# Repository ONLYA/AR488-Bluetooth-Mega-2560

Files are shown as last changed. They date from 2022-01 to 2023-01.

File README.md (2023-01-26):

View this project on [CADLAB.io](https://cadlab.io/project/26454). 

# AR488 Bluetooth Mega 2560
 Source code and KiCad PCB design files for AR488 with Arduino Mega 2560

This board is capable to communicate IEEE-488 protocol between the instrument and a PC. The communication can be with a USB cable or battery-power Bluetooth communication.
The firmware is from https://github.com/Twilight-Logic/AR488. Thanks to his help for this hardware project.

## Please do not use the previous two releases as they have wrong connection and will make your board not working.
Firmware is in folder `AR488-firmware`. The Schematic and PCB files are edited with KiCad 6. BOM is `AR488-Bluetooth-BOM.csv` (#todo)Gerber Files are compressed in `AR488-Gerber.zip`.

You can find the chips here: [SN75160BN](https://www.mouser.co.uk/ProductDetail/Texas-Instruments/SN75160BN?qs=Dqy2GfToSoSUifmRVz6Aqg%3D%3D) and [SN75161BN](https://www.mouser.co.uk/ProductDetail/Texas-Instruments/SN75161BN?qs=Dqy2GfToSoS%252BO4WL2FUX5A%3D%3D).

The GPIB connector I use: [112-024-213R001](https://www.mouser.co.uk/ProductDetail/NorComp/112-024-213R001?qs=IGgAdOvCTsR9oVdHJ26vTQ%3D%3D). Please note that this is a *female* connector, so you will need a GPIB male-male cable.

The Level Shifter (U3) was purchased from [here](https://www.amazon.co.uk/gp/product/B082F6BSB5/ref=ppx_yo_dt_b_asin_title_o09_s00?ie=UTF8&psc=1). It is currently out of stock. However, there are a lot of similar devices. I believed you can easily find an alternative.
The Bluetooth Module (J3) was purchased from [here](https://www.amazon.co.uk/gp/product/B0722MD4FY/ref=ppx_yo_dt_b_asin_title_o02_s00?ie=UTF8&psc=1). When connect it to J2, the attenna track should face upwards.

Connect either JP1 or JP2 to configure whether the DC pin of SN75161BN is connected to REN or Arduino D5. Default should connect JP2. If you want to connect DC-REN, please change that in the `AR488_config.h`.

Connect JP2, "0" side of JP3 and JP4 as the origin setup. You can change that accordingly with the `AR488_config.h`.

## UPDATE 202201311924
1. The connection to the GPIB connector is corrected. Please do not use the previous two releases as they have wrong connection and will make your board not working.
2. A battery circuit is added.
	- (!! DO NOT CONNECT BATTERY IF THE DEVICE IS POWER BY USB OR POWER JACK !!)
	- It accepts voltage range from 3V to 5V. Two AAA batteries are ideal. The SPDT switch will turn on the device.
	- A Boost Switching DC-DC IC (XC9141B50CMR-G)(U4) is used to power the arduino and device.
	- A comparator (U5)(MCP65R41T-1202E/CHY) is used to compare the battery voltage to the 1.21V reference voltage. When the battery voltage drops to the threshold voltage, the "BAT LOW" LED will turn on. The output `CE_OUT` will be driven to LOW.
	- The forward voltage of the "BAT LOW" LED should be less than 2.5V. Red, Amber or Yellow LED will work fine.
	- The potentialmeter is to control the voltage input to the comparator. Adjust it according to the battery specification. To adjust properly, connect a power supply to the `BAT+` input and adjust it to the drained battery voltage. Probe the test point TP1. Adjust RV1 until the voltage is 1.21V.
	- JP5 is the chip enable of the DC-DC IC. If it is connected to BATT, the chip will always be enabled. When connected to OUT, the chip will turn on according to the comparator output `CE_OUT`.

PCB images in KiCad 3D Viewer:
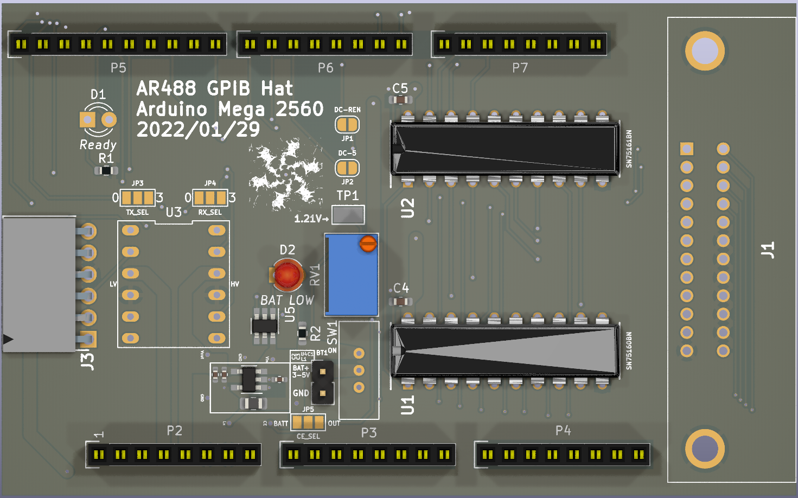
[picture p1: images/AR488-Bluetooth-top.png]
top


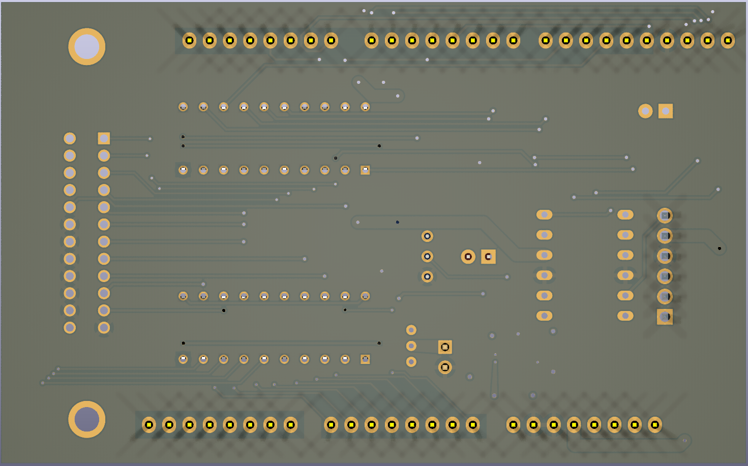
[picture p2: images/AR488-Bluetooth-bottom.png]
bottom


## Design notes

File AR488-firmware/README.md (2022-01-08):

# AR488 Arduino GPIB Interface

The AR488 GPIB controller is an Arduino-based controller for interfacing with IEEE488 GPIB devices via USB. This work was inspired by and has been based on the work originally released by Emanuele Girlando and has been released with his permission.

This sketch represents a rewrite of that work and implements the full set of Prologix ++ commands in both controller and device mode, with the exception of ++help. Secondary GPIB addressing is not yet supported. A number of additional features are provided, for example, a macro feature is provided to allow automation of frequently used command sequences was well as controller and instrument initialisation at startup. As of version 0.48.x, interfacing with SN75160 and SN75161 GPIB transceiver integrated circuits is supported.

To build an interface, at least one Arduino board will be required to act as the interface hardware. Arduinos provide a low cost alternative to other commercial interfaces. Currently the following boards are supported:

<table>
<tr><td><i>MCU</i></td><td><i>Board</i></td><td><i>Serial Ports</i></td><td><i>Layouts</i></td></tr>
<tr><td>328p</td><td>Uno R3</td><td>Single UART shared with USB</td><td>Layout as per original project by Emanuelle Girlando</td></tr>
<tr><td>328p</td><td>Nano</td><td>USB/Single UART shared with USB</td><td>Identical to Uno</td></tr>
<tr><td>32u4</td><td>Micro</td><td>USB/CDC+1 UART</td><td>Compact layout by Artag, designed for his back-of-IEEE488-plug adapter board</td></tr>
<tr><td>32u4</td><td>Leonardo R3</td><td>USB/CDC+1 UART</td><td>Identical to UNO</td></tr>
<tr><td>2560</td><td>Mega 2560</td><td>4 x UART, Serial0 shared with USB</td><td>D - (default) using pins on either side of board<br>E1 - using the first row of end connector<br>E2 - using the second row of end connector</td></tr>
</table>

Uno and Nano boards are both based around the ATmega328p micro-controller and have similar pin-out and features. Only two pins (6 & 13) remain spare as the remainder are all used to interface with the GPIB bus. The Micro and Leonardo are based around the ATmega32u4 micro-controller. On the Micro, all GPIO pins are used so none remain spare. The Leonardo R3 uses the same layout as the Uno leaving the same two pins (6 & 13) spare. The Mega 2560 costs slightly more but has a design and layout that includes considerably more control pins, additional serial ports and a more powerful ATmega2560 MCU. It therefore provides greater flexibility and potential for further expansion. Currently, 3 layouts are provided for the AtMega2650 using either the lower numbered pins on the sides of the board (<D>efault), the first row of pins of the two row header at the end of the board (E1), or the second row of the same header (E2). This provides some flexibility and allows various displays and other devices to be connected if desired. Please be aware that when using the <D>efault layout, pins 16 and 17 that correspond to TXD2 and RXD2 (Serial2) cannot be used for serial communication as they are used to drive GPIB signals, however serial ports 0, 1 and 3 remain available for use. Layouts E1 and E2 do not have the same restriction.

Including the SN7516x chipset into the interface design will naturally add to the cost, but has the advantage of providing the full 48mA drive current capacity regardless of the capability of the Arduino board being used, as well as providing proper tri-state output with Hi-Z when the board is powered down. The latter isolates the Arduino micro-controller from the GPIB bus when the interface is powered down, preventing GPIB bus communication problems due to 'parasitic power' from signals present on the GPIB bus, thereby allowing the interface to be safely powered down while not in use. Construction will involve adding a daughter-board between the Arduino GPIO pins and the GPIB bus. This could be constructed using prototyping board or shield, or custom designed using KiCad or other PCB layout design software.

To use the sketch, create a new directory, and then unpack the .zip file into this location. Open the main sketch, AR488.ino, in the Arduino IDE. This should also load all of the linked .h and .cpp files. Review Config.h and make any configuration adjustment required (see the 'Configuration' section of the AR488 manual for details), including the selcetion of the board layout selection appropriate to the Arduino board that you are using. Set the target board in Board Manager within the Arduino IDE (Tools => Board:), and then compile and upload the sketch. There should be no need to make any changes to any other files. Once uploaded, the firmware should respond to the ++ver command with its version information.

Please note that Arduino Micro (and other 32u4 boards, e.g. Leonardo) do not automatically reset when a connection is made to the serial port. The Arduino IDE takes care of the programming process via USB which should work normally. Some Micro boards may not have a reset button, in which case the reset pin need to be briefly shorted to ground by some other means. When using the Arduino IDE on Linux (Linux Mint and possibly other Ubuntu derivatives), the modemmanager service must be disabled, otherwise it will interfere with the programming process and the boards will be rendered inaccessible via USB. If this curers, then the board can be returned to normal working by uploading a bootloader to it using an AVR programmer. This issue does not seem to affect Uno, Nano or Mega 2560 boards.

Unless some form of shield or custom design with integral IEEE488 connector is used, connecting to an instrument will require a 16 core cable and a suitable IEEE488 connector. This can be salvaged from an old GPIB cable or purchased from various electronics parts suppliers. Searching for a 'centronics 24-way connector' sometimes yields better results than searching for 'IEEE 488 connector' or 'GPIB connector'. Details of interface construction and the mapping of Arduino pins to GPIB control signals and data bus are explained in the "Building an AR488 GPIB Interface" section of the <a href="https://github.com/Twilight-Logic/AR488/blob/master/AR488-manual.pdf">AR488 Manual</a>.
 
Commands generally adhere closely to the Prologix syntax, however there are some minor differences, additions and enhancements. For example, due to issues with longevity of the Arduino EEPROM memory, the ++savecfg command has been implemented differently to save EEPROM wear. Some commands have been enhanced with additional options and a number of new custom commands have been added to provide new features that are not found in the standard Prologix implementation. Details of all commands and features can be found in the Command Reference section of the <a href="https://github.com/Twilight-Logic/AR488/blob/master/AR488-manual.pdf">AR488 Manual</a>.

Once uploaded, the firmware should respond to the ++ver command with its version information.

<b><i>Wireless Communication:</i></b>

The 32u4 and mega 2560 boards have additional serial ports which can be used to connect the ESP8266 WiFi add-on or the HC05 bluetooth module. The firmware sketch supports auto-configuration of the Bluetooth HC05 module, the details of which can be found in the <a href="https://github.com/Twilight-Logic/AR488/blob/master/AR488-Bluetooth.pdf">AR488 Bluetooth Support</a> supplement. It is also possible to use a HC06 module, but since this module is capable of operating in slave mode only, automatic configuration is not possible. It will therefore need to be configured manually.

Using these wireless modules in conjunction with the Uno or Nano is not advised as the only available serial UART is also used for USB communication. Serial protocols were not designed to accomodate multiple devices on a single UART. Communication problems may arise when both USB and a serial device on RX0/TX0 are connected and communicating with the MCU at the same time. It is possible instead to use SoftwareSerial (TX = pin 6, RX = pin 13) although at a speed of no more than 57600 baud.

The ESP32 is not supported as yet, but work is progressing to add this to the list of supported boards.

<b><i>Obtaining support:</i></b>

In the event that a problem is found, this can be logged via the Issues feature on the AR488 GitHub page. Please provide at minimum:

- the firmware version number
- the type of board being used
- the make and model of instrument you are trying to control
- a description of the issue including;
- what steps are required to reproduce the issue

Comments and feedback can be provided here:<BR>
https://www.eevblog.com/forum/projects/ar488-arduino-based-gpib-adapter/

<b><i>Acknowledgements:</i></b>
<table>
<tr><td>Emanuelle Girlando</td><td>Original project for the Arduino Uno</td></tr>
<tr><td>Luke Mester</td><td>Testing of original Uno/Nano verions against Prologix</td></tr>
<tr><td>Artag</td><td>Porting to the Arduino Micro (32u4) board</td></tr>
<tr><td>Tom DG8SAQ</td><td>Plotting and printing</td></tr>
</table>

Also, thank you to all the contributors to the AR488 EEVblog thread for their suggestions and support.

The original work by Emanuele Girlando is found here:<BR>
http://egirland.blogspot.com/2014/03/arduino-uno-as-usb-to-gpib-controller.html

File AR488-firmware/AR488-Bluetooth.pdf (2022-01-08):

## AR488 Bluetooth support

Bluetooth is a common short range wireless connection technology for connecting devices and sending data. Bluetooth devices can typically communicate over distances not exceeding 10 metres, although some devices can communicate over greater distances. In order to communicate with each other, Bluetooth devices must be paired. Once paired, the device facilities can be discovered and a connection established.

Bluetooth transceiver modules such as the HC05 and HC06 can be connected to an Arduino quite easily and manually configured to provide a wireless connection in place of the USB cable. These boards come as either the transceiver board itself with soldered edge connectors only and requiring a DC 3.3V supply, or, mounted on an “adapter” or “breakout” board (as shown opposite) with external pin connectors at one end and which can be supplied directly with 5V.

The AR488 supports auto-configuration of the HC05 Bluetooth

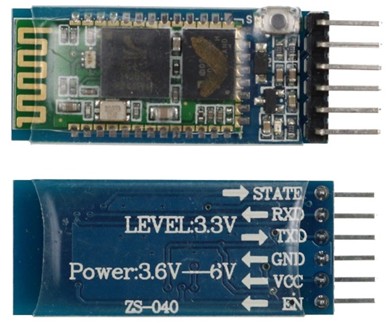
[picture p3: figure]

breakout board for Arduino. This board can be just connected to the serial port of the Arduino and the configuration set in AR488_Config.h file. The HC05 board will be then configured automatically on start-up. Ideally the board would be connected to the RX and TX pins of a second serial port, e.g. Serial1 on the 32u4 or Serial1/Serial3 on the Mega 2560. The HC06 module does not support master mode, so auto-configuration is not possible with the HC06. However, either the HC05 and HC06 breakout boards or modules can be configured manually if required and used with the AR488.

The HC05 and HC06 modules have a very similar appearance, but the HC05 can be identified by the fact that it has six pins, while the HC06 has only four. There is no EN or STATUS pin on the HC06.

Unlike most Arduino boards, which are supplied with 5V DC as is common to
all USB devices, the HC05 module requires a 3.3V supply. The “adapter” or
“breakout” board provides a 3.3V regulator for this purpose so it can be supplied with 5V, however, the serial input and output as well as the enable
pin still operate at a 3.3V signalling level as indicated by the ‘LEVEL:3.3V’
marked on the board. Applying 5V to these pins can damage the module and
while some tutorials do show these connected directly to the RX/TX pins on the Arduino, this is not recommended and ideally, a level shifter should be used. This can be made quite easily but ready made boards such as the one shown opposite can also be purchased. Such boards usually have 4 “channels” (HV1-HV4 and corresponding LV1-LV4) which is sufficient for our purposes. There are 4 transistors across the centre and 6 soldered connectors along each edge. They board is usually supplied with a row of pins which can be soldered to the connectors if required or wires can be soldered to the board directly. The HV side is connected to the Arduino and the LV side to the HC05.
- 1 -

The level shifter board is easily supplied from the 5V and 3.3V pins on the Arduino with the 5V pin connected to HV and 3.3V pin connected to LV. The GND connector must be connected to the Arduino GND pin as well as the HC05 GND pin. Either one or both GND connectors on the level shifter can be used as they are linked together. The Arduino TX, RX and enable pin connections are made to one of the HV side channels and connections to the HC05 Bluetooth board are made to the corresponding LV side channel. It does not matter which actual channel numbers are used for which function so long as TX on the Arduino connects with RX on the HC05, RX on the Arduino to the TX on the HC05 and EN on the HC05 connects to the GPIO pin configured for this purpose on the Arduino, all connections being made via correspondingly numbered HV/LV channel on the level shifter.

The HC05 breakout board requires 5 connections in total including 5V DC power to VCC, GND, TXD, RXD and EN or “Enable” that enables the Arduino master mode required for configuration. In the example shown below, the EN pin is connected via the level shifter to pin 6 on the Uno, but any spare Arduino GPIO pin can be used. The pin marked STATE is left disconnected.

Factory set serial communication speeds also seem to vary and while some modules operate at 38400 baud, others seem to require a 9600 baud connection. The AR488 Bluetooth module will automatically detect the default speed and set it to the configured speed.

The Bluetooth HC05 transceiver breakout board requires three channels. The diagram below is an example of how an Arduino Uno might be wired to the HC05 module:

- 2 -

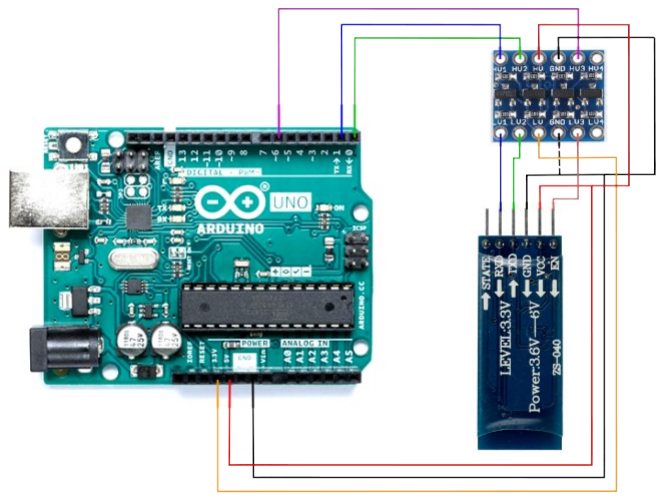
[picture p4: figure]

Diagram of the Arduino to HC05 connections

Clones of the Pro Micro board do not have a 3.3V regulator on board, so a 3.3V supply will have to be provided separately.

Enabling Bluetooth on the AR488

The Bluetooth feature is disabled by default, but can be enabled by removing the comment characters ‘//’ preceding the definition for AR_BT_EN within the “Bluetooth (HC05) support” section in the AR488_Config.h file:

//#define AR_BT_EN 6 | // Bluetooth enable and control pin
#ifdef AR_BT_EN

#define AR_BT_BAUD 115200 // Bluetooth module preferred baud rate #define AR_BT_NAME "AR488-BT" // Bluetooth device name

#define AR_BT_CODE "488488" // Bluetooth pairing code

#endif

- 3 -

so that it becomes:

#define AR_BT_EN 6 | // Bluetooth control enable pin

#ifdef AR_BT_EN

#define AR_BT_BAUD 115200 // Bluetooth module baud rate #define AR_BT_NAME "AR488-BT" // Bluetooth device name #define AR_BT_CODE "488488" // Bluetooth pairing code

#endif

This will activate the Bluetooth auto-configuration. Set the pin number to the number of the GPIO pin that will be used to control the EN pin on the HC05.

The default baud rate can be set to anything that the Arduino and the HC05 board will support. Please note that there are no double quotes around this parameter.

The default pairing device name is AR488-BT, but this can be changed to anything desired by the following line:

#define AR_BT_NAME "AR488-BT"

where AR488-BT is replaced by whatever string is desired.

The default paring code is 488488, but this can be changed by modifying the number in quotes after the AR_BT_CODE keyword:

#define AR_BT_CODE “488488”

The code must be enclosed in double quotes and must be at least 6 digits long.

The diagram above shows a Uno wired up to a HC05 connector. It should be noted that the Uno and Nano have only one UART and the 328p has only one set of Tx/Rx pins. Since the serial protocol was designed for 1:1 connections, on these Arduino boards, USB and Bluetooth should not be used at the same time. The sketch must be uploaded to the Arduino prior to the The HC05 being connected to the Tx/Rx pins, otherwise the upload will fail. Once the sketch has been uploaded, the module can then be connected and both Arduino and HC05 module powered up. This is not a problem where an Arduino has additional serial ports available such as the 32u4 and the Mega 2560. The HC05 can be connected to a secondary port and the USB port used to program as normal.

Setting up the hardware

Once the sketch has been configured and uploaded to the board and the HC05 Bluetooth module connected up, the AR488 can be powered up. On start-up it will automatically detect the baud rate of the HC05 module and configure it. By default, the AR488 will appear as a Bluetooth device called AR488-BT, but otherwise should appear with the configured name. On Windows, it may appear as “Other device” until the screen is refreshed.

- 4 -

The first time that the HC05 board is used, the LED on the HC05 board will initially blink slowly for a few seconds. The internal LED on the Arduino should then blink twice to indicate that the baud rate has been successfully detected, and following that, 3 more times to indicate that configuration has been successful. A few moments after this, the LED on the HC05 should begin flashing rapidly to indicate that it has switched to slave mode and is ready for pairing.

On subsequent power-up, the LED on the HC05 board will initially blink slowly for a few seconds. The Arduino internal LED will blink twice to indicate successful auto-detection of the baud rate, and then once to indicate that the configuration has not changed. The LED on the HC05 will then blink rapidly to indicate that it has switched to slave mode and the module is ready for pairing.

If the any of the Bluetooth configuration parameters are changed in the sketch, the AR488 will perform the auto-configuration process again. If nothing has changed, the auto-configuration process is skipped and the HC05 board just goes into slave mode.

Once paired, the LED on the HC05 board will blink twice every few seconds.

- 5 -

### Pairing the AR488 Interface with Bluetooth

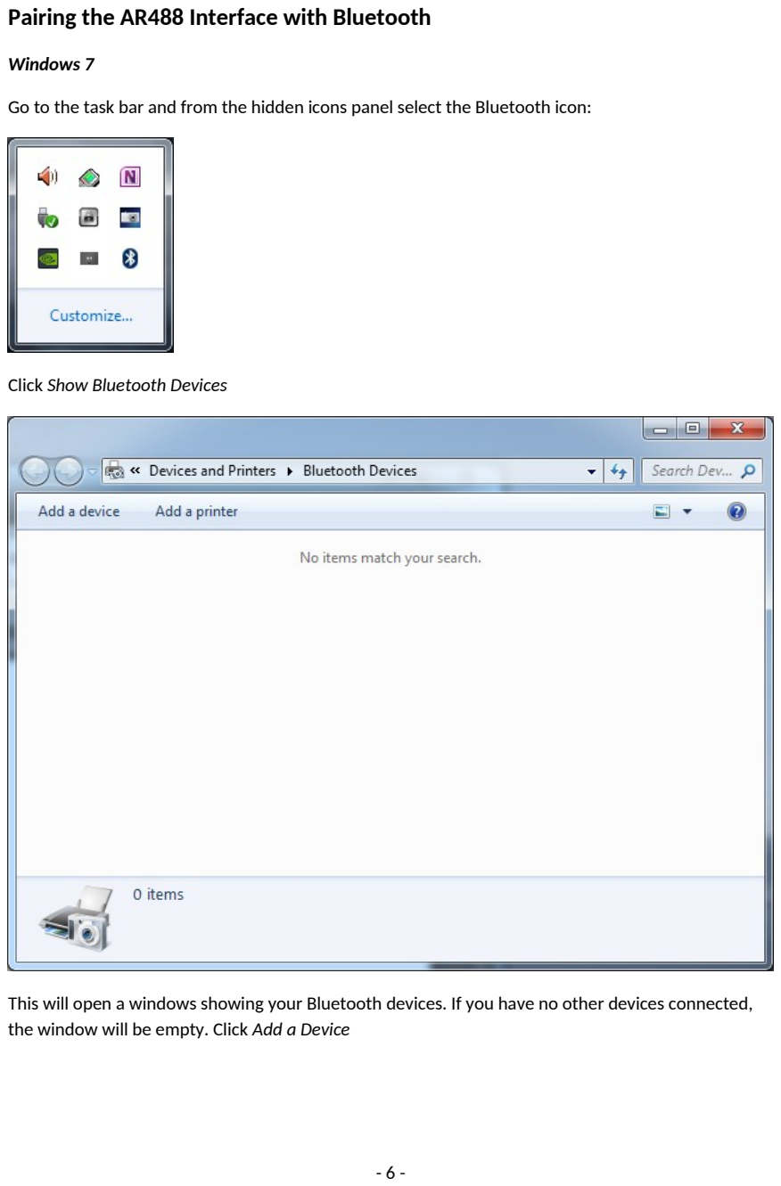
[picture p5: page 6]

Windows 7

Go to the task bar and from the hidden icons panel select the Bluetooth icon:

Click Show Bluetooth Devices

This will open a windows showing your Bluetooth devices. If you have no other devices connected, the window will be empty. Click Add a Device

- 6 -

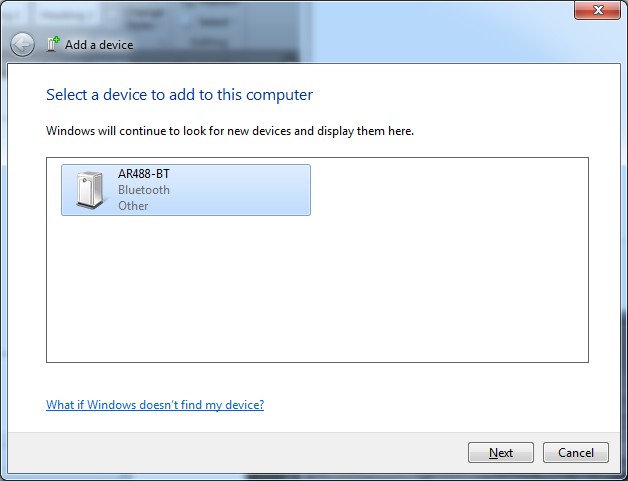
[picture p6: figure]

After a few moments, the AR488 -BT device should be detected. Please not that it may initially show simply as Other, but when you click on it, the name should be updated to AR488-BT.

Click the Next button. This will momentarily show a Connecting to devices status and then open the Add a Device window:

- 7 -

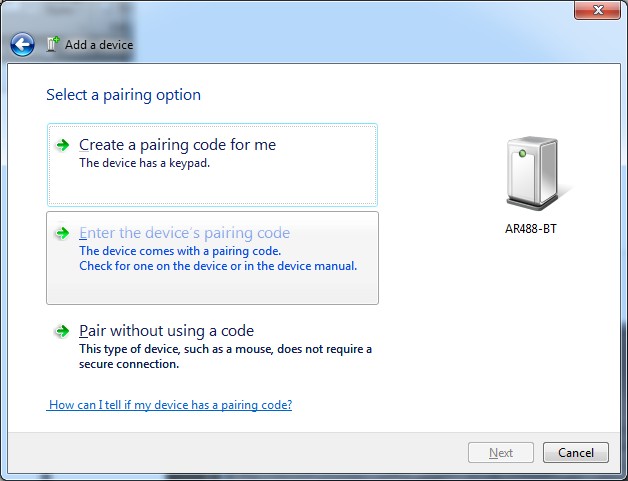
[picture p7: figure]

Select Enter the device’s pairing code panel. The next dialogue will prompt you to enter the device pairing code:

- 8 -

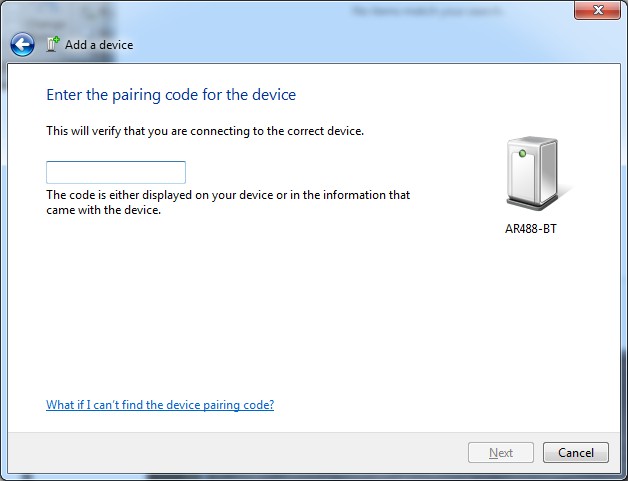
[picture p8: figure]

Enter the configured pin code, for example 488488 and then click Next.

Windows should now connect the device and install a virtual serial port. A confirmation should now be displayed to indicate that the device has been successfully paired:

- 9 -

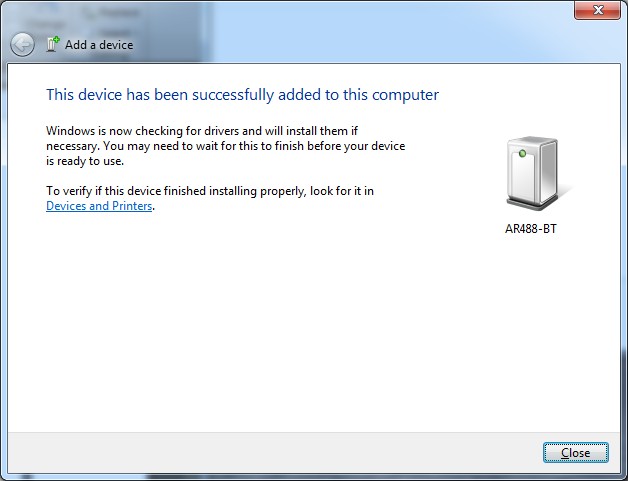
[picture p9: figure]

After clicking Close, you should now see the connected device:

- 10 -

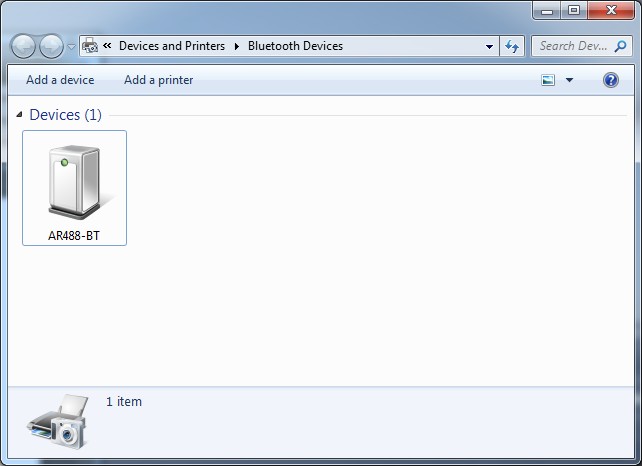
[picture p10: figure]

Double click on the device and open the Hardware tab:

- 11 -

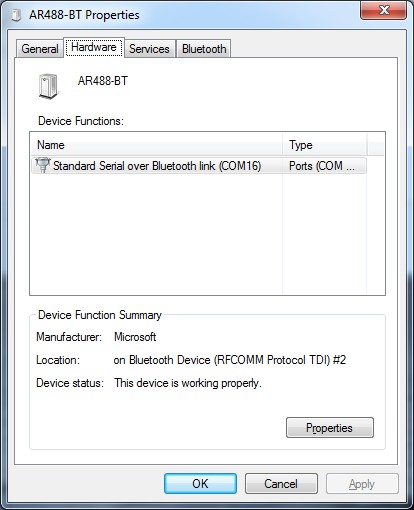
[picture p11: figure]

This should display the virtual serial port that has been assigned to the device, e.g. in the above example it is COM16.

Open a terminal session to the device using the baud rate that was configured in the sketch:

- 12 -

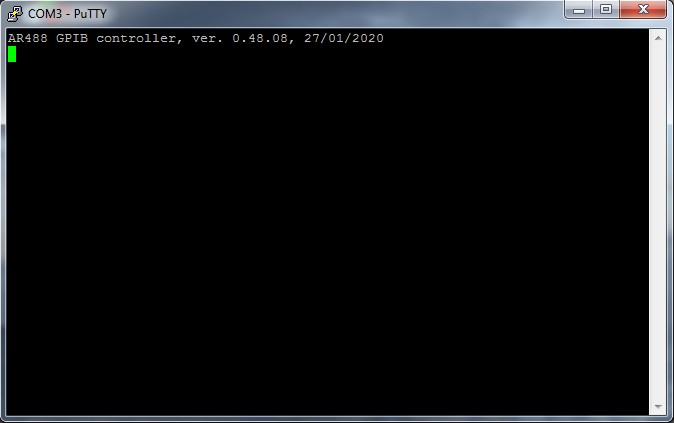
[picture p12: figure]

The interface should respond as normal.

- 13 -

### Windows 10

Go to Windows Settings (the cog icon on the left of the windows menu) and select Devices:

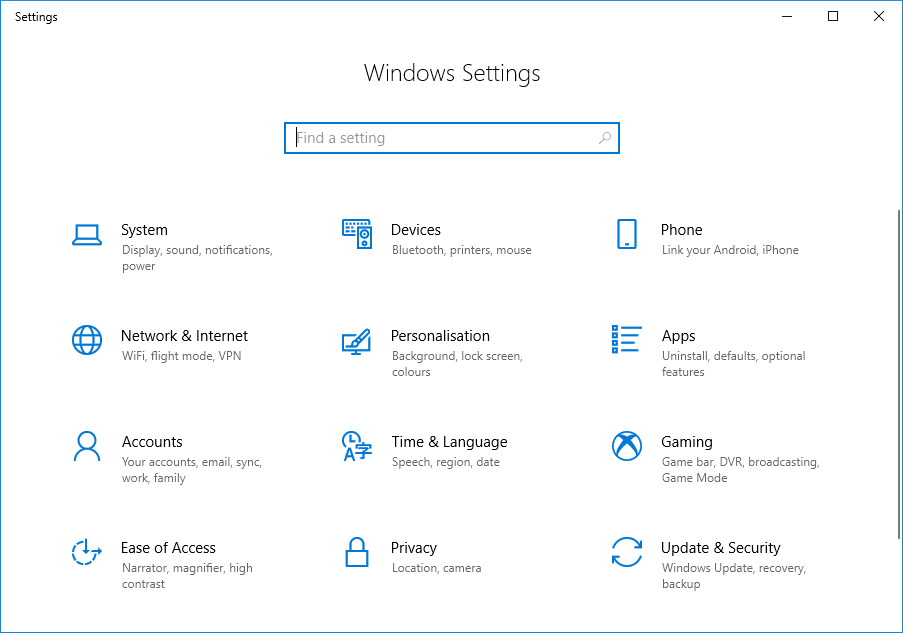
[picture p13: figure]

This opens the Bluetooth & other devices dialogue:

- 14 -

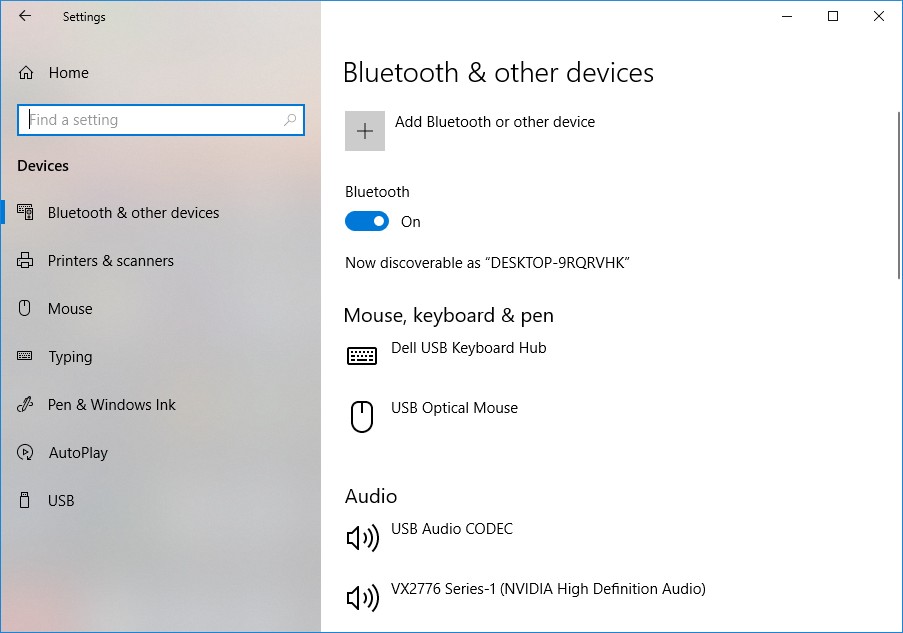
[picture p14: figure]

Make sure that Bluetooth is turned on. Click Add Bluetooth or other device. This will open another Window:

- 15 -

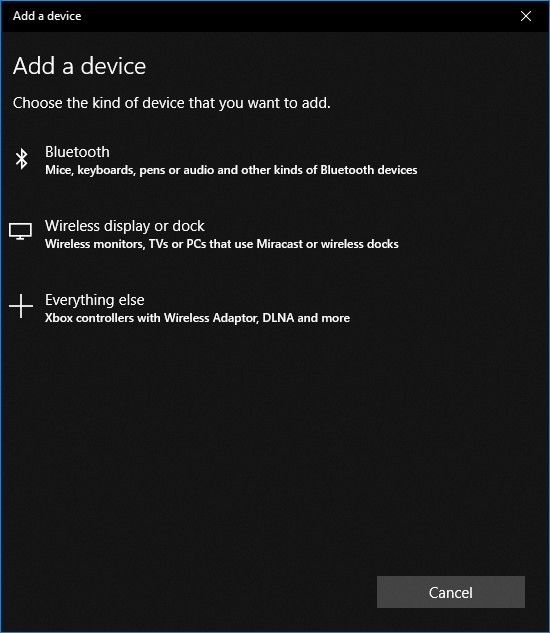
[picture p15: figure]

Click Bluetooth. Windows should now look for devices. It should momentarily show the AR488-BT device as unknown device, but this should quickly change to AR488-BT.

- 16 -

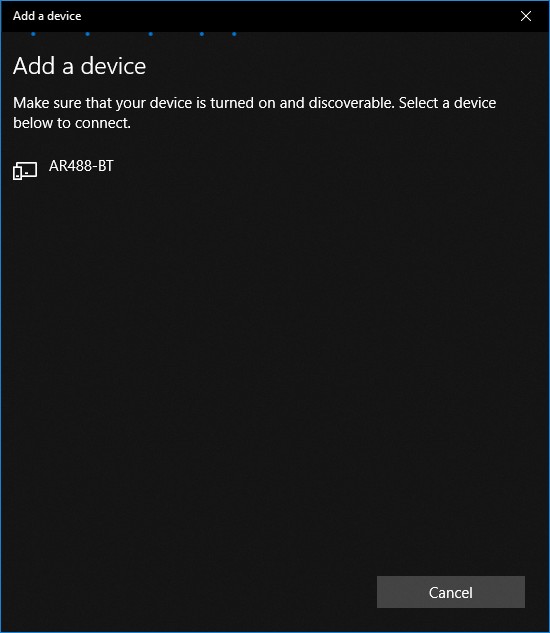
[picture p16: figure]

Click the AR488-BT device. After a few moments prompt will appear requesting the pin.

- 17 -

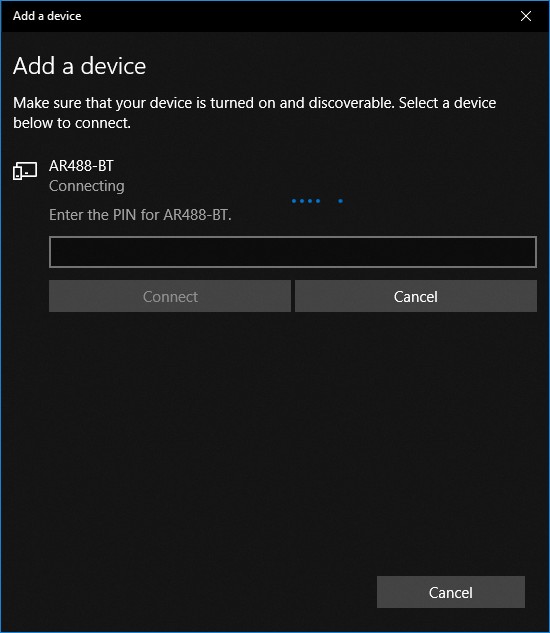
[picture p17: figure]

Enter the pin and click Connect. If it times out, the dialogue may show “Try connecting your device again”. Click on the device again to try once more. Once successful, this will be clearly confirmed:

- 18 -

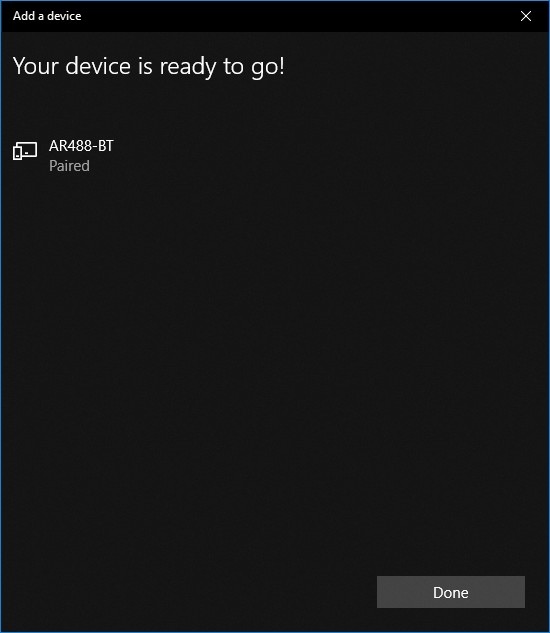
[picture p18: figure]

The device status should now be shown as Paired. Click the Done button to close the device configuration window.

Back on the Bluetooth & other devices window, scroll down. The AR488-BT device should be listed under Other Devices. The window can now be closed.

Right-click This PC and select Manage. Click on Device Manager and expand the Port (COM & LPT) section. The device should be shown as Standard Serial over Bluetooth link (COMx) where COMx will be the assigned COM port.

Open a terminal session to the assigned COM port and test communication with the device:

- 19 -

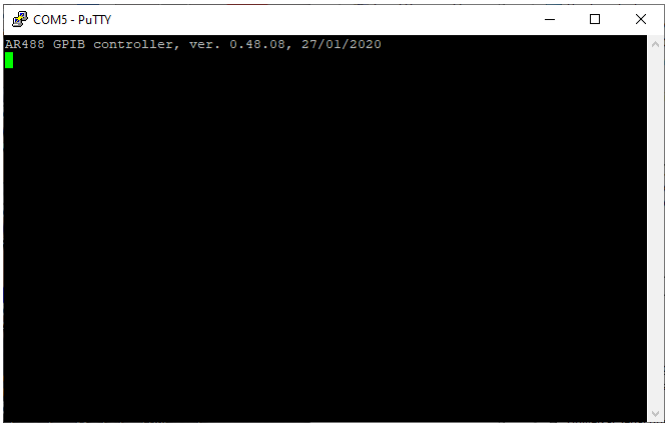
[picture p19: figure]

The interface should respond as normal.

- 20 -

### Linux MINT

These instructions should work on Linux Mint 19 and above and probably Ubuntu. Depending on your distro of Linux, you may need to download the bluez or bluez5 tools package or compile it from source. On Linux Mint 19 and likely Ubuntu this will be installed by default or can be readily downloaded from the repository using apt or Software Manager.

Make sure that your Bluetooth dongle or built-in device is working correctly on your computer or laptop.

Make sure that Bluetooth is turned on and your system can identify your Bluetooth hardware.

Once you have confirmed that your Bluetooth hardware is working, open a terminal and at the command prompt type:

% bluetoothctl

This should list any known Bluetooth devices, show Agent registered at the end of the list, and a [bluetooth]# prompt:

$ bluetoothctl
[NEW] Controller 00:80:98:94:AB:7E agabus [default]
[NEW] Device 78:3A:84:93:BC:B9 iPad
[NEW] Device 10:2F:6B:BD:49:F1 N930 phone
Agent registered
[bluetooth]#

If your device is not listed, then at the prompt type:

scan on

This should initiate a scan for new devices. In a few seconds any new devices should be listed:

[bluetooth]# scan on
Discovery started
[CHG] Controller 00:80:98:94:AB:7E Discovering: yes
[NEW] Device 98:D3:31:F9:4E:6D AR488-BT

The AR488-BT device should be detected and its mac address listed.

To pair the device type:

[bluetooth]# pair 98:D3:31:F9:4E:6D

where the MAC address is the address of YOUR Bluetooth device. The bluetoothctl utility should respond with something like:

[bluetooth]# pair 98:D3:31:F9:4E:6D
Attempting to pair with 98:D3:31:F9:4E:6D
[CHG] Device 98:D3:31:F9:4E:6D Connected: yes
- 21 -

Request PIN code
[AR481m[agent] Enter PIN code:

Enter the pairing code configured on the HC05 device. The default pairing code is 488488, but if a custom six digit code has been configured then that should be provided instead. The bluetoothctl utility will now attempt to pair with the device. If successful, the output should be something like:

[AR481m[agent] Enter PIN code: 488488
[CHG] Device 98:D3:31:F9:4E:6D UUIDs: 00001101-0000-1000-8000-00805f9b34fb [CHG] Device 98:D3:31:F9:4E:6D ServicesResolved: yes
[CHG] Device 98:D3:31:F9:4E:6D Paired: yes
Pairing successful
[AR488-BT]#

At this point the device is paired, but there is no serial port associated with it. Another tool called rfcomm can be used to associate a serial port with the Bluetooth device. First exit the bluetoothctl utility by typing:

[bluetooth]# exit

The utiltity will respond with the following and return to the system prompt:

Agent unregistered
[DEL] Controller 00:80:98:94:AB:7E agabus [default]
$

Type the following to associate a serial port with the Bluetooth device:

$ sudo rfcomm bind 0 98:D3:31:F9:4E:6D 1

You may be prompted for the sudo password. After this has command has completed, a serial port called /dev/rfcomm0 will be created. To confirm that the port binding has been established can be done with the following command:

$ ls /dev/rfcomm*
/dev/rfcomm0

The repose confirms that the port is now available, so we can open a TTY terminal such as PuTTY and try to establish a connection to it:

- 22 -

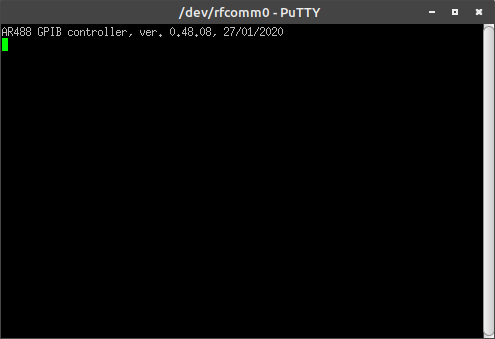
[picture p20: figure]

The terminal should connect and the device should respond in the usual manner.

To unbind the /dev/rfcomm0 port at the end of the session, from the system $ prompt type:

$ sudo rfcomm unbind 0 98:D3:31:F9:4E:6D 1

Further troubleshooting information

A noteworthy point is that bluetoothctl is launched while a connected session is in progress, then the prompt will show the name of the currently connected device:

[AR488-BT]#

To get further information about a device in bluetoothctl, when at the [bluetooth]# prompt type:

info 98:D3:31:F9:4E:6D

where the MAC address is the address of the device you would like further information on. The program should respond with something like this:

[bluetooth]# info 98:D3:31:F9:4E:6D
Device 98:D3:31:F9:4E:6D (public)
Name: AR488-BT
Alias: AR488-BT
Class: 0x00001f00
- 23 -

Paired: yes
Trusted: no
Blocked: no
Connected: yes
LegacyPairing: yes
UUID: Serial Port | (00001101-0000-1000-8000-00805f9b34fb)
[bluetooth]#

You can also list all the devices that have been paired with:

[bluetooth]# paired-devices
Device 98:D3:31:F9:4E:6D AR488-BT
Device 10:2F:6B:BD:49:F1 N930 phone [bluetooth]#

To remove a paired device type:

[bluetooth]# remove 98:D3:31:F9:4E:6D [DEL] Device 98:D3:31:F9:4E:6D AR488-BT Device has been removed
[bluetooth]#

If bluetoothctl responds with:

Failed to start discovery: org.bluez.Error.NotReady

This may indicate that the device is not powered on or blocked. Try this first:

[bluetooth]# power on

If this reports:

Failed to set power on: org.bluez.Error.Blocked

Then exit bluetoothctl and run this command to check for blocked devices:

$ rfkill list
1: hci0: Bluetooth
Soft blocked: yes
Hard blocked: no

If, as shown above, Bluetooth is ‘Soft blocked’ then it might be possible to unblock it with:

rfkill unblock all

Now run bluetoothctl again.

Otherwise check that device drivers were properly loaded.

- 24 -

If a device is ‘Hard blocked’ then there is a hardware problem, e.g. a toggle switch may be in the wrong position, faulty cable, power off etc. or the device may be disabled in BIOS.

- 25 -

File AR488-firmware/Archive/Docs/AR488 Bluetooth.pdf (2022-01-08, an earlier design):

## AR488 BlueTooth

Bluetooth is a common short range wireless connection technology for connecting devices and sending data. Bluetooth devices can typically communicate over distances not exceeding 10 metres, although some devices can communicate over greater distances. In order to communicate with each other, Bluetooth devices must be paired. Once paired, the device facilities can be discovered and a connection established.

The AR488 supports Bluetooth by means of the HC05 Bluetooth module for Arduino. Unlike the Arduino Uno or Nano boards, which operate at 5v DC which is common to all USB devices, the HC05 operates at 3.3v. However, HC05 modules can be purchased already mounted on a voltage converter host board which can be supplied with 5v. Such boards usually have 6 pins along one edge for easy connection to the Arduino. Although these boards can be supplied with 5v DC, there is usually no voltage conversion
provided for the TXD and RXD pins which also require 3.3v
signalling rather than 5v. Fortunately it is also possible to obtain a


level shifter board at very little cost. These provide a means to shift the 5v to shift 5v logic to 3.3v and vice-versa. The board is easily supplied with 5v and 3.3v from the Arduino board. The Arduino TXD and RXD connections are made to the HV (5v) side, whereas the connections to the HC05 Bluetooth board are
made to the LV (3.3v) side.

The HC05 module should not be confused with the similar HC06 module. While the HC05 module can operate as both slave and master, the HC06 module can operate in slave mode only. Serial communication speeds also seem to vary and while by default some boards operate at 38400 baud, others require a 9600 baud connection.

The HC05 board requires 5 connections in total DC power VCC, GND, TXD and RXD and a control pin (labelled EN) that allows the Arduino to set it in configuration mode. This is connected to pin 6 on the Uno or Nano. The pin marked STATE is left disconnected.

The level onverter board has four transistors across the centre. The 5v supply is connected to GND and HV, whereas the 3.3v supply goes to GND and the LV pin. The ground connections are common so it is not necessary to connect both of them. The 5v logic is connected to the HV side of the board and the 3.3v logic is connected to the LV side of the board. The board has four possible ‘channels’ with the 5v sdide marked HV1-4 and the 3.3v side correspondigly marked LV1-4.

The bluetooth HC05 board requires only two of these. Level shifting for the enable pin is accomplished using a pair of resistors as a voltage divider. It was found that when using the level shifter board, when pin 6 was low, sufficient voltage remained on the EN pin even with a pull-down resistor in place, to prevent the module from switching back to user mode.

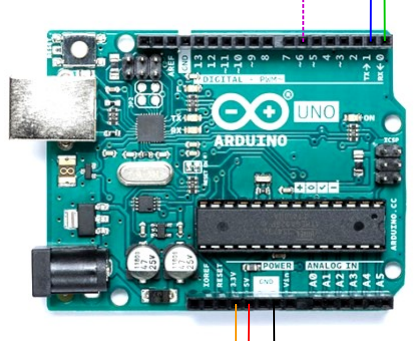
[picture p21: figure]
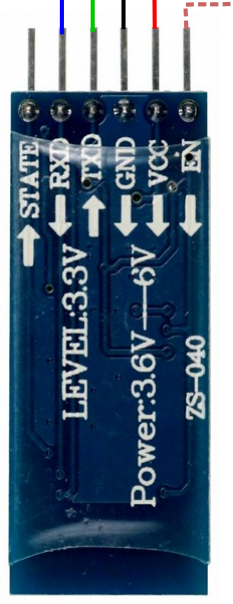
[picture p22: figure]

Diagram of the Arduino to HC05 connections

Enabling Bluetooth on the AR488

The Bluetooth feature is disabled by default, but can be enabled by removing the surrounding comments from the lines within the “Bluetooth Support” section.:

// Bluetooth support
/*
#define AR_BT_EN 6 | // Bluetooth control enable pin

#define AR_BT_NAME "AR488-BT" // Bluetooth device name

#define AR_BT_BAUD "115200" | // Bluetooth module baud rate

#define AR_BT_CODE "488488" | // Bluetooth pairing code

#define LED 13

*/
// Bluetooth support

and changing them to:

R1 | R2

// Bluetooth support
#define AR_BT_EN 6 | // Bluetooth control enable pin

#define AR_BT_NAME "AR488-BT" // Bluetooth device name

#define AR_BT_BAUD "115200" | // Bluetooth module baud rate

#define AR_BT_CODE "488488" | // Bluetooth pairing code

#define LED 13

// Bluetooth support

The default baud rate can be set to anything that the Arduino and the HC05 board will support.

The pairing code should also be uncommented by changing the line:

//#define AR_BTPN “488488”

to:

#define AR_BTPN “488488”

The default paring code is 488488, but this can be changed to any 6 digit number.

Upload the amended sketch prior to connecting the HC05 Bluetooth module, or else disconnect the HC05 Bluetooth module temporarily. Since the UNO and Nano have only one serial port, it is not possible to use Bluetooth and the USB at the same time. Attempting to upload the sketch while the HC05 board is connected to Rx and Tx will result in an error. If this should happen, disconnect the Tx and Rx connections to the HC05 board and try again. Once Bluetooth is set up, it will still be possible to power the board via USB or using the DC input jack on the UNO but it is not possible to communicate via both USB and BlueTooth simmultaneously.

Setting up

Once the sketch has been configured and uploaded to the board, connect up the HC05 Bluetooth module as per the diagram and upload the amended sketch.

Once connected, the AR488 can be powered up and on start-up will automatically detect the baud rate and configure the HC05 module. The AR488 will appear as a Bluetooth device called AR488-BT.

The first time that the HC05 board is used, the LED on the HC05 board will blink slowly for about 10 seconds. While this is happening, the LED on the Arduino should blink twice to indicate that the baud rate has been successfully detected, and then 3 times to indicate that configuration has been successful. A few moments after this, the LED on the HC05 will begin flashing rapidly. At this point, the HC05 is ready for pairing.

Once the HC05 board has been configured, on subsequent power up, the LED on the Arduino will blink twice to indicate baud rate detection, and then just once to indicate that connection has been established. It will then switch into pairing mode and the LED on the HC05 will flash rapidly until connected to a device, such as a PC.

### Pairing the AR488 Interface with Bluetooth

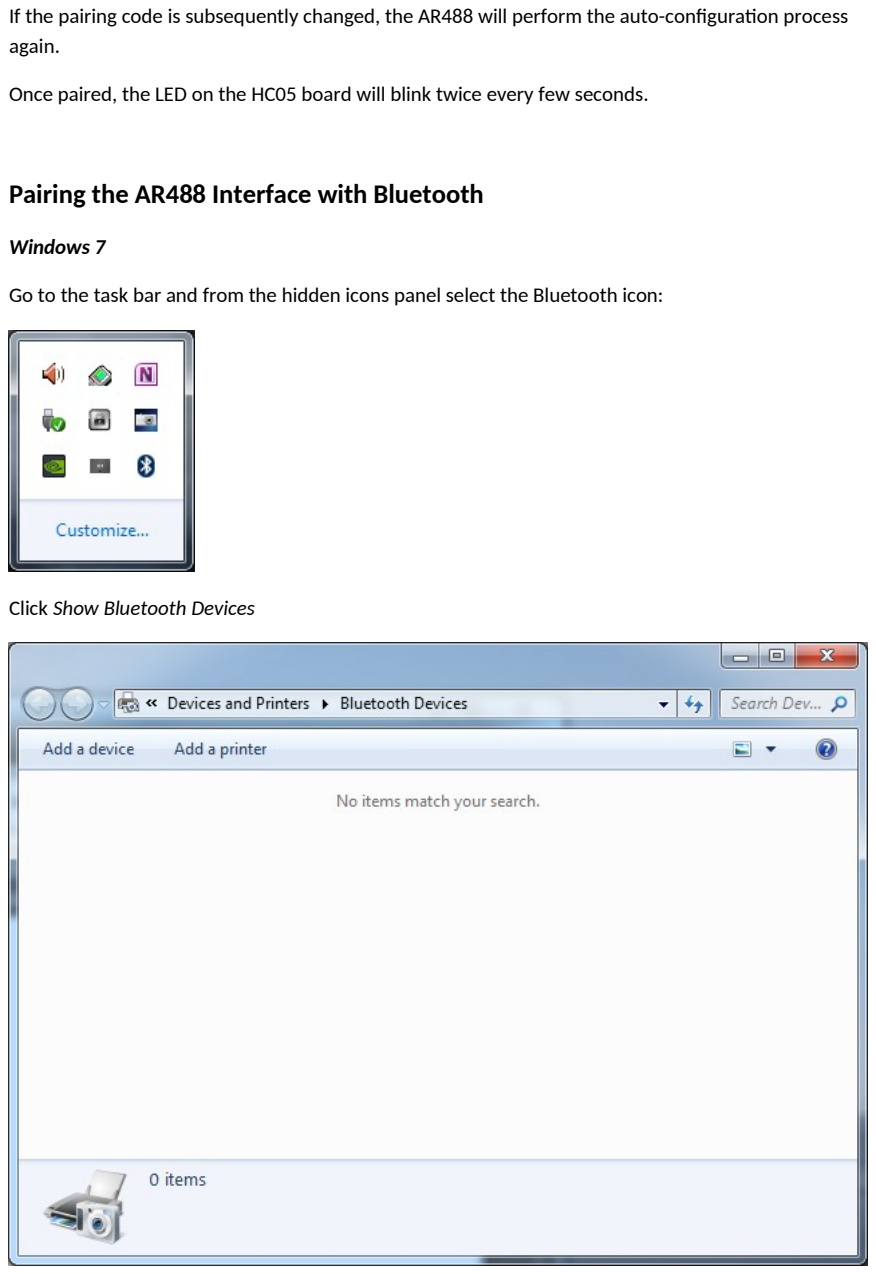
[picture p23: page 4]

If the pairing code is subsequently changed, the AR488 will perform the auto-configuration process again.

Once paired, the LED on the HC05 board will blink twice every few seconds.

Windows 7

Go to the task bar and from the hidden icons panel select the Bluetooth icon:

Click Show Bluetooth Devices

This will open a windows showing your Bluetooth devices. If you have no other devices connected, the window will be empty. Click Add a Device


After a few moments, the AR488 -BT device should be detected. Please not that it may initially show simply as Other, but when you click on it, the name should be updated to AR488-BT.

Click the Next button. This will momentarily show a Connecting to devices status and then open the Add a Device window:


Select Enter the device’s pairing code panel. Te next dialog will prompt you to enter the device pairing code:


Enter the configured pin code, for example 488488 and then click Next.

Windows should now connect the device and install a virtual serial port. A configmation should now be displayed to indicate that the device has been successfully paired:


After clicking Close, you should now see the connected device:


Double click on the device and open the Hardware tab:


This should display the virtual serial port that has been assigned to the device, e.g.in the above example it is COM16.

Open a terminal session to the device using the baud rate that was configured in the sketch:

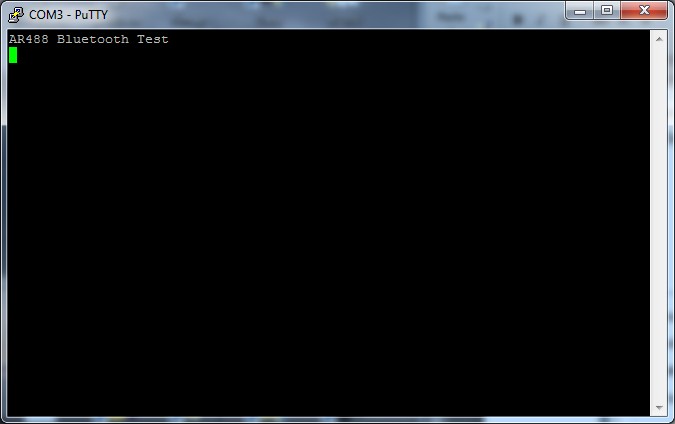
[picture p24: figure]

The interface should respond as normal.

### Windows 10

Go to Windows Settings (cog icon on the left of the windows menu) and select Devices:


This opens the Bluetooth & other devices dialog:


Make sure that Bluetooth is turned on. Click Add Bluetooth or other device. This will open another Window:


Click Bluetooth. Windows should now look for devices. It should momentarily show the AR488-BT device as unknown device, but this should quickly change to AR488-BT.


Click the AR488-BT device. After a few moments prompt will appear requesting the pin.


Enter the pin and click Connect. If it times out, the dialog may show Try connecting your device again. Click on the device again to try once more. Once successful, this will be configmed:


The device status should now be shown as Paired. Click the Done button to close device configuration window.

Back on the Bluetooth & other devices window, scroll down. The AR488-BT device should be listed under Other Devices. The window can now be closed.

Right-click This PC and select Manage. Click on Device Manager and expand the Port (COM & LPT) section. The device should be shown as Standard Serial over Bluetooth link (COMx) where COMx will be the assigned COM port.

Open a terminal session to the assigned COM port and test communication with the device:

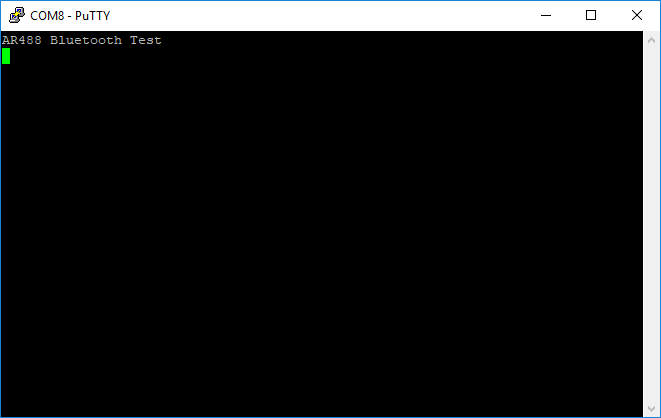
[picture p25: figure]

### Linux MINT

These instructions should work on Linux Mint 19 and above and probably Ubuntu. Depending on your distro of Linux, you may need to download the bluez or bluez5 tools package or compile it from source. On Linux Mint 19 9and likely Ubuntu) this will be installed by default or can be readily downloaded from the repository using apt or Software Manager.

Make sure that your Bluetooth dongle or built-in device is working correctly on your computer or laptop.

Make sure that Bluetooth is turned on and your system can identify your Bluetooth hardware.

Once you have configmed that your Bluetooth hardware is working, open a terminal and at the command prompt type:

% bluetoothctl

This should list any known bluetooth devices, confirm that the Agent is registered and open a [bluetooth]# prompt:

$ bluetoothctl
[NEW] Controller 00:80:98:94:AB:7E agabus [default]
[NEW] Device 78:3A:84:93:BC:B9 iPad
[NEW] Device 10:2F:6B:BD:49:F1 N930 phone
Agent registered
[AR488-BT]#

At the prompt type:

scan on

This should initiate a scan for new devices. In a few seconds any new devices should be listed:

[bluetooth]# scan on
Discovery started
[CHG] Controller 00:80:98:94:AB:7E Discovering: yes
[NEW] Device 98:D3:31:F9:4E:6D AR488-BT

The AR488-BT device should be detected and its mac address listed.

To pair the device type:

pair 98:D3:31:F9:4E:6D

where the MAC address is the address of YOUR bluetooth device. Bluetoothctl should respond with:

[bluetooth]# pair 98:D3:31:F9:4E:6D
Attempting to pair with 98:D3:31:F9:4E:6D
[CHG] Device 98:D3:31:F9:4E:6D Connected: yes
Request PIN code
[AR481m[agent] Enter PIN code:

Enter the pairing code of the HC05 deivce. The default pairing code is 488488, but a custom six digit code can be specified within the sketch. Bluetoothctl will now attempt to pair with the device. If sucessful, the output should be something like:

[AR481m[agent] Enter PIN code: 488488
[CHG] Device 98:D3:31:F9:4E:6D UUIDs: 00001101-0000-1000-8000-00805f9b34fb [CHG] Device 98:D3:31:F9:4E:6D ServicesResolved: yes
[CHG] Device 98:D3:31:F9:4E:6D Paired: yes
Pairing successful
[AR488-BT]#

At this point the device is paired, but we do not yet have a serial port to connect with. We now need to use another tool to create one. First exit bluetoothctl by typeing:

[bluetooth]# exit

The utiltity will respond with the following and return to the system prompt:

Agent unregistered
[DEL] Controller 00:80:98:94:AB:7E agabus [default]
$

Type the following to create the /dev/rfcomm0 device:

sudo rfcomm bind 0 98:D3:31:F9:4E:6D 1

You may be prompted for the sudo password. That the port binding has been established can be verified with:

$ ls /dev/rfcomm*
/dev/rfcomm0

Now that the port is available, we can open a tty terminal such as PuTTY:

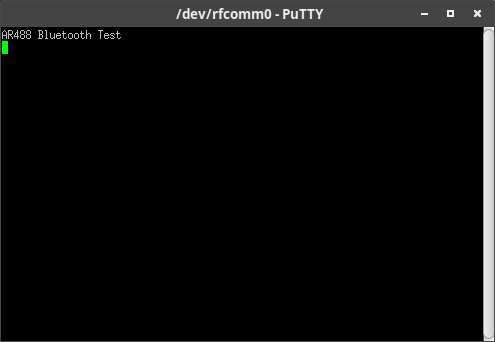
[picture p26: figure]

Further information:

To unbind the /dev/rfcomm0 port, from the system $ prompt type:

sudo rfcomm unbind 0 98:D3:31:F9:4E:6D 1

To get further information about a device from the [bluetooth]# prompt type:

info 98:D3:31:F9:4E:6D

where the MAC address is the address of the device you would like further information on. The program should respond with something like this:

[AR488-BT]# info 98:D3:31:F9:4E:6D
Device 98:D3:31:F9:4E:6D (public)
Name: AR488-BT
Alias: AR488-BT
Class: 0x00001f00
Paired: yes
Trusted: no
Blocked: no
Connected: yes
LegacyPairing: yes
UUID: Serial Port | (00001101-0000-1000-8000-
00805f9b34fb)
[AR488-BT]#

You can also list all the devices you have paired:

[AR488-BT]# paired-devices
Device 98:D3:31:F9:4E:6D AR488-BT Device 10:2F:6B:BD:49:F1 N930 phone [AR488-BT]#

To remove a paired device type:

[bluetooth]# remove 98:D3:31:F9:4E:6D [DEL] Device 98:D3:31:F9:4E:6D AR488-BT Device has been removed
[bluetooth]#

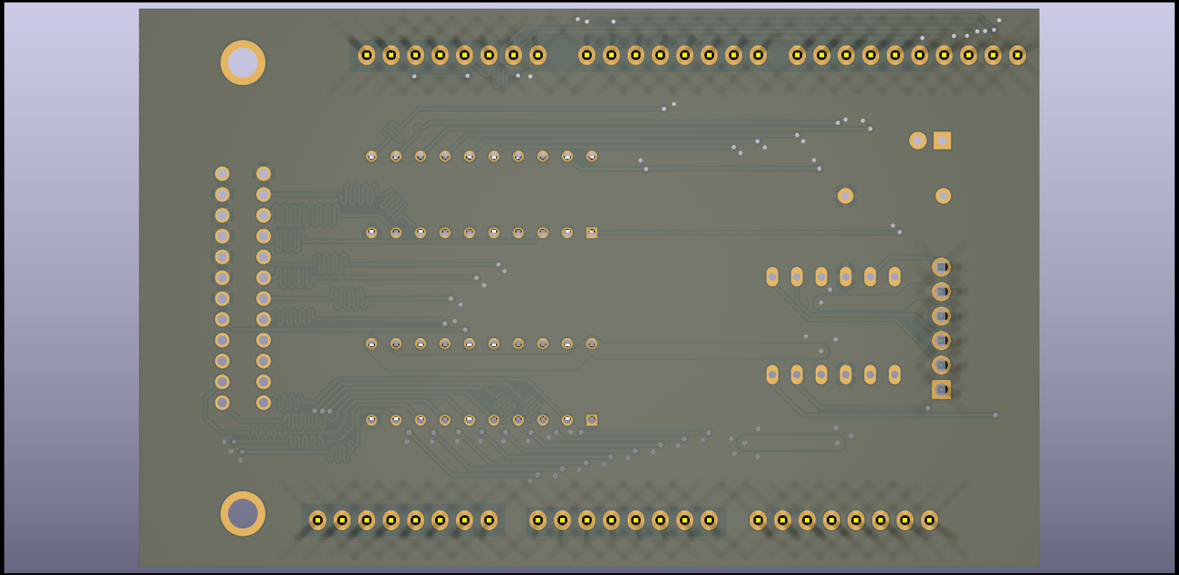
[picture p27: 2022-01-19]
images/AR488-Bluetooth-bottom1.png

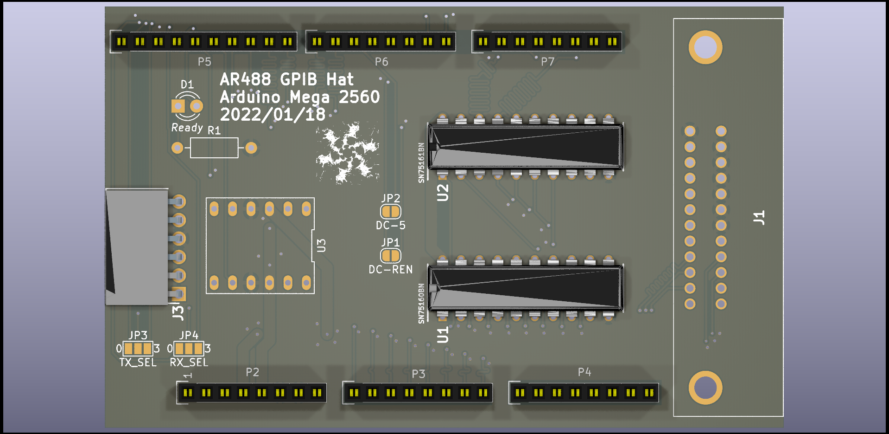
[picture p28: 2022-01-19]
images/AR488-Bluetooth-top1.png

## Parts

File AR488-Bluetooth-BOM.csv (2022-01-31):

Source: | F:\GitHub_Repos\AR488-Bluetooth-Mega-2560\AR488-Bluetooth.kicad_sch
Date: | 31/01/2022 19:18:56
Tool: | Eeschema (6.0.0)
Generator: | C:\Program Files\KiCad\6.0\bin\scripting\plugins/bom_csv_grouped_by_value.py
Component Count: | 39
Individual Components:
Item | Qty | Reference(s) | Value | LibPart | Footprint | Datasheet | Part #
 |  | BT1 | Battery | Device:Battery | Connector_PinHeader_2.54mm:PinHeader_1x02_P2.54mm_Vertical | https://www.farnell.com/datasheets/2820935.pdf | MP000365
 |  | C1 | 10u | Device:C | Capacitor_SMD:C_0402_1005Metric_Pad0.74x0.62mm_HandSolder | https://4donline.ihs.com/images/VipMasterIC/IC/MURE/MURE-S-A0008508937/MURE-S-A0008508937-1.pdf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 | GRM155R60J106ME05D
 |  | C2 | 10u | Device:C | Capacitor_SMD:C_0402_1005Metric_Pad0.74x0.62mm_HandSolder | https://4donline.ihs.com/images/VipMasterIC/IC/MURE/MURE-S-A0008508937/MURE-S-A0008508937-1.pdf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 | GRM155R60J106ME05D
 |  | C3 | 10u | Device:C | Capacitor_SMD:C_0402_1005Metric_Pad0.74x0.62mm_HandSolder | https://4donline.ihs.com/images/VipMasterIC/IC/MURE/MURE-S-A0008508937/MURE-S-A0008508937-1.pdf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 | GRM155R60J106ME05D
 |  | C4 | 0.1u | Device:C | Capacitor_SMD:C_0603_1608Metric_Pad1.08x0.95mm_HandSolder | https://api.kemet.com/component-edge/download/specsheet/C0603C104K9RACTU.pdf | C0603C104K9RACTU
 |  | C5 | 0.1u | Device:C | Capacitor_SMD:C_0603_1608Metric_Pad1.08x0.95mm_HandSolder | https://api.kemet.com/component-edge/download/specsheet/C0603C104K9RACTU.pdf | C0603C104K9RACTU
 |  | D1 | Ready | Device:LED | LED_THT:LED_D3.0mm | ~
 |  | D2 | BAT LOW | Device:LED | LED_THT:LED_D3.0mm | ~
 |  | J1 | 112-024-213R001 | AR488:112-024-213R001 | Socket_Arduino_Mega:112024213R001
 |  | J3 | HC-05 | Connector:Conn_01x06_Female | Socket_Arduino_Mega:RHDRRA6W79P0X254_1X6_1575X851X241P | ~
 |  | JP1 | DC-REN | Jumper:SolderJumper_2_Open | Jumper:SolderJumper-2_P1.3mm_Open_RoundedPad1.0x1.5mm | ~
 |  | JP2 | DC-5 | Jumper:SolderJumper_2_Open | Jumper:SolderJumper-2_P1.3mm_Open_RoundedPad1.0x1.5mm | ~
 |  | JP3 | TX_SEL | Jumper:SolderJumper_3_Open | Jumper:SolderJumper-3_P1.3mm_Open_Pad1.0x1.5mm_NumberLabels | ~
 |  | JP4 | RX_SEL | Jumper:SolderJumper_3_Open | Jumper:SolderJumper-3_P1.3mm_Open_Pad1.0x1.5mm_NumberLabels | ~
 |  | JP5 | CE_SEL | Jumper:SolderJumper_3_Open | Jumper:SolderJumper-3_P1.3mm_Open_Pad1.0x1.5mm_NumberLabels | ~
 |  | L1 | 4.7u | Device:L | Inductor_SMD:L_0805_2012Metric_Pad1.15x1.40mm_HandSolder | https://www.farnell.com/datasheets/3006836.pdf | LQM21PN4R7MGHL
 |  | P1 | Digital | Connector_Generic:Conn_02x18_Odd_Even | Socket_Arduino_Mega:Socket_Strip_Arduino_2x18 | ~
 |  | P2 | Power | Connector_Generic:Conn_01x08 | Socket_Arduino_Mega:Socket_Strip_Arduino_1x08 | ~
 |  | P3 | Analog | Connector_Generic:Conn_01x08 | Socket_Arduino_Mega:Socket_Strip_Arduino_1x08 | ~
 |  | P4 | Analog | Connector_Generic:Conn_01x08 | Socket_Arduino_Mega:Socket_Strip_Arduino_1x08 | ~
 |  | P5 | PWM | Connector_Generic:Conn_01x10 | Socket_Arduino_Mega:Socket_Strip_Arduino_1x10 | ~
 |  | P6 | PWM | Connector_Generic:Conn_01x08 | Socket_Arduino_Mega:Socket_Strip_Arduino_1x08 | ~
 |  | P7 | Communication | Connector_Generic:Conn_01x08 | Socket_Arduino_Mega:Socket_Strip_Arduino_1x08 | ~
 |  | P8 | CONN_01X01 | Connector_Generic:Conn_01x01 | Socket_Arduino_Mega:Arduino_1pin | ~
 |  | P9 | CONN_01X01 | Connector_Generic:Conn_01x01 | Socket_Arduino_Mega:Arduino_1pin | ~
 |  | P10 | CONN_01X01 | Connector_Generic:Conn_01x01 | Socket_Arduino_Mega:Arduino_1pin | ~
 |  | P11 | CONN_01X01 | Connector_Generic:Conn_01x01 | Socket_Arduino_Mega:Arduino_1pin | ~
 |  | P12 | CONN_01X01 | Connector_Generic:Conn_01x01 | Socket_Arduino_Mega:Arduino_1pin | ~
 |  | P13 | CONN_01X01 | Connector_Generic:Conn_01x01 | Socket_Arduino_Mega:Arduino_1pin | ~
 |  | R1 | 1k | Device:R | Resistor_SMD:R_0603_1608Metric_Pad0.98x0.95mm_HandSolder | ~
 |  | R2 | 1k | Device:R | Resistor_SMD:R_0603_1608Metric_Pad0.98x0.95mm_HandSolder | ~
 |  | RV1 | 5M | Device:R_Potentiometer_Small | Potentiometer_THT:Potentiometer_Bourns_3299W_Vertical | https://www.farnell.com/datasheets/2194435.pdf
 |  | SW1 | SW_SPDT | Switch:SW_SPDT | Socket_Arduino_Mega:STSSS9121 | https://www.farnell.com/datasheets/84468.pdf
 |  | TP1 | TestPoint | Connector:TestPoint | TestPoint:TestPoint_Keystone_5015_Micro-Minature | https://www.farnell.com/datasheets/2042719.pdf
 |  | U1 | SN75160BN | AR488:SN75160BN | Socket_Arduino_Mega:DIP794W53P254L2540H508Q20N | http://www.ti.com/lit/ds/symlink/sn75160b.pdf
 |  | U2 | SN75161BN | AR488:SN75161BN | Socket_Arduino_Mega:DIP794W53P254L2540H508Q20N | http://www.ti.com/lit/ds/symlink/sn75160b.pdf
 |  | U3 | Level_Shifter | AR488:Level_Shifter | Socket_Arduino_Mega:DIP-12_400_ELL
 |  | U4 | XC9141B50CMR-G | AR488:XC9141B50CMR-G | Package_TO_SOT_SMD:SOT-23-5_HandSoldering | https://www.farnell.com/datasheets/3118423.pdf
 |  | U5 | MCP65R41T-1202E/CHY | AR488:MCP65R41T-1202E{slash}CHY | Package_TO_SOT_SMD:SOT-23-6_Handsoldering | https://www.farnell.com/datasheets/1669508.pdf
Collated Components:
Item | Qty | Reference(s) | Value | LibPart | Footprint | Datasheet | Part #
1 | 1 | BT1 | Battery | Device:Battery | Connector_PinHeader_2.54mm:PinHeader_1x02_P2.54mm_Vertical | https://www.farnell.com/datasheets/2820935.pdf | MP000365
2 | 3 | C1, C2, C3 | 10u | Device:C | Capacitor_SMD:C_0402_1005Metric_Pad0.74x0.62mm_HandSolder | https://4donline.ihs.com/images/VipMasterIC/IC/MURE/MURE-S-A0008508937/MURE-S-A0008508937-1.pdf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 | GRM155R60J106ME05D
3 | 2 | C4, C5 | 0.1u | Device:C | Capacitor_SMD:C_0603_1608Metric_Pad1.08x0.95mm_HandSolder | https://api.kemet.com/component-edge/download/specsheet/C0603C104K9RACTU.pdf | C0603C104K9RACTU
4 | 1 | D1 | Ready | Device:LED | LED_THT:LED_D3.0mm | ~
5 | 1 | D2 | BAT LOW | Device:LED | LED_THT:LED_D3.0mm | ~
6 | 1 | J1 | 112-024-213R001 | AR488:112-024-213R001 | Socket_Arduino_Mega:112024213R001
7 | 1 | J3 | HC-05 | Connector:Conn_01x06_Female | Socket_Arduino_Mega:RHDRRA6W79P0X254_1X6_1575X851X241P | ~
8 | 1 | JP1 | DC-REN | Jumper:SolderJumper_2_Open | Jumper:SolderJumper-2_P1.3mm_Open_RoundedPad1.0x1.5mm | ~
9 | 1 | JP2 | DC-5 | Jumper:SolderJumper_2_Open | Jumper:SolderJumper-2_P1.3mm_Open_RoundedPad1.0x1.5mm | ~
10 | 1 | JP3 | TX_SEL | Jumper:SolderJumper_3_Open | Jumper:SolderJumper-3_P1.3mm_Open_Pad1.0x1.5mm_NumberLabels | ~
11 | 1 | JP4 | RX_SEL | Jumper:SolderJumper_3_Open | Jumper:SolderJumper-3_P1.3mm_Open_Pad1.0x1.5mm_NumberLabels | ~
12 | 1 | JP5 | CE_SEL | Jumper:SolderJumper_3_Open | Jumper:SolderJumper-3_P1.3mm_Open_Pad1.0x1.5mm_NumberLabels | ~
13 | 1 | L1 | 4.7u | Device:L | Inductor_SMD:L_0805_2012Metric_Pad1.15x1.40mm_HandSolder | https://www.farnell.com/datasheets/3006836.pdf | LQM21PN4R7MGHL
14 | 1 | P1 | Digital | Connector_Generic:Conn_02x18_Odd_Even | Socket_Arduino_Mega:Socket_Strip_Arduino_2x18 | ~
15 | 1 | P2 | Power | Connector_Generic:Conn_01x08 | Socket_Arduino_Mega:Socket_Strip_Arduino_1x08 | ~
16 | 2 | P3, P4 | Analog | Connector_Generic:Conn_01x08 | Socket_Arduino_Mega:Socket_Strip_Arduino_1x08 | ~
17 | 1 | P5 | PWM | Connector_Generic:Conn_01x10 | Socket_Arduino_Mega:Socket_Strip_Arduino_1x10 | ~
18 | 1 | P6 | PWM | Connector_Generic:Conn_01x08 | Socket_Arduino_Mega:Socket_Strip_Arduino_1x08 | ~
19 | 1 | P7 | Communication | Connector_Generic:Conn_01x08 | Socket_Arduino_Mega:Socket_Strip_Arduino_1x08 | ~
20 | 6 | P8, P9, P10, P11, P12, P13 | CONN_01X01 | Connector_Generic:Conn_01x01 | Socket_Arduino_Mega:Arduino_1pin | ~
21 | 2 | R1, R2 | 1k | Device:R | Resistor_SMD:R_0603_1608Metric_Pad0.98x0.95mm_HandSolder | ~
22 | 1 | RV1 | 5M | Device:R_Potentiometer_Small | Potentiometer_THT:Potentiometer_Bourns_3299W_Vertical | https://www.farnell.com/datasheets/2194435.pdf
23 | 1 | SW1 | SW_SPDT | Switch:SW_SPDT | Socket_Arduino_Mega:STSSS9121 | https://www.farnell.com/datasheets/84468.pdf
24 | 1 | TP1 | TestPoint | Connector:TestPoint | TestPoint:TestPoint_Keystone_5015_Micro-Minature | https://www.farnell.com/datasheets/2042719.pdf
25 | 1 | U1 | SN75160BN | AR488:SN75160BN | Socket_Arduino_Mega:DIP794W53P254L2540H508Q20N | http://www.ti.com/lit/ds/symlink/sn75160b.pdf
26 | 1 | U2 | SN75161BN | AR488:SN75161BN | Socket_Arduino_Mega:DIP794W53P254L2540H508Q20N | http://www.ti.com/lit/ds/symlink/sn75160b.pdf
27 | 1 | U3 | Level_Shifter | AR488:Level_Shifter | Socket_Arduino_Mega:DIP-12_400_ELL
28 | 1 | U4 | XC9141B50CMR-G | AR488:XC9141B50CMR-G | Package_TO_SOT_SMD:SOT-23-5_HandSoldering | https://www.farnell.com/datasheets/3118423.pdf
29 | 1 | U5 | MCP65R41T-1202E/CHY | AR488:MCP65R41T-1202E{slash}CHY | Package_TO_SOT_SMD:SOT-23-6_Handsoldering | https://www.farnell.com/datasheets/1669508.pdf

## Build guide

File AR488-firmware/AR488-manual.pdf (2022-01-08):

# AR488 GPIB Controller

# User Manual

Version:
0.49.11

Dated:

## 11nd July 2021

# Twilight Logic

01001010 01000011 01001000

- 1 -

# The AR488 GPIB Controller

The AR488 GPIB controller is an Arduino-based controller for interfacing with IEEE488 GPIB devices. The code has been tested on Arduino Uno, Nano, Mega 2560 and Micro 32U4 boards and provides a low cost alternative to other commercial interfaces.

To build an interface, at least one of the aforementioned Arduino boards will be required to act as the interface hardware. Connecting to an instrument will require a 16 core cable and a suitable IEEE488 connector. This can be salvaged from an old GPIB cable or purchased from electronics parts suppliers. Alternatively, a PCB board can be designed to incorporate a directly mounted IEEE488 connector.

The interface firmware can optionally support the SN75160 and SN75161 GPIB transceiver integrated circuits. Details of construction and the mapping of Arduino pins to GPIB control signals and the data bus are explained in the Building an AR488 GPIB Interface section.

The interface firmware supports standard Prologix commands (with the exception of ++help) and adheres closely to the Prologix syntax but there are some minor differences. In particular, due to issues with the longevity of the Arduino EEPROM memory, the ++savecfg command has been implemented differently. Details of all commands can be found in the Command Reference section.

## Installation

Windows 7 and Windows 10 will automatically recognize the FTDI and CH340G chipsets used by Arduino boards and automatically install the drivers from Windows Update.

The official source for FTDI drivers is here:
https://www.ftdichip.com/FTDrivers.htm

The VCP driver provides a virtual COM port for communication while the D2XX (direct) driver allows direct access via a DLL interface.

The official CH340G driver source is here:
http://www.wch.cn/download/CH341SER_EXE.html

Linux Mint appears to automatically recognize both chipsets as well. Since Linux Mint is based on Ubuntu, it is expected that Ubuntu should also automatically recognize both chipsets.

## Firmware Upgrades

The firmware is upgradeable via the Arduino IDE in the usual manner, however an AVR programmer can also be used to upload the firmware to the Arduino microcontroller. Updates are available from https://github.com/Twilight-Logic/AR488

- 2 -

## Client Software

The interface can be accessed via a number of software client programs.

- Terminal software (e.g. PuTTY)
- EZGPIB (http://www.ulrich-bangert.de/html/downloads.html)
- KE5FX GPIB Configurator (http://www.ke5fx.com/)
- Luke Mester’s HP3478 Control (https://mesterhome.com/gpibsw/hp3478a/)
- Python scripts
- Anything else that can use the Prologix syntax!

Terminal clients connect via a virtual COM port and should be set to 115200 baud, no parity, 8 data bits and 1 stop bit when connecting to the interface. On Linux, the port will be a TTY device such as /dev/ttyUSB0 or /dev/ttyACM0.

Specific considerations apply when using an Arduino based interface with EZGPIB and the KE5FX toolkit. These are described in the Working with EZGPIB and KE5FX section.

## Operating Modes

The interface can operate in both controller and device modes.

Controller mode

In this mode the interface can control and read data from various instruments including Digital multimeters (DMMs). oscilloscopes, signal generators and spectrum analyzers. When powered on, the controller and sends out an IFC (Interface Clear) to the GPIB bus to indicate that it is now the Controller-in-Charge (CIC).

All commands are preceded with the ++ sequence and terminated with a carriage return (CR), newline [a.k.a. linefeed] (LF) or both (CRLF). Commands are sent to or affect the currently addressed instrument which can be specified with the ++addr command (see command help for more information).

By default, the controller is at GPIB address 0.

As with the Prologix interface, the controller has an auto mode that allows data to be read from the instrument without having to repeatedly issue ++read commands. After ++auto 1 is issued, the controller will continue to perform reading of measurements automatically after the next ++read command is used and using the parameters that were specified when issuing that command.

Device mode

The interface supports device mode allowing it to be used to send data to GPIB devices such as plotters via a serial USB connection. All device mode commands are supported.

- 3 -

## Transmission of data

Interrupting transmission of data

While reading of data for the GPIB bus is in progress, the interface will still respond to the ++ sequence that indicates a command. For example, under certain conditions when the instrument is addressed to talk (e.g. when eos is set to 3 [no terminator character] and the expected termination character is not received from the instrument, or read with eoi and the instrument is not configured to assert eoi, or auto mode is enabled), data transmission may continue indefinitely. The interface will still respond to the ++ sequence followed by a command (e.g. + +auto 0 or ++rst). Data transmission can be stopped and the configuration can then be adjusted.

Sending Data and Special characters

Carriage return (CR, hex 0D, decimal 13), newline [a.k.a linefeed] (LF, hex 0A, decimal 10), escape (hex 1B, decimal 27) and ‘+’ (hex 2B, decimal 43) are special “control” characters. Carriage return and newline terminate command strings and direct instrument commands, whereas a sequence of two ‘+’s precedes a command token. Special care needs to be taken when sending binary data to an instrument, because in this case we do not want control characters to prompt some kind of action. Rather, they need to be treated as ordinary and added to the data that is to be transmitted.

When sending binary data, the above mentioned characters must be ‘escaped’ by preceding them with a single escape (hex 1B, decimal 27) byte. For example, consider sending the following binary data sequence:

54 45 1B 53 2B 0D 54 46

It would be necessary to escape the 3 control characters and send the following:

54 45 1B 1B 53 1B 2B 1B 0D 54 46

Without these additional escape character bytes, the special control characters present in the sequence will be interpreted as actions and an incomplete or incorrect data sequence will be sent.

It is also necessary to prevent the interface from terminating the binary data sequence with a carriage return and newline (0D 0A) as this will confuse most instruments. The command ++eos 3 can be used to turn off termination characters. The command ++eos 0 will restore default operation. See the command help that follows for more details.

Receiving data

Binary data received from an instrument is transmitted over GPIB and then via serial over USB to the host computer PC unmodified. Since binary data from instruments is not usually terminated by CR or LF characters (as is usual with ASCII data), the EOI signal can be used to indicate the end of

- 4 -the data transmission. Detection of the EOI signal while reading data can be accomplished with the ++read eoi command, while an optional character can be added as a delimiter with the ++eot_enable command (see the command help that follows). The instrument must be configured to send the EOI signal. For further information on enabling the sending of EOI see your instrument manual.

Listen-only and talk-only (lon and ton) modes

In device mode, the interface supports both “listen-only” and “talk-only” modes (for more details see the ++lon and ++ton commands. These modes are not addressed modes and do not require a GPIB address to be set. Therefore if any GPIB address is already set, it is simply ignored. Moreover, when in either of these modes, devices are not controlled by the CIC. Data characters are sent using standard GPIB handshaking , but GPIB commands are ignored. The bus acts as a simple one to many transmission medium. In lon mode, the device will receive any data placed on the bus by any talker, including any other addressed device or controller. Since only ONE talker can exist on the bus at a time, there can only be one device in "talk-only" mode on the bus, however multiple "listen-only" devices can be present and all will receive the data sent by the talker.

## Wireless communication

The AR488 interface can communicate using a Bluetooth module (HC05 or HC06). The firmware sketch supports auto-configuration of the Bluetooth HC05 module, the details of which can be found in the Configuration section and the AR Bluetooth Support supplement. Automatic configuration is not possible with a HC06 module so although this can be used to provide Bluetooth communication, it has to be configured manually.

- 5 -

## Configuration

Configuration of the AR488 is achieved be editing the AR488_Config.h file. This is a C++ style header file containing various definition statements, also known as ‘define macros’ , starting with keyword ‘#define’, that can be used to configure the firmware. The AR488_config.h file must be included in the main AR488 sketch as well as any other module header file (e.g. AR488_Layouts.cpp and AR488_Layouts.h) with an include statement:

#include "AR488_Config.h

A number of these definition statements are contained within an #ifdef .. #endif construct, some of which may contain additional #else or #elif elements. The presence of these constructs is necessary and they should not be changed or removed. Only the definitions within them should be changed as required. Nothing should need to be changed in any other file.

Firmware version

This is in the format:
#define FWVER "AR488 GPIB controller, ver. 0.48.08, 27/01/2020"

This entry should not exceed 47 characters and should not be changed.

Board Selection and serial port configuration

The AR488 supports a number of Arduino AVR boards and also a custom GPIO pin layout which can be defined by the user in the Custom Board Layout section. If a custom GPIO pin layout is to be used, then following entry must have the comment characters (preceding ‘//’) removed:

//#define AR488_CUSTOM

Otherwise, the comment characters should remain in place which has the effect of disabling the definition by designating it as a comment. The compiler ignores comment statements. Following this is an #ifdef statement containing several sections preceded by an #elif keyword. Each of these is followed by a token that corresponds to known Arduino definitions for microprocessor types. The structure looks like this:

/*
* Configure the appropriate board/layout section
* below as required
*/
#ifdef AR488_CUSTOM

…
#elif __AVR_Atmega328P__

…
#elif __AVR_Atmega32U4__

#elif __AVR_Atmega2560__

…
#endif // Board/layout selection

- 6 -

When the custom layout is selected, all other layouts are ignored. If the custom layout is not selected, then the section corresponding to the automatically detected Arduino microprocessor will apply. Each section contains a definition referencing one or more pre-defined board layouts as well as serial port definitions corresponding to the features of specific boards. For example here are the definitions for boards based on the 328p microprocessor which are found within the __AVR_Atmega328P__ section of the #ifdef statement:

/* Board/layout selection */
#define AR488_UNO

//#define AR488_NANO
/*** Serial ports ***/
//Select HardwareSerial or SoftwareSerial (default = HardwareSerial) ***/ // The UNO/NANO default hardware port is 'Serial'
// (Comment out #define AR_HW_SERIAL if using SoftwareSerial)
#define AR_HW_SERIAL

#ifdef AR_HW_SERIAL

#define AR_SERIAL_PORT Serial

#else

// Select software serial port
#define AR_SW_SERIAL

#endif

The section contains definitions for two boards, namely the Uno and the Nano. Only ONE of these should be selected by removing the preceding comment characters:

#define AR488_UNO

//#define AR488_NANO

The default entry is AR488_UNO, which selects the pre-defined template for the Arduino UNO board in AR488_Hardware.h. Selecting AR488_NANO will select the pre-defined template for the Nano board. In order to compile the sketch for the selected board, in addition to selecting the template in Config.h, the correct board must be selected in the Board Manager within the Arduino
IDE (see Tools | Board: ).

Following this are definitions for the serial port:

#define AR_HW_SERIAL

#ifdef AR_HW_SERIAL

#define AR_SERIAL_PORT Serial #else

// Select software serial port
#define AR_SW_SERIAL

#endif

By default, the most commonly used serial port for a particular board will be enabled. In the example above, the hardware port named Serial is selected. To switch between the default hardware port and a SoftwareSerial port, it is necessary only to comment out #define AR_HW_SERIAL by preceding the line with ‘//’.

The section for the 32u4 (Micro/Leonardo) is similar, except by default AR_CDC_SERIAL is enabled and switching is between the USB CDC port and the hardware port Serial1.

The Mega 2560 has 4 hardware serial ports so either ‘Serial’, ‘Serial1’, ‘Serial2’ or ‘Serial3’ must be selected. Most likely the default port named Serial will be used although other options are possible if required. However, please note that the default GPIO pin layout for the Mega 2560

- 7 -board (AR488_MEGA2560_D) uses the pins assigned to Serial2 for other purposes, so this cannot be used as a serial port with that particular layout definition. However, it can be used with the E1 and E2 definitions.

For any board, adding the line #define AR_SW_SERIAL and commenting out the AR_HW_SERIAL and/or AR_CDC_SERIAL definitions will invoke the SoftwareSerial library. When a SoftwareSerial port is required, then the GPIO pins as well as the baud rate to be used will need to be configured in the following Software Serial Support section.

Where a board has more than one hardware or CDC serial port available, it will be necessary to correctly specify the Arduino name of the serial port to be used. For the Uno and Nano this will always be ‘Serial’ because those boards have only one UART and therefore only one hardware serial port. Other boards have more than one serial port available. For example, on the Pro Micro , enabling the hardware port rather than the CDC port will automatically select Serial1 instead of Serial. For the Mega 2560 there are four choices and the correct port name must be chosen by uncommenting the appropriate line, e.g:

#define AR_SERIAL_PORT Serial1

The remaining choices must be commented out by preceding them with ‘//’.

It should be noted that for any board, only ONE serial port can be used and therefore only one port should be enabled.

It is important to make sure that the correct board is selected in the Arduino IDE Boards Manager (Tools => Board) otherwise the sketch will not compile correctly.

Software Serial port configuration

The SoftwareSerial library can be used with any board provided that at least two pins are available. One of these must be a PWM enabled GPIO pin which is required to emulate the transmit (Tx) output for the serial two wire connection. The receive (Rx) pin can be assigned any available GPIO pin.

Enabling SoftwareSerial can be done by removing the comment characters (‘//’) preceding the #define AR_SW_SERIAL entry in the relevant board selection section. In addition, the pins to be used as well as the board rate will need to be configured in the Software Serial Support section as follows:

#ifdef AR_SW_SERIAL

#define AR_SW_SERIAL_RX 53

#define AR_SW_SERIAL_TX 51 #define AR_SERIAL_BAUD 57600 #else

#define AR_SERIAL_BAUD 115200

#endif

The appropriate GPIO pin numbers should be specified after the #define AR_SW_SERIAL_RX and the #define AR_SW_SERIAL_TX statements within the #ifdef AR_SW_SERIAL clause. The baud rate should be specified here as well after #define AR_SERIAL_BAUD. Please note that, when using SoftwareSerial, the maximum baud rate that can be achieved reliably is 57600 baud.

- 8 -

The hardware/CDC serial port baud rate is specified after the #else statement. The default hardware baud rate is 115200, but any valid baud rate can be specified.

Please note also, that when using USB CDC ports, the Arduino board will NOT be reset when a serial connection is made over USB as is the case with Uno and Nano boards. The reset button must be pressed in order to reset the board. The Arduino IDE seems to take care of programming the board automatically but when using the Arduino IDE on Linux, the modemmanager service will need to be disabled as it interferes with serial ports and disrupts the normal operation of the programming process, causing boards to end up in a state where they can no longer be programmed over USB. Boards that have been disabled in this way can be recovered by uploading a bootloader to them using an AVR programmer. Linux Mint (and probably Ubuntu) will have this service enabled and running in the background by default. This service is not required but may be useful in the event that a serial modem is connected to the PC.

Serial Interrupt Handling

All AVR boards support SerialEvent. This was used in previous versions of AR488 but its use is now deprecated. The Arduino has no hardware interrupt to signal a character being received into the Ardiono serial buffer. The SerialEvent function is actually aliased to the serial.available() function and is executed at the end of every iteration of void loop(). Non-Arduino boards (e.g. STM32) may not support SerialEvent so for reasons of consistency between different boards, SerialEvent is not used. Instead, a serial event handler is called at the end of every loop iteration.

When working with programs and scripts (e.g. Python), it should be bourne in mind that the Arduino is only 64 bytes in size. Due to the memory constraints of the Arduino, the additional processing buffer provided by the AR488 program is also limited to only 128 bytes. There is also no handshaking between the PC and the Arduino serial port. Although the Arduino can keep up pretty well, the serial input buffer can easily overflow with loss of characters if data is passed too quickly. This means that a bit of trial and error may be required when working with scripts to establish whether and how much delay is required between commands. A short delay may sometimes be needed to avoid a buffer overflow. The amount of delay will depend on factors such as the interface hardware being used, the time taken for the instrument to respond, as well as the GPIB speed of the instrument being addressed.

Detection of SRQ and ATN pin states

Arduino AVR boards support interrupts to detect a change in pin states and this has been implemented for the UNO, NANO and MEGA boards to improve response. When a supported board template has been selected, (see the Board Selection and Serial Port Configuration section) and AR488_CUSTOM is not in use, then USE_INTERRUPTS will be defined and certain interrupts activated by default.

Other boards may not support interrupts and interrupts cannot be used with the custom GPIO pin layout. When AR488_CUSTOM is defined and in used, USE_INTERRUPTS will not get defined and interrupts are not activated. Instead, pin states are detected during each iteration of the void loop() function. When a non-AVR or unsupported board is selected as the compilation target, then USE_INTERRUPTS should be commented out and not used.

- 9 -

The section in AR488_Config.h looks as follows:

#ifdef __AVR__

// For supported boards use interrupt handlers
#if defined (AR488_UNO) || defined (AR488_NANO) || defined (AR488_MEGA2560) || defined (AR488_MEGA32U4)

#ifndef AR488_CUSTOM

#define USE_INTERRUPTS

#endif

#endif

The entry should be preceded by ‘//’ to indicate that it has been commented out. Interrupts are used by default on supported boards because they usually respond faster than in-loop checking.

Macro support

Macros in this context are short sequences of commands that can be used to accomplish a particular task. Controlling an instrument usually requires sequences of commands to be sent to the device to configure it, or to perform a particular task. Sometimes such sequences are performed frequently or repetitively. In those circumstances, it may be more efficient to pre-program the required sequence and then execute it when required using a single command.

The AR488 supports a macro feature which allows user programmed command sequences to be run when the interface starts up, as well as up to 9 user defined command sequences to be executed at runtime.

Macros must be programmed before the sketch is compiled and uploaded to the interface. Macros can be added to the designated AR488 MACROS SECTION in the AR488_Config.h file. Both interface ++ commands and direct instrument commands can be included in macros. Programming specific instruments is beyond the scope of this manual as commands will be specific to each instrument or implemented according to the manufacturers choice of programming language or protocol. However, in general, in order to create macros, a few simple rules will need to be followed.

Firstly, macros need to be enabled. In the AR488_Config.h file there are two definitions under the heading ‘Enable Macros’:

#define USE_MACROS | // Enable the macro feature

#define RUN_STARTUP | // Run MACRO_0 (the startup macro)

The #define USE_MACROS construct enables or disables the macro feature. When this line is commented out by preceding it with ‘//’ then macros are disabled. Removing the preceding ‘//’ will enable the macro feature.

The #define RUN_STARTUP statement controls whether the start-up macro will run when the interface is powered up or re-started. The start-up macro is designated MACRO_0 and if #define RUN_STARTUP is enabled, this macro will run when the interface is powered on or reset.

When #define USE_MACROS is disabled, then the start-up macro will not be activated when the interface is powered up or reset and none of the user macros (1-9) will be available at runtime.

- 10 -

When enabled, MACRO_0 will run when the interface is powered up or reset but only if #define RUN_STARTUP is also enabled. The user macros (1-9) will always be available and can be executed by the user at runtime by using the ++macro command. For more information please see the ++macro command heading in the Command Reference.

The start-up macro can be used in addition to the interface settings that can be saved using the + +savecfg command, to not only to set up the interface, but also to initialise and configure the instrument for a specific function. In this way, instrument commands that select function, range and other control features can be sent automatically as the interface starts up.

Unless steps have been taken to disable the automatic reset that occurs when a USB serial connection is opened to the interface, the start-up macro will run every time that a serial connection is initiated to the interface. On the other hand, disabling reset prevents the Arduino from being programmed via USB, so is not advised unless the intention is to program the Arduino using a suitable AVR programmer.

In the AR488_Config.h file, sketch, below the help information there is a section that starts:

/********************************/
/***** AR488 MACROS SECTION *****/
/***** vvvvvvvvvvvvvvvvvvvv *****/
#ifdef USE_MACROS

Macros are defined here. The first macro is the startup macro, an example of which might be defined as follows:

#define MACRO_0 "\

++addr 9\n\
++auto 2\n\
*RST\n\
:func 'volt:ac'
"
/* End of MACRO_0 (Startup macro)*/

Note that the macro code itself, is shown in bold, and has been inserted immediately after the #define MACRO_0 line and before the ending comment:

#define MACRO_0 “\

macro
“
/*<-End of startup macro*/.

All macro commands comprising the macro must be placed after the ‘\’ on the first line and before the final quote on the line before the ending comment. Nothing outside of these lines, including the quote marks and the ‘\’ and after the macro name should be modified. The final quote mark can be appended to the last command in the sequence if preferred. It is shown here on a separate line for clarity. Everything between the two quote marks is a string of characters and must be delimited. The ‘\’ character indicate to the pre-processor that the string continues on the next line. Each command ends with ‘\n’ which is the newline terminator and serves to delimit each command. The actual sequence shown above is therefore comprised of 4 commands, each command ending with ‘\n’ and then a ‘\’ to indicate that the next command is to follow on the next line. Try to avoid leaving or including any unnecessary spaces.

- 11 -

Each of these commands is either a standard AR488 interface command found in the command reference, or an instrument specific command. All AR488 interface Prologix style commands begin with ++ so the first two commands set the GPIB address to 7 and auto to 1. The next two commands are direct instrument commands using the SCPI protocol, the first of which resets the instrument and the second selects the instrument AC voltage function.

As shown, each command must be terminated with a ‘\n’ (newline) or ‘\r’ (carriage return) delimiter character.

User defined macros that can be run using the ++macro command follow next, and have a similar format, e.g:

#define MACRO_2 "\

"
/*<-End of macro 2*/

Once again, the required command sequence must be placed between the two quotes and after the first ‘/’ and be terminated with a ‘\n’ or ‘\r’ delimiter. Each line must be wrapped with ‘\’.

There is a slightly shorter method of defining a macro by placing all commands on a single line. For example this:

#define MACRO_1 "++addr 7\n++auto 1\n*RST\n:func 'volt:ac'"

Is exactly the same as this:

#define MACRO_1 "\

++addr 7\n\
++auto 1\n\
*RST\n\
:func 'volt:ac'\
"

The first definition is more condensed and requires no line wrap characters, but it is perhaps easier to see what is going on in the latter example. Either will function just the same and take up the same amount of memory.

The macro definition area provided in the sketch ends with:

#endif

/***** ^^^^^^^^^^^^^^^^^^^^ *****/
/***** AR488 MACROS SECTION *****/ /********************************/

Anything outside of this section does not relate to macros.

Provided that the commands have been specified correctly and the syntax is correct, the sketch should compile and can be uploaded to the Arduino. The start-up macro will run as soon as the upload is completed so the instrument should respond immediately. Please be aware that, unless serial reset has been disabled, it will run again when a USB serial connection is made to the interface. The instrument will probably respond and reconfigure itself again.

- 12 -

Please note that, although AR488 interface ++ commands are verified by the interface, and will respond accordingly, there is no sanity checking by the interface of any direct instrument commands. These command sequences are sent directly to the instrument, which should respond as though the command sequence were typed directly into the terminal or sent from a suitable instrument control program. Please consult the instrument user manual for information about the behaviour expected in response to instrument commands.

Macro sequences can include any number delimiter separated of commands, but any individual command sequence should not exceed 126 characters. This may be particularly relevant to SCPI commands which can be composed of multiple instructions separated by colons.

SN7516x GPIB transceiver support

Support for the SN75160 and SN75161 GPIB transceiver integrated circuits can be enabled by uncommenting the following line:

//#define SN7516X

The pins used to control the ICs are defined in the section that follows:

#ifdef SN7516X

#define SN7516X_TE 6

// #define SN75161_DC 13
#endif

Specify the pin to be used for the SN7516X_TE signal. The above example shows pin 6 being used and this is connected to the talk-enable (TE) pin on both ICs. The SN75161 handles the GPIB control signals and in addition to the TE pin, also has a direction-control (DC) pin. This is used to determine controller or device mode operation. A GPIO pin can be assigned to drive this pin, in which case the SN75151_DC definition shown above should be uncommented and an appropriate GPIO pin number assigned.

Alternatively, since the REN signal is asserted in controller mode and un-asserted in device mode, this signal can be used to drive the DC pin of the SN75161. In this case, the SN75161_DC definition should remain commented out and the GPIO pin assigned to the REN signal should be connected to both DC and REN on the SN75161 IC. There is one small caveat when using this configuration. The custom ++REN command, which is used to turn the REN line on and off, cannot be used and will just return:

Unavailable.

If a separate GPIO pin is used to control DC then the ++REN command will return the status of REN as usual. (See ++REN in the Custom Comands section of the Command Reference).

Bluetooth HC05 module Options

This section is used to configure Bluetooth HC05 module options and looks like the below:

//#define AR_BT_EN 12 | // Bluetooth enable and control pin
#ifdef AR_BT_EN

- 13 -

#define AR_BT_BAUD 115200 // Bluetooth module preferred baud rate #define AR_BT_NAME "AR488-BT" // Bluetooth device name

#define AR_BT_CODE "488488" // Bluetooth pairing code

#endif

To enable Bluetooth HC05 module auto-configuration, the first line needs to have the preceding comment characters (//) removed and a GPIO pin assigned. It is then necessary to set the configuration parameters, including baud rate, the name that the device will be identified with and the pairing code. The AR_BT_BAUD parameter must not have double quotes around it.

By default, the name is AR488-BT and the pairing code is 488488. The HC05 module only needs connecting to the RX/TX pins of a serial port and it will be automatically configured with these parameters on interface start-up.

This feature cannot work with the HC06 module as it does not have management mode or an enable pin implemented. Full details of Bluetooth configuration and wiring are included in the separate AR488 Bluetooth Support supplement.

Debug options

The AR488 can send certain debug messages to a serial port which can be helpful when trying to diagnose a problem. These should not be required or enabled for normal running of the interface, but if required for debugging, one or more of the following can be enabled by removing the preceding // comment characters:

//#define DEBUG1 // getCmd
//#define DEBUG2 // setGpibControls
//#define DEBUG3 // gpibSendData //#define DEBUG4 // spoll_h //#define DEBUG5 // attnRequired //#define DEBUG6 // EEPROM //#define DEBUG7 // gpibReceiveData
//#define DEBUG8 // ppoll_h
//#define DEBUG9 // bluetooth

By default, debug messages will be sent to the serial port that is used for communication. Where the interface provides additional serial ports or where there are sufficient GPIO pins available to use SoftwareSerial, it is possible to send debug messages to an alternative serial port. This has the advantage that debug messages will no longer interfere with normal interface communications. The debug messages can be viewed on the alternative ‘debug’ port while normal interface operations are in progress on the communications port.

To enable this feature uncomment the following line in the Debug Options section in AR488_Config.h:

//#define DB_SERIAL_PORT Serial1

Set the serial port to the port that will receive the debug messages. Configure the baud rate, set the serial port type, and if using SoftwareSerial, the GPIO pins to be used, for example:

#define DB_SERIAL_BAUD 57600

#define DB_SW_SERIAL

#ifdef DB_SW_SERIAL

- 14 -

#define DB_SW_SERIAL_RX 53

#define DB_SW_SERIAL_TX 51

#endif

The above will configure a SoftwareSerial port at 57600 baud on GPIO pins 53 and 51. Please note that the maximum advisable speed for a SoftwareSerial port is 57600 baud.

Debug messages do not include messages shown when verbose mode is enabled with the ++verbose command. When the interface is being directly controlled by another program, verbose mode should be turned off otherwise verbose messages may interfere with normal operations.

Custom Board Layout Section

The custom board layout section in the Config.h file can be used to create a custom pin layout for the AR488. This can be helpful for non-Arduino boards and where an adjustment to the layout is required in order to accommodate additional hardware. By default, the definition implements the Uno layout:

#define DIO1 A0 /* GPIB 1 */

#define DIO2 A1 /* GPIB 2 */

#define DIO3 A2 /* GPIB 3 */ #define DIO4 A3 /* GPIB 4 */ #define DIO5 A4 /* GPIB 13 */ #define DIO6 A5 /* GPIB 14 */

#define DIO7 4 | /* GPIB 15 */

#define DIO8 5 | /* GPIB 16 */

#define IFC | 8 | /* GPIB 9 */

#define NDAC 9 | /* GPIB 8 */

#define NRFD 10 /* GPIB 7 */

#define DAV | 11 /* GPIB 6 */

#define EOI | 12 /* GPIB 5 */

#define SRQ | 2 | /* GPIB 10 */

#define REN | 3 | /* GPIB 17 */

#define ATN | 7 | /* GPIB 11 */

To make use of a custom layout, AR488_CUSTOM must be selected from the list of boards at the beginning of the Config.h file and the pin numbers/designations in the centre column (shown in bold) should be configured as required.

Please note that on some MCU boards, a number of GPIO pins may not be available as inputs and/ or outputs despite a pad or connector being present. Please check the board documentation. Sometimes such information is revealed only in online forum discussions or blogs.

When AR488_CUSTOM is defined, interrupts cannot be used to detect pin states and therefore USE_INTERRUPTS will not be defined and interrupts will not be activated. Pin states will be checked on every iteration of void loop() instead.

- 15 -

## Command Reference

The controller implements the standard commands prefixed with two plus (++) character sequence to indicate that the following sequence is an interface command. Commands, with the exception of the ++savecfg command, should be fully compatible with the Prologix GPIB-USB controller. However, the interface also implements a number of additional custom commands.

++addr

This is used to set or query the GPIB address. At present, only primary addresses are supported. In controller mode, the address refers to the GPIB address of the instrument that the operator desires to communicate with. The address of the controller is 0. In device mode, the address represents the address of the interface which is now acting as a device.

When issued without a parameter, the command will return the current GPIB address.

Modes: | controller, device
Syntax: | ++addr [1-29] where 1-29 is a decimal number representing the primary GPIB address of the device.

++auto

Configure the instrument to automatically send data back to the controller. When auto is enabled, the user does not have to issue ++read commands repeatedly. This command has additional options when compared with the Prologix version.

When set to zero, auto is disabled.

When set to 1, auto is designed to emulate the Prologix setting. The controller will automatically attempt to read a response from the instrument after any instrument command or, in fact, any character sequence that is not a controller command beginning with ‘++’, has been sent.

When set to 2, auto is set to “on-query” mode. The controller will automatically attempt to read the response from the instrument after a character sequence that is not a controller command beginning with ‘++’ is sent to the instrument, but only if that sequence ends in a ‘?’ character, i.e. it is a query command such as ‘*IDN?’.

When set to 3, auto is set to “continuous” mode. The controller will execute continuous read operations after the first ++read command is issued, returning a continuous stream of data from the instrument. The command can be terminated by turning off auto with ++auto 0 or performing a reset with ++rst.

Modes: | controller
Syntax: | ++auto [0|1|2|3] where 0 disables and 1 enables automatically sending data to the controller
- 16 -

Note:
Some instruments generate a “Query unterminated or “-420” error if they are addressed after sending an instrument command that does not generate a response. This simply means that the instrument has no information to send and this error may be ignored. Alternatively, auto can be turned off (++auto 0) and a ++read command issued following the instrument command to read the instrument response.

++clr

This command sends a Selected Device Clear (SDC) to the currently addressed instrument. Details of how the instrument should respond may be found in the instrument manual.

Modes: | controller
Syntax: | ++clr

++eoi

This command enables or disables the assertion of the EOI signal. When a data message is sent in binary format, the CR/LF terminators cannot be differentiated from the binary data bytes. In this circumstance, the EOI signal can be used as a message terminator. When ATN is not asserted and EOI is enabled, the EOI signal will be briefly asserted to indicate the last character sent in a multi-byte sequence. Some instruments require their command strings to be terminated with an EOI signal in order to properly detect the command.

The EOI line is also used in conjunction with ATN to initiate a parallel poll, however, this command has no bearing on that activity.

When issued without a parameter, the command will return the current configuration

Modes: | controller, device
Syntax: | ++eoi [0|1] where 0 disables and 1 enables asserting EOI to signal the last character sent

++eos

Specifies the GPIB termination character. When data from the host (e.g. a command sequence) is received over USB, all non-escaped LF, CR or Esc characters are removed and replaced by the GPIB termination character, which is appended to the data sent to the instrument. This command does not affect data being received from the instrument.

When issued without a parameter, the command will return the current configuration

- 17 -

Modes: | controller, device
Syntax: | ++eos [0|1|2|3] where 0=CR+LF, 1=CR, 2=LF, 3=none

++eot_enable

This command enables or disables the appending of a user specified character to the USB output from the interface to the host whenever EOI is detected while reading data from the GPIB port. The character to send is specified using the ++eot_char command.

When issued without a parameter, the command will return the current configuration.

Modes: | controller, device
Syntax: | ++eot_enable [0|1] where 0 disables and 1 enables sending the EOT character to the USB output

++eot_char

This command specifies the character to be appended to the USB output from the interface to the host whenever an EOI signal is detected while reading data from the GPIB bus. The character is a decimal ASCII character value that is less than 256.

When issued without a parameter, the command will return a decimal number corresponding to the ASCII character code of the current character.

Modes: | controller, device
Syntax: | ++eot_char [<char>] where <char> is a decimal number that is less than 256.

++help

Not currently supported

++ifc

Assert the GPIB IFC signal for 150 microseconds, making the AR488 the Controller-in-Charge on the GPIB bus.

Modes: | controller
Syntax: | ++ifc
- 18 -

++llo

Disable front panel operation on the currently addressed instrument. In the original HPIB specification, sending the LLO signal to the GPIB bus would lock the LOCAL control on ALL instruments on the bus. In the Prologix specification, this command disables front panel operation of the addressed instrument only, in effect taking control of that instrument. The AR488 follows the Prologix specification, but adds a parameter to allow the simultaneous assertion of remote control over all instruments on the GPIB bus as per the HPIB specification.

This command requires the Remote Enable (REN) line to be asserted otherwise it will be ignored. In controller mode, the REN signal is asserted by default unless its status is changed by the ++ren command.

When the ++llo command is issued without a parameter, it behaves the same as it does on the Prologix controller. The LLO signal is sent to the currently addressed instrument and this locks out the LOCAL key on the instrument control panel. Because the instrument has been addressed and REN is already asserted, the command automatically takes remote control of the instrument. Most instruments will display REM on their display or control panel to indicate that remote control is active and front/rear panel controls will be disabled.

If the ++llo command is issued with the ‘all’ parameter, this will send the LLO signal to the bus, putting every instrument into remote control mode simultaneously. At this point, instruments will not yet show the REM indicator and it may still be possible to operate the front panel controls. On some instruments the LOCAL key may be locked out. However, as soon as an instrument has been addressed and sent a command (assuming that a LOC signal has not been sent yet first), the controller will automatically lock in remote control of that instrument , the REM indicator will be displayed and front/rear panel controls will be disabled.

Modes: | controller
Syntax: | ++llo [all]

++loc

Relinquish remote control and re-enable front panel operation of the currently addressed instrument. This command relinquishes remote control of the instrument by de-asserting REN and sending the GTL signal.

The Remote Enable (REN) line must be asserted and the instrument must already be under remote control otherwise the command has no effect.

In the original HPIB specification, this command would place all instuments back into local mode, re-enabling the LOCAL key and panel controls on ALL instruments currently connected to the GPIB bus. In the Prologix specification, this command relinquishes remote control of the currently addressed instrument only. The AR488 follows the Prologix specification, but adds a parameter to allow the simultaneous release of remote control over all instruments currently addressed as listeners on the GPIB bus as per the HPIB specification.

- 19 -

If the command is issued without a parameter, it will re-enable the LOCAL key on the control panel on the currently addressed instrument and relinquish remote control of the instrument. If issued with the ‘all’ parameter, it puts all devices on the GPIB bus in local control state. The REM indicator should no longer be visible when the instrument has returned to local control state.

Modes: | controller
Syntax: | ++loc [all]

++lon

The ++lon command configures the controller to listen only to traffic on the GPIB bus. In this mode the interface does require to have a GPIB address assigned so the assigned GPIB address is ignored. Traffic is received irrespective of the currently set GPIB address. The interface can receive but not send, so effectively becomes a “listen-only” device. When issued without a parameter, the command returns the current state of “lon” mode.

Modes: | device
Syntax: | ++lon [0 |1] where 0=disabled; 1=enabled

++mode

This command configures the AR488 to serve as a controller or a device.

In controller mode the AR488 acts as the Controller-in-Charge (CIC) on the GPIB bus, receiving commands terminated with CRLF over USB and sending them to the currently addressed instrument via the GPIB bus. The controller then passes the received data back over USB to the host.

In device mode, the AR488 can act as another device on the GPIB bus. In this mode, the AR488 can act as a GPIB talker or listener and expects to receive commands from another controller (CIC). All data received by the AR488 is passed to the host via USB without buffering. All data from the host via USB is buffered until the AR488 is addressed by the controller to talk. At this point the AR488 sends the buffered data to the controller. Since the memory on the controller is limited, the AR488 can buffer only 120 characters at a time.

When sending data followed by a command, the buffer must first be read by the controller before a subsequent command can be accepted, otherwise the command will be treated as characters to be appended to the existing data in the buffer. Once the buffer has been read, it is automatically cleared and the parser can then detect the ++ command prefix on the next line. Therefore sufficient delay must be allowed for the buffer to be read before sending a subsequent command.

If the command is issued without a parameter, the current mode is returned.

Modes: controller, device

- 20 -

Syntax: ++mode [0|1] where 0=device, 1=controller

++read

This command can be used to read data from the currently addressed instrument. Data is read until:

- the EOI signal is detected
- a specified character is read
- timeout expires

Timeout is set using the read_tmo_ms command and is the maximum permitted delay for a single character to be read. It is not related to the time taken to read all of the data. For details see the description of the read_tmo_ms command.

Modes: | controller
Syntax: | ++read [eoi|<char>] where <char> is a decimal number corresponding to the ASCII character to be used as a terminator and must be less than 256.

++read_tmo_ms

This specifies the timeout value, in milliseconds, that is used by the ++read (and ++spoll) commands to wait for a character to be transmitted while reading data from the GPIB bus. The timeout value may be set between 0 and 32,000 milliseconds (32 seconds).

Modes: | controller
Syntax: | ++read_tmo_ms <time> where <time> is a decimal number between 0 and 32000 representing milliseconds

++rst

Perform a reset of the controller.

Please note that the reset may fail and hang the board under certain circumstances. These include:

- the board has an older bootloader. The older bootloader had an problem with not clearing the MCUSR register which triggers another reset while the bootloader is being executed, which causes a perpetual restart cycle. The solution here is to update the bootloader. The newer Optiboot bootloader does not have this problem.
- using a 32u4 board (Micro, Leonardo) programmed with an AVR programmer with no bootloader. There is at present no solution to this problem. When programming with an
- 21 -

AVR programmer, use a recent IDE version to export the binaries and upload the version with the bootloader to the board.

Modes: | controller, device
Syntax: | ++rst

++savecfg

This command saves the current interface configuration. On the Prologix interface setting this to 1 would enable the saving of specific parameters whenever they are changed, including addr, auto, eoi, eos, eot_enable, eot_char, mode and read_tmo_ms.

Frequent updates wear out the EEPROM and the Arduino EEPROM has a nominal lifetime of 100,000 writes. In order to minimize writes and preserve the longevity of the EEPROM memory, the AR488 does not, at any time, write configuration parameters “on the fly” every time they are changed. Instead, issuing the ++savecfg command will update the complete current configuration once. Only values that have changed since the last write will be written.

The configuration written to EEPROM will be automatically re-loaded on power-up. The configuration can be reset to default using the ++default command and a new configuration can be saved using the ++savecfg command.

Most, if not all Arduino AVR boards support EEPROM memory, however boards from other vendors may not provide this support. If the command is run on a board that does not support EEPROM, then the following will be returned:

EEPROM not supported.

The ++savecfg command will save the following current parameter values: addr, auto, eoi, eos, eot_enable, eot_char, mode, read_tmo_ms and verstr.

Modes: | controller, device
Syntax: | ++savecfg

++spoll

Performs a serial poll. If no parameters are specified, the command will perform a serial poll of the currently addressed instrument. If a GPIB address is specified, then a serial poll of the instrument at the specified address is performed. The command returns a single 8-bit decimal number representing the status byte of the instrument.

The command can also be used to serial poll multiple instruments. Up to 15 addresses can be specified. If the all parameter is specified (or the command ++allspoll is used), then a serial poll of all 30 primary instrument addresses is performed.

- 22 -

When polling multiple addresses, the ++spoll command will return the address and status byte of the first instrument it encounters that has the RQS bit set in its status byte, indicating that it has requested service. The format of the response is SRQ:addr,status, for example: SRQ:3,88 where 3 is the GPIB address of the instrument and 88 is the status byte. The response provides a means to poll a number of instruments and to identify which instrument raised the service request, all in one command. If SRQ was not asserted then no response will be returned.

When ++srqauto is set to 1 (for details see the ++srqauto custom command), the interface will automatically conduct a serial poll of all devices on the GPIB bus whenever it detects that SRQ has been asserted and the details of the instrument that raised the request are automatically returned in the format above.

Modes: | controller
Syntax: | ++spoll [<PAD>|all|<PAD1> <PAD2> <PAD3>...] where <PAD> and <PADx> are primary GPIB address and all specifies that all instruments should be polled

++srq

This command returns the present status of the SRQ signal line. It returns 0 if SRQ is not asserted and 1 if SRQ is asserted.

Modes: | controller
Syntax: | ++srq

++status

Set or display the status byte that will be sent in response to the serial poll command. When bit 6 of the status byte is set, the SRQ signal will be asserted indicating Request For Service (RQS). The table below shows the values assigned to individual bits as well as some example meanings that can be associated with them. Although the meaning of each bit will vary depending on the instrument and the manufacturer, bit 6 is always reserved as the RQS bit. Other bits can be assigned as required.

Bit7 | Bit6 | Bit5 | Bit4 | Bit3 | Bit2 | Bit1 | Bit0
128 | 64 | 32 | 16 | 8 | 4 | 2 | 1
Always zero | RQS | Calibration enabled or error | Output available. Front/rear switch. | Remote control | Auto-zero | Autorange enabled. Front/rear switch. | Operational error.

The values of the bits to be set can be added together to arrive at the desired status byte value. For example, to assert SRQ, a value of 64 would be sufficient. However if we wanted to use bit 1 to indicate an operational error, then a value of 65 might be used in the event of the error occurring.

Modes: device

- 23 -

Syntax: ++status [byte] where byte is a decimal number between 0 and 255.

++trg

Sends a Group Execute Trigger to selected devices. Up to 15 addresses may be specified and must be separated by spaces. If no address is specified, then the command is sent to the currently addressed instrument. The instrument needs to be set to single trigger mode and remotely controlled by the GPIB controller. Using ++trg, the instrument can be manually triggered and the result read with ++read.

Modes: | controller
Syntax: | ++trg [pad1 … pad15]

++ver

Display the controller firmware version. If the version string has been changed with ++setvstr, then ++ver will display the new version string. Issuing the command with the parameter ‘real’ will always display the original AR488 version string.

Modes: | controller, device
Syntax: | ++ver [real]
- 24 -

Custom commands

This section details ++ commands that are not part of the original Prologix implementation but represent custom commands that have been added and are specific to the AR488 firmware.

++allspoll

Alias equivalent to ++spoll all. See ++spoll for further details.

++dcl

Send Device Clear (DCL) to all devices on the GPIB bus.

Modes: | controller
Syntax: | ++dcl

++default

This command resets the AR488 to its default configuration.

When powered up, the interface will start with default settings in controller mode. However, if the configuration has been saved to EEPROM using the savecfg command, the controller will start with the previously saved settings. This command can be used to reset the controller back to its default configuration.

The interface is set to controller mode with the following parameters:

auto | 0
eoi | 0 (disabled)
eor | 0 (CR+LF)
eos | 0 (CR+LF)
eot_enable | 0 (disabled)
eot_char | 0
GPIB address - controller | 0
GPIB address - primary | 1
GPIB address - secondary | 0
mode | controller
read_tmo_ms | 1200
status byte | 0
version string | default version string
- 25 -

NOTE: Unless the ++savecfg command is used to overwrite the previously saved configuration, the previous configuration will be re-loaded from non-volatile memory the next time that the interface is powered up. To ensure that settings are saved, after using the ++default command, configure the interface as required and then use ++savecfg to save the settings to EEPROM*. The interface can be returned to its default state by using ++default followed by ++savecfg without making any further configuration changes.

* this assumes that the board being used supports saving to EEPROM.

Modes: | controller, device
Syntax: | ++default

++eor

End of receive. While ++eos (end of send) selects the terminator to add to commands and data being sent to the instrument, the ++eor command selects the expected termination sequence when receiving data from the instrument.

The following termination sequences are supported:

Option | Sequence | Hex
0 | CR + LF | 0D 0A
1 | CR | 0D
2 | LF | 0A
3 | None | N/A
4 | LF + CR | 0A 0D
5 | ETX | 03
6 | CR + LF + ETX | 0D 0A 03
7 | EOI signal | N/A

The default termination sequence is CR + LF. If the command is specified with one of the above numeric options, then the corresponding termination sequence will be used to detect the end of the data being transmitted from the instrument. If the command is specified without a parameter, then it will return the current setting. If option 7 (EOI) is selected, then ++read eoi is implied for all ++read instructions as well as any data being retuned by the instrument in response to direct instrument commands. An EOI is expected to be signalled by the instrument with the last character of any transmission sent. All characters sent over the GPIB bus are passed to the serial port for onward transmission to the host computer.

Modes: | controller
Syntax: | ++eor[0-9]
- 26 -

++id

This command sets the identification parameters for the interface. Here you can set the instrument name and optional serial number. This command also sets the information that can be used by the interface to respond to a SCPI *idn? which may be useful where the instrument itself cannot provide such a response. For further information also see the ++idn command.

The command has one of three invocations and an optional parameter:

++id name
This sets a short name for the interface. The name can be up to 15 characters long and should not include spaces. If the command is specified without a parameter, it will return the current name of the interface. By default, the name is not set and the command will not return a value.

++id serial
This sets an optional serial number for the interface. In the event that there are multiple instances of identical instruments on the bus, each instrument can be given a unique serial number up to 9 digits long. When specified without a parameter, the command returns the currently configured serial number. By default the serial number is not set and the command will return ‘000000000’.

++id verstr
Sets the version string that the controller responds with on boot-up and in response to the ++ver command. This may be helpful where software on the computer is expecting a specific string from a known controller, for example ‘GPIB-USB’. When no parameter is given, the command returns the current version string.

Examples:

++id name HP3478A
++id serial 347800001
++id verstr GPIB-USB
++id verstr
Modes: | controller
Syntax: | ++id name [name] ++id serial [serialnum] ++id verstr [version string]

++idn

This command is used to enable the facility for the interface to respond to a SCPI *idn? Command. Some older instruments do no respond to a SCPI ID request but this feature will allow the interface to respond on behalf of the instrument using parameters set with the ++id command. When set to zero, response to the SCPI *idn? command is disabled and the request is passed to the instrument. When set to 1, the interface responds with the name set using the ++idn name command. When set to 2, the instrument also appends the serial number using the format name-99999999.

- 27 -

Modes: | controller
Syntax: | ++idn[0-2]

++macro

Instrument control usually requires a sequence of commands to be sent to the instrument to set it up or to perform a particular task. Where such a sequence of commands is performed regularly and repeatedly, it is beneficial to have a means to pre-program the sequence and to be able to run it with a single command.

The AR488 allows up to 9 sequences to be programmed into the Arduino sketch that can be run using the ++macro command. When no parameters have been specified, the macro command will return a list of numbers indicating which macros have been defined and are available to use.
When called with a single number between 1 and 9 as a parameter, the command will run the specified macro.

Programming macros is beyond the scope of this manual and will be specific to each instrument or implemented programming language or protocol.

Modes: | controller
Syntax: | ++macro [1-9]

++ppoll

When many devices are involved, Parallel Poll is faster than Serial Poll but is not widely used. With a Parallel Poll, the controller can query up to eight devices quite efficiently using the DIO lines. Since there are 8 DIO lines, up to 8 devices can be queried at once. In order to get an unambiguous response, each device should ideally assign to a separate data line. Devices assigned to the same line are simply OR’ed. Devices respond to the parallel poll by asserting the DIO line they have been assigned.

Response to a Parallel Poll is a data byte corresponding to the status of the DIO lines when the Parallel Poll request is raised. The state of each individual bit of the 8-bit byte corresponds to the state of each individual DIO line. In this way it is possible to determine which instrument raised the request.

Because a single bit can only be 0 or 1, the response to a parallel poll is binary, simply indicating whether or not an instrument has raised the request. In order to get further status information, a Serial Poll needs to be conducted on the instrument in question.

Modes: | controller
Syntax: | ++ppoll
- 28 -

++ren

In controller mode, this command turns the REN signal on and off. When REN is asserted, the controller can remote-control any device on the BUS. With the REN signal turned off, the controller can no longer remote-control devices, but can still communicate with them. This is used primarily for diagnostics.

When set to 0, REN is un-asserted. When set to 1, REN is asserted. By default, in controller mode, REN will be asserted.

When REN is used to control the SN75161 GPIB transceiver integrated-circuit, this command is unavailable and will simply return Unavailable. (see the Configuration and the Building an AR488 GPIB Interface sections for more information). When issued without a parameter, the command returns the current status of the REN signal.

Modes: | controller
Syntax: | ++ren [0|1]

++repeat

Provides a way of repeating the same command multiple times, for example, to request multiple measurements from the instrument.

Between 2 and 255 repetitions can be requested. It is also possible to request a delay between 0 to 10,000 milliseconds (or 10 seconds) between each repetition. The parameter buffer has a maximum capacity of 64 characters, so the command string plus any parameters cannot exceed 64 characters in total. Once started, there is no mechanism to stop the repeat loop once it has begun. The command will run the number of iterations requested and stop only when the request is complete.

Modes: | controller
Syntax: | ++repeat count delay cmdstring where: count is the number of repetitions from 2 to 255 delay is the time to wait between repetitions from 0 to 10,000 milliseconds cmdstring is the command to execute

++setvstr

This command is DEPRECATED and will be removed in future versions. Please refer to the notes for the ++id verstr command instead. It sets the version string that the controller responds with on boot-up and in response to the ++ver command. This may be helpful where software on the computer is expecting a specific string from a known controller, for example ‘GPIB-USB’.

The ++ver command can be used to confirm that the string has been set correctly.

- 29 -

Modes: | controller, device
Syntax: | ++verstr [string] where [string] is the new version string

++srqauto

When conducting a serial poll using a Prologix controller, the procedure requires that the status of the SRQ signal be checked with the ++srq command. If the response is a 1, indicating that SRQ is asserted, then an ++spoll command can be issued to determine the status byte of the currently addressed instrument or optionally an instrument at a specific GPIB address.

When polling multiple devices, the AR488 will provide a custom response that includes the address and status byte of the first instrument encountered that has the RQS bit set. Usually, the ++spoll command has to be issued manually to obtain this information.

When ++srqauto is set to 0 (default), in order to obtain the status byte when SRQ is asserted, a serial poll has to be conducted manually using the ++spoll command.

When ++srqauto is set to 1, the interface will automatically detect when the SRQ signal has been asserted by an instrument and will automatically conduct a serial poll, returning the address and status byte of the first instrument encountered that has the RQS bit set in its status byte. If multiple instruments have asserted SRQ, then another subsequent serial poll will be conducted to determine the next instrument that has requested service. The process continues until all instruments that have requested service have had their status byte read and the SRQ signal has been cleared.

Without parameters, this command returns the present status of the SRQauto. It returns 0 if a serial poll is not automatically executed (default) and 1 if a serial poll is automatically executed.

Modes: | controller
Syntax: | ++srqauto [0|1] where 0=disabled, 1=enabled

++tmbus

The GPIB bus protocol is designed to allow the bus to synchronise to the speed of the slowest device. However, under some circumstances it may be desirable to slow down the bus. The tmbus parameter introduces a periodic delay of between 0 to 30,000 microseconds between certain operations on the bus and so slows down the operation of the GPIB bus. The greater the delay, the slower the bus will operate. Under normal running conditions this parameter should be set to zero, which is the default setting.

Modes: | controller, device
Syntax: | ++tmbus [value] where [value] is between 0 and 30,000 microseconds
- 30 -

++ton

The ++ton command configures the controller to send data only on the GPIB bus. When in this mode, the interface does not require to have a GPIB address assigned and the address that is set will be ignored. Data is placed on the GPIB bus as soon as it is received via USB. Only one sender can exist on the bus, but multiple receivers can listen to and accept the transmitted data. The interface can send, but not receive, so effectively becomes a “talk-only” device. When issued without a parameter, the command returns the current state of “ton” mode.

Modes: | device
Syntax: | ++ton [0|1] where 0=disabled; 1=enabled

++verbose

Toggle verbose mode ON and OFF

Modes: | controller, device
Syntax: | ++verbose
- 31 -

## Building an AR488 GPIB Interface

Construction of an Arduino GPIB interface is relatively straightforward and requires a single Arduino UNO, NANO or MEGA2560 board, a length of cable that is at minimum 16-way and preferably screened, and an IEEE488 connector. An old GPIB cable could be re-purposed by removing one end, or an old parallel printer cable could be used, in which case a separate 24-way IEEE488 connector will need to be purchased.

New GPIB/IEEE488 cables are expensive. Cheaper cables can be found from various sellers on eBay. Connectors can be found by searching for ‘Centronics 24’ rather than ‘IEEE488’ or ‘GPIB’. In the UK, RS Components sell these as part number 239-1207, for £2.86. They can also be found on eBay. Old parallel printer cables can still be found on charity/thrift shops or on market stalls.

For connection details and wiring diagrams for specific boards, please see:

Appendix A – Uno and Nano
Appendix B – Mega 2560
Appendix C – Micro 32u4

Ideally, in a GPIB cable, ground pins 18, 19, 20, 21, 22, 23 should be connected to a ground wire that forms a twisted pair with the DAV, NRFD, NDAC, IFC, SRQ and ATN control wires, and a shielded twisted pair cable with sufficient multiple pairs would be required. However, if such a cable is not available, then linking them together and connecting them to GND on the Arduino side should suffice, especially if sufficient numbers of conductors are not available.

Further information can be found by following the links below:

Additional GPIB pinout information - Link 1 (https://www.electronics-notes.com/articles/test-methods/gpib-ieee-488-bus/pinout-pin-connections.php)
Additional GPIB pinout information - Link 2 (https://allpinouts.org/pinouts/connectors/buses/ieee-488-gpib-hpib/)

Once the cable has been completed, the sketch should then be downloaded to the Arduino board and the interface should be ready to test. In order to provide multi-platform compatibility, the AR488 firmware sketch is modular and comes in several files:

Filename: | Purpose:
AR488.ino | This is the main AR488 firmware sketch
AR488_Config.h | This is the configuration file. All configuration options are set here.
AR488_Hardware.h | This is the hardware support C++ header file
AR488_Hardware.cpp | This is the hardware support C++ program file

The firmware is supplied in a ZIP file. Download and unpack all files into a directory called AR488. Load the main sketch, AR488.ino into the Arduino IDE. This should open all files into separate tabs. Edit AR488_Config.h as required and save. Then select the correct board from the list of boards
within the Arduino IDE, Tools | Board menu option and compile and upload the sketch.
- 32 -

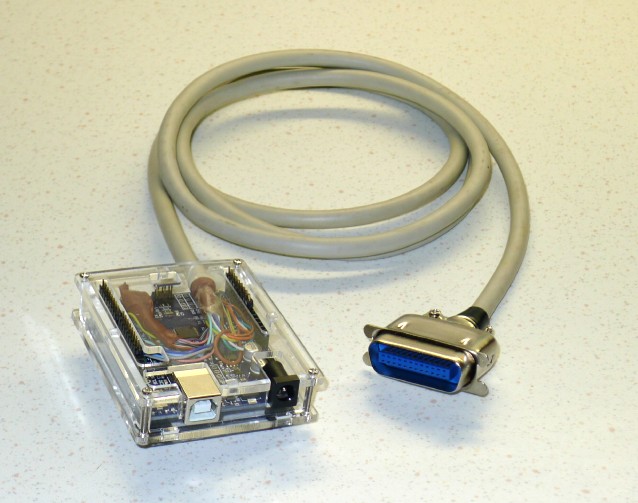
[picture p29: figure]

An example of a completed Arduino GPIB adapter

The following section details further hardware tweaks that may be required to make the board work correctly with specific GPIB software.

Multiple Arduinos on the bus and problems with instruments

The AR488 can be used in both controller mode and device mode and only ONE controller can be active at any one time. When there is just one Arduino controller on the bus controlling one or more instruments, this does not present a problem, provided that the Arduino is operating within its current handling limits.

However, it is possible to have one AR488 operating as a controller and another as a device simultaneously on the bus along with other instruments. In this situation and without any additional buffering (see the following section: SN7516x GPIB transceiver integrated circuits), problems can arise when two or more Arduinos are connected to the GPIB bus and one of them is powered down. Such problems are manifest by instruments failing to respond to the ++read or other commands, failing to respond to direct instrument commands, or other erratic bus communication problems.

The reason for this is because when powered down, Arduino control pins do not present with a high impedance. In a powered down state, voltages present on the various signal and data lines are passed via protection diodes internal to the ATMega processor, to the +VCC rail on the powered down interface. This then causes all pins on the unpowered Arduino to effectively go HIGH. Furthermore, enough power may be present on the +VCC rail to at least partially power the processor, which, even if it does manage to operate, is likely to do so in an unpredictable manner the result of which may be the aforementioned interference with the proper functioning of other equipment on the GPIB bus. This is a parasitic power phenomenon that is not specific to Arduino microcontrollers and that affects various other devices also. Further information regarding this phenomenon can be found here:

https://www.eevblog.com/forum/blog/eevblog-831-power-a-micro-with-no-power-pin!/

- 33 -

Consequently, unpowered Arduino devices will adversely affect other devices on the GPIB bus. It is therefore essential to either keep Arduino devices powered on, or physically disconnected from the bus. This is NOT an issue when there is just ONE Arduino-based GPIB controller remotely controlling instruments on a bus. Therefore, other than when an Arduino is operating as a controller, it is not recommended to leave unpowered Arduino’s connected to the bus.

SN7516x GPIB transceiver integrated circuits

The AR488 firmware supports SN75160 and SN75161 GPIB transceiver integrated circuits. These ICs provide a buffer between the Arduino and the GPIB bus and allow the full 48mA drive current for a GPIB device. In addition, when powered down, these devices present a high impedance to the GPIB bus so that the connected device does not interfere with the operation of the bus. This solves the ‘parasitic power’ problem that ocurrs when using Arduinos connected directly without buffering to the the GPIB bus and means that theinterface can be safely powered down without affecting communication on the GPIB bus.

In order to use these GPIB transceiver ICs, at least one SN75160 and one SN75161 will be required and a separate daughterboard will have to be built. The SN75160 provides 3-state outputs for the data bus, whereas the SN75161 provides similar isolation for the GPIB control signals. Connection details can be found in Appendix A, which details connections for the Uno board. A similar approach can be used for any other board using available GPIO pins.

Operation of the SN75160 is simple. The Arduino outputs are connected to the ‘Terminal I/O ports’ side of the IC and the GPIB bus DIO lines to the ‘GPIB I/O ports side. The PE pin should be connected to VCC in order to provide 3-state output. The TE (talk-enable) pin is connected to a GPIO pin on the Arduino. The GPIO pin is defined in Config.h. For further details see the Configuration section.

The operation of the SN75161 is a little more complex as part of the IC is controlled by the TE pin, but also by the DC (direction-control) pin. The TE pin is connected to the same GPIO pin as the 75160 TE pin. The DC pin needs to be driven separately. This can be achieved by connecting DC to a seperate GPIO pin which can also be defined in Config.h. Alternatively, it can be controlled by the REN signal. The REN signal is asserted (LOW) in controller mode and un-asserted (HIGH) in device mode which conveniently corresponds to the drive signal required for DC to switch between controller and device mode. When REN is being used to control DC, it cannot be turned off as this would switch the IC into device mode and communication would fail. For this reason, the ++REN command is not available in this configuration (see ++REN in the Custom Commands section for details on the behaviour of this command).

The SN75162 IC differs from the SN75161 in that the REN and IFC signals are independently controlled. The input required is the inverse of the DC signal. Conceivably a separate GPIO pin could be used to drive the SC pin of the SN75162 but this is currently untested and unsupported. Alternatively some means of hardware inversion could be devised and the pin connected to DC, but in this case, experiment at your own risk.

- 34 -

Arduino brownout detection setting

The first three bits of the Arduino extended fuse determine the brownout detection (BOD) setting. BOD will hold the processor in the reset state when the power rail voltage falls below a specific threshold. There are three threshold levels that can be set depending on the bits that is set.

On the boards that were used for development, the default setting of the Extended Fuse seems to be FD, which means that the last three bits will be 101 and therefore that the BOD level is set to BODLEVEL1.

It has been reported that when BOD is disabled (e.g. fuse set to FF) and the Arduino signal pins are connected to power, that under some circumstances the Arduino flash memory can get corrupted and the sketch will have to be downloaded again. It is therefore inadvisable to disable BOD on an Arduino being used as a GPIB interface.

Arduino BOD settings are as follows:

BOD Level: | Bit setting | Threshold
DISABLED | 111 | BOD disabled
BODLEVEL0 | 110 | 1.7 – 2.0v (avg 1.8v)
BODLEVEL1 | 101 | 2.5 – 2.9v (avg 2.7v)
BODLEVEL2 | 100 | 4.1 – 4.5v (avg 4.3v)

To check the extended fuse setting, the following AVRDUDE command line can be used:

UNO/NANO:
avrdude -P /dev/ttyACM0 -b 19200 -c usbasp -p m328p -v

MEGA 2560:
avrdude -P /dev/ttyACM0 -b 115200 -c usbasp -p m2560 -v
MEGA 32u4:
avrdude -P /dev/ttyACM0 -b 115200 -c usbasp -p m32u4 -v

The ATMega328p part can be specified as -p m328p or -p atmega328p. The Mega 2560 and Mega 32u4 can also be specified using either convention. If your Arduino has a 328pb processor IC, then this will have a different signature to the 328p and the -p parameter needs to be specified as -p m328pb or -p atmega328pb.

- 35 -

## Working with EZGPIB and KE5FX

FTDI serial vs CH340G serial

EZGPIB is an IDE programming environment that can be used to work with GPIB devices. KE5FX provides testing tools that can be used with various instruments that support GPIB. Both programs support the Prologix interface and when communicating with it, both programs assert RTS and expect a CTS response to confirm that the interface is ready to accept data.

The CH340G chipset present in many Arduino compatible boards does not respond with the CTS signal. There appear to be two possible workarounds, one of which requires very good soldering skills. The RTS and CTS signals are exposed via pins 14 and 9 respectively on the CH340G chip. While pin 9 connects to an easily accessible pad for soldering, pin 14 is not connected to anywhere and because it is very small, attaching a wire to it is rather tricky. For this reason, workaround 2 is easier to implement. Disclaimer: please proceed only if you are confident in your soldering skills. I take no responsibility for damaged Arduino boards so if in doubt, ask a qualified or skilled person for assistance.

Workaround 1

The workaround requires that pin 14 be connected to pin 9 on the CH340G chip. When RTS is asserted by the host over USB, the signal is passed to the RTS output on pin 14 of the CH340G. This signal would ordinarily be passed to a serial hardware device which would respond by sending a response to the CTS input on pin 9 of the the CH340G to indicate that it is ready to send. The workaround passes this signal back to the CTS input via the link so that a CTS response will always be echoed back to the host over USB. While this does not provide proper RTS/CTS handshaking, it does allow the interface to respond with a CTS signal and, in turn, the host to be able to accept responses to the commands sent to the interface, even when RTS/CTS handshaking is used.

Workaround 2

Pin 9 of the CH340G needs to be connected to GND. This will keep CTS signal asserted on the Arduino at all times, so again, proper handshaking is not provided. Simply solder a short wire to the pad and connect to a convenient ground point.

A big thanks goes to Hartmut Päsler, who is currently looking after the EZGPIB program, for informing me that the CH340G exposes the RTS/CTS signals via pins and that it might be possible to make use of these pins to devise a solution.

Where Arduino boards are recognized as FTDI serial devices, the functionality is embedded within the ATMEGA MEGA 16U2 chip. This chip does not expose the RTS/CTS signals so this modification is not possible nor is it required to work with the KE5FX toolkit. An Arduino board running with the 16U2 chip running AR488 will work fine with the KE5FX GPIB toolkit, but for some reason, it is not recognized by the EZGPIB program.

- 36 -

EZGPIB and the Arduino bootloader

On older Arduino boards it was necessary to press the reset button to program the board. This causes the board to reset and the bootloader to run. The bootloader will expect a particular sequence of bytes within a timeout period and it will then expect a new compiled sketch to be uploaded into memory. On completion of the upload, program control is passed to the newly uploaded code. The timing of the upload is rather tricky and if the timeout period expires or the upload is started too soon, then it will fail and the board will start with the current program code.

Current versions of the board allow code to be uploaded via USB without having to use the reset button. This is accomplished by triggering a reset of the board each time a serial connection is opened. The bootloader is then re-loaded and if the required sequence of bytes is received, and an upload of code proceeds automatically. When this is finished, program execution passes to the new code as before.

The problem with this is that the bootloader is loaded every time that the serial port is opened. This causes a delay of about 1 second before the compiled user program is actually run and the interface is initialised. EZGPIB (and possibly other programs) that do not re-try the connection attempt after waiting a second or so, fails to establish a connection to the interface. Closing the program and immediately trying again usually results in a successful connection.

The solution is to eliminate the delay caused by the board re-starting and the bootloader being re-loaded into memory. This can be done quite easily by placing a 10μF capacitor between the RST F capacitor between the RST and GND pins on the Arduino. This causes the reset pulse, which is generated by activating the serial DTR signal, to be drained to ground without affecting the RESET input on the AtMega328P processor. Since it’s a capacitor, there is no direct DC coupling between RESET and GND. When the serial port is now opened, the interface will just respond without the delay caused by re-booting. Assuming the sequence “GPIB-USB” exists in the response to the ++ver command, EZGPIB will now recognize it first time.

The drawback of this approach is that placing a capacitor permanently in this position will prevent the Arduino IDE from being able to program the board. The reset button now has to be used or a switch added to provide an on to run, off to program facility.

Hacking the Ezgpib binary

If you are familiar with using a hex editor, there is another approach that involves editing the EZGPIB.EXE binary to prevent it looking for an RTS signal being asserted. If the standard Windows USBSER.SYS driver is used, this never happens, so EZGPIB will never find the GPIB adapter. This workaround involves changing a specific byte in the RTS Check routine.

Open up a copy of EXGPIB.EXE version 20121217 in a hex editor. Look for the HEX sequence:

F6 04 24 10 74 06

Note, that these instructions can also be found on http://www.dalton.ax/gpib/, but show the sequence as F6 02 24 10 74 06. I found the sequence to be as above. I’m not sure whether this is an error or because my binary is different from the one that the author was working with. If you can’t find the sequence with 04, check for the one with 02.

- 37 -

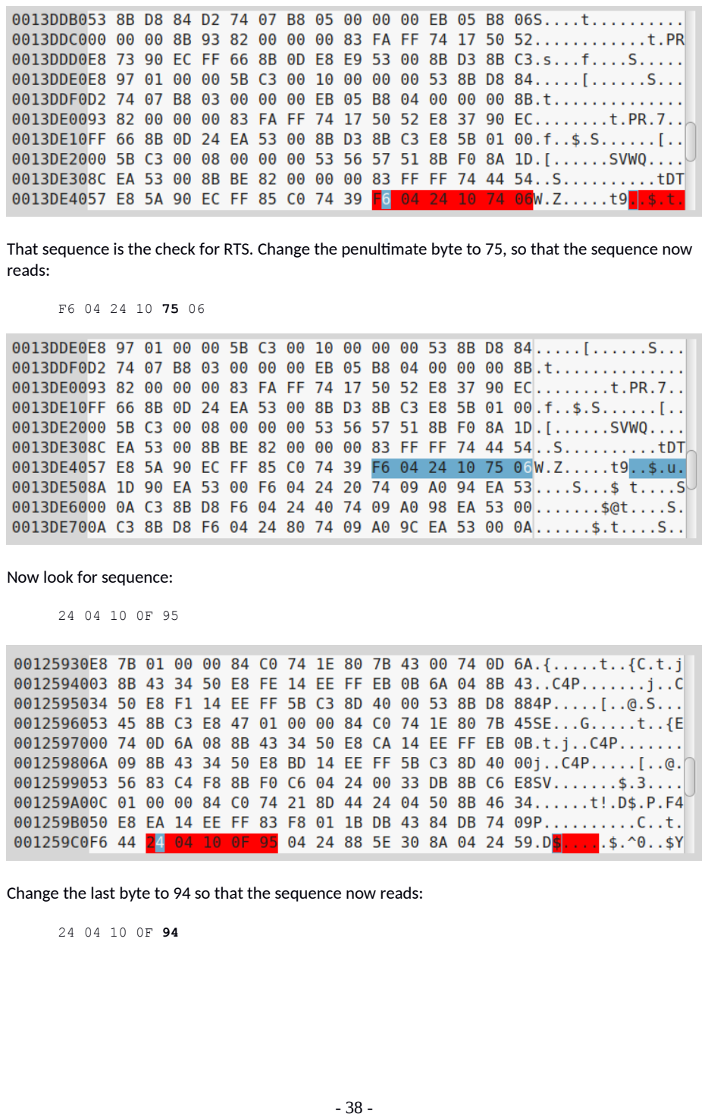
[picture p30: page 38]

That sequence is the check for RTS. Change the penultimate byte to 75, so that the sequence now reads:

F6 04 24 10 75 06

Now look for sequence:

24 04 10 0F 95

Change the last byte to 94 so that the sequence now reads:

24 04 10 0F 94

- 38 -

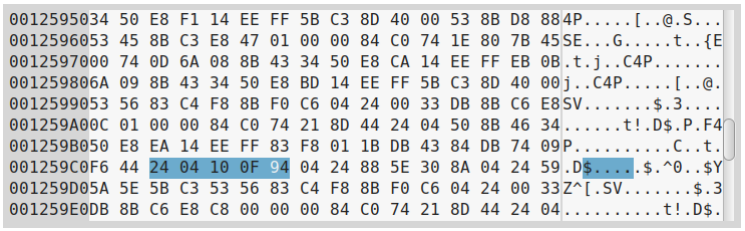
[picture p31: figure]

Save the file and close the hex editor. EZGPIB should now find your adapter.

- 39 -

Appendix A – Connection and technical information for Uno and Nano boards

Connection details:

These connections are required between the Arduino UNO/Nano and the IEEE488 connector:

Arduino: | GPIB connector: | Function:
D2 | 10 | SRQ
D3 | 17 | REN
D7 | 11 | ATN
D8 | 9 | IFC
D9 | 8 | NDAC
D10 | 7 | NRFD
D11 | 6 | DAV
D12 | 5 | EOI
A0 | 1 | DIO1
A1 | 2 | DIO2
A2 | 3 | DIO3
A3 | 4 | DIO4
A4 | 13 | DIO5
A5 | 14 | DIO6
D4 | 15 | DIO7
D5 | 16 | DIO8
GND | 12 | Shield
GND | 18,19,20,21,22,23 | GND
- 40 -

Wiring diagram:

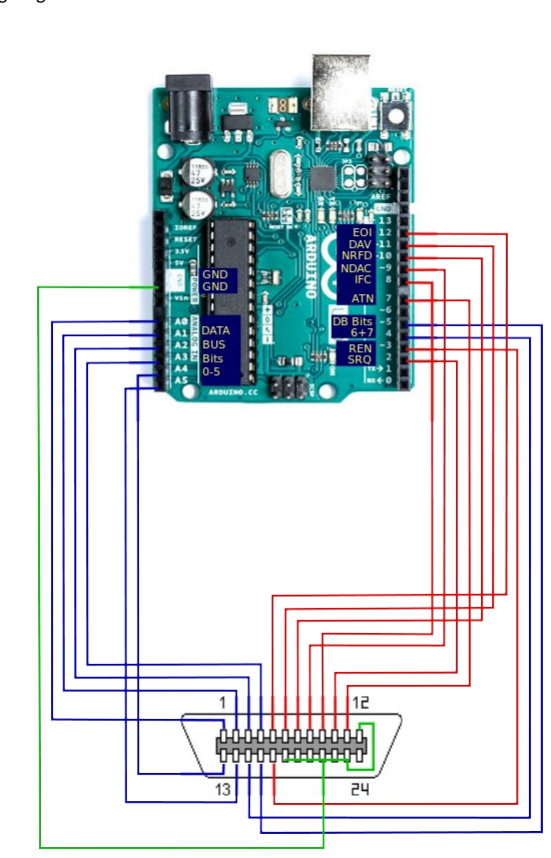
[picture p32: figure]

When using SN75160 and SN75161 integrated circuits, the connections involve at least one extra pin to control the talk-enable (TE) pin of the IC. The PE pin on the SN75160 is connected to VCC to maintain a 3-state outputs when TE is high. Connecting PE to ground will allow the outputs to function in pullup-enable mode when TE is high.

- 41 -

On the SN75161, the DC pin can be connected to a separate GPIO pin on the Uno/Nano, or, since ren is always asserted when in controller mode and de-asserted in device mode, to the GPIO pin used for the REN signal.

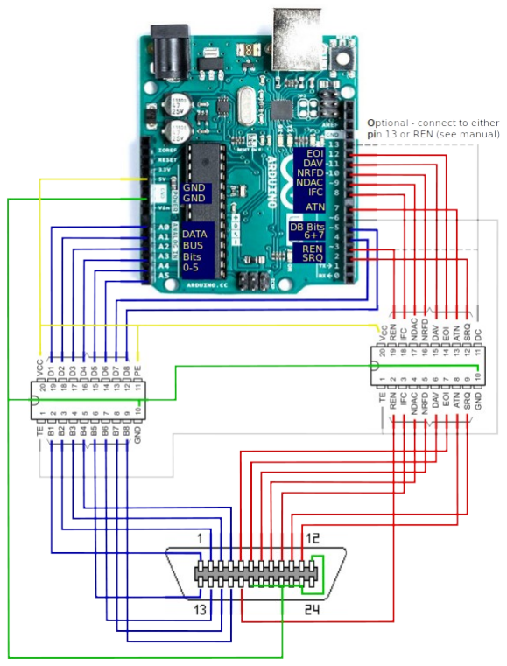
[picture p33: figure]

- 42 -

Appendix B – Connection and technical information for Mega 2560 boards

Connection details:

The pinout on the Mega 2560 is as follows:

Arduino: | GPIB connector: | Function:
D6 | 7 | NRFD
D7 | 6 | DAV
D8 | 5 | EOI
D9 | 17 | REN
D10 | 10 | SRQ
D11 | 11 | ATN
D16 | 8 | NDAC
D17 | 9 | IFC
A0 | 1 | DIO1
A1 | 2 | DIO2
A2 | 3 | DIO3
A3 | 4 | DIO4
A4 | 13 | DIO5
A5 | 14 | DIO6
A6 | 15 | DIO7
A7 | 16 | DIO8
GND | 12 | Shield
GND | 18,19,20,21,22,23 | GND

The layout on the Mega was chosen so as to leave pins A8-A15 and the two rows of pins at the top of the board free for expansion including for displays and other peripherals.

Pins 16 and 17 correspond to Serial2. As these have been used for controlling signals on the GPIB bus, they cannot be used for serial communication. If Serial2.begin is added to the sketch, these pins will be enabled for serial communication and will no longer function as GPIB control signals. In addition to the default serial port (RX0 and TX0), Serial1 and Serial3 are still available for expansion if required. These two pins were chosen for GPIB signals as they belong to port H along with pins 6 – 9.

- 43 -

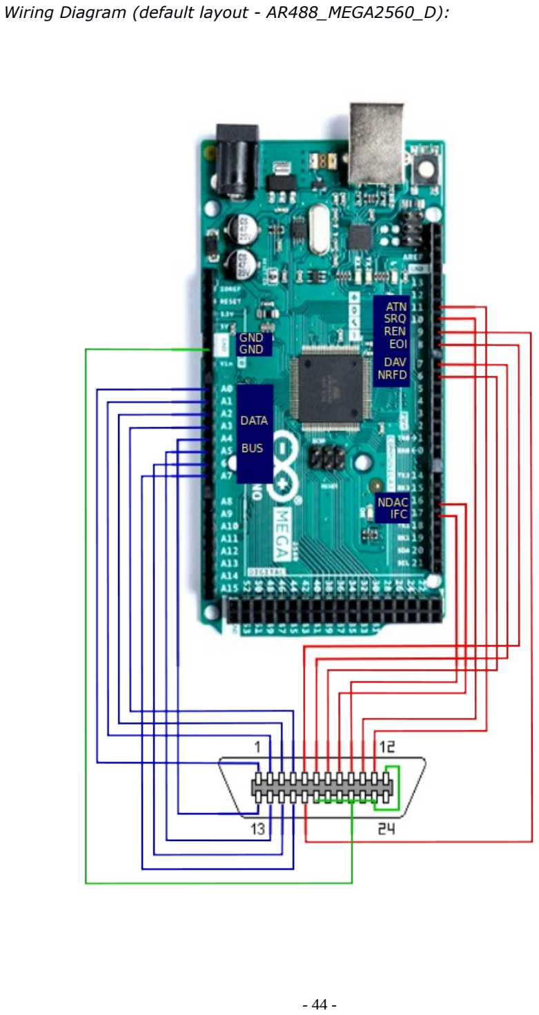
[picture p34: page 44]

### Wiring Diagram (default layout - AR488_MEGA2560_D):

- 44 -

### Wiring Diagram (layout E1 and E2):

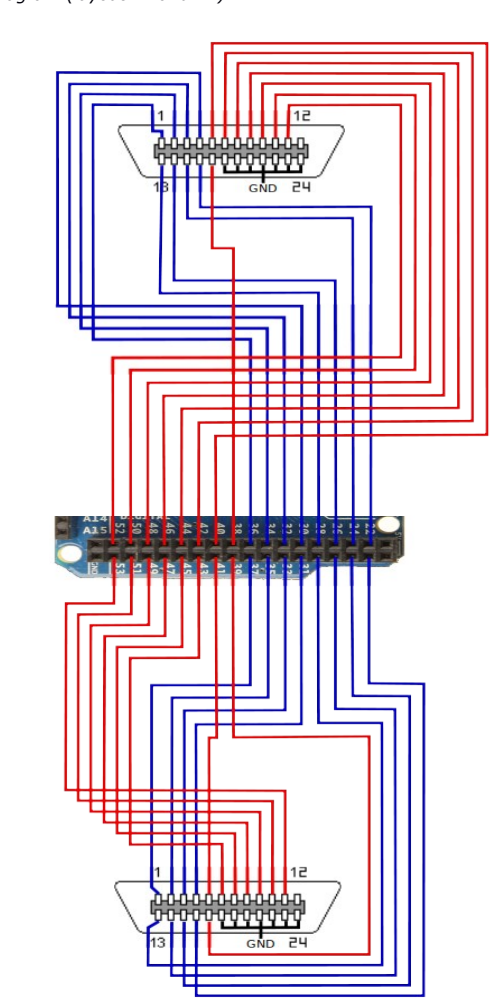
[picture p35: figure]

- 45 -

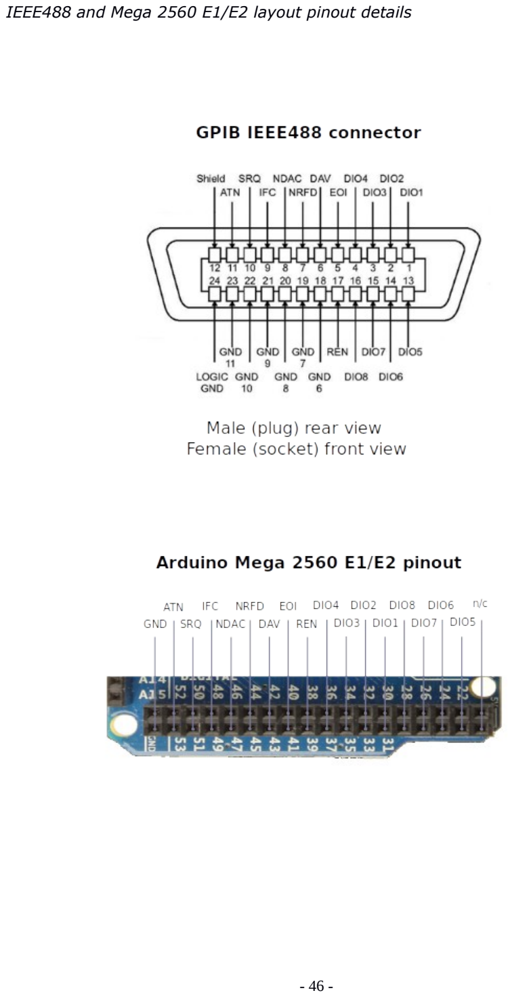
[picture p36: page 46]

### IEEE488 and Mega 2560 E1/E2 layout pinout details

- 46 -

Appendix C – Connection and technical information for 32u4 based boards

Micro Connection details:

The pinout on the Micro is as follows:

Arduino: | GPIB connector: | Function:
A2 | 7 | NRFD
A1 | 6 | DAV
A0 | 5 | EOI
D5 | 17 | REN
D7 | 10 | SRQ
D2 | 11 | ATN
A3 | 8 | NDAC
D4 | 9 | IFC
D3 | 1 | DIO1
D15 | 2 | DIO2
D16 | 3 | DIO3
D14 | 4 | DIO4
D8 | 13 | DIO5
D9 | 14 | DIO6
D10 | 15 | DIO7
D6 | 16 | DIO8
GND | 12 | Shield
GND | 18,19,20,21,22,23 | GND

The Micro is a very small form factor board that can be adapted to fit on the back of an IEEE488 connector. The design was contributed by Artag:

https://www.eevblog.com/forum/projects/ar488-arduino-based-gpib-adapter/msg2718346/#msg2718346

Adapter boards are available from:
https://oshpark.com/shared_projects/HrS1HLSE
- 47 -

Leonardo R3 Connection details:

The pinout on the Leonardo R3 is as follows:

Arduino: | GPIB connector: | Function:
D2 | 10 | SRQ
D3 | 17 | REN
D7 | 11 | ATN
D8 | 9 | IFC
D9 | 8 | NDAC
D10 | 7 | NRFD
D11 | 6 | DAV
D12 | 5 | EOI
A0 | 1 | DIO1
A1 | 2 | DIO2
A2 | 3 | DIO3
A3 | 4 | DIO4
A4 | 13 | DIO5
A5 | 14 | DIO6
D4 | 15 | DIO7
D5 | 16 | DIO8
GND | 12 | Shield
GND | 18,19,20,21,22,23 | GND

The Leonardo R3 has a similar form factor to the Uno. It uses a 32u4 MCU rather than a 328P and has a micro USB port. Instead of a CH340 UART it uses USB CDC emulated serial ports and has one separate hardware serial port available on on RX1 and TX1, whereas the Uno shares these pins with USB. It requires no modification to work with KE5FX tools. The board pin layout is the same as the Uno and the above pinout is identical to the Uno.

- 48 -

Appendix D – XDIAG command notes

The ++xdiag command can be used to test that individual lines are being asserted / unasserted. The command takes two parameters: mode and value. To manipulate control lines use mode 1, and for data lines use mode 0. To assert a line/data bit, simply speciy one of the values in the table below. To assert multiple lines/bits simultaneously, simply add the values. To un-assert a line, subtract its value from 255 The following two tables list the GPIB signals and the command used to assert them.

Command signals:

Assert IFC | ++xdiag 1 1
Assert NDAC | ++xdiag 1 2
Assert NRFD | ++xdiag 1 4
Assert DAV | ++xdiag 1 8
Assert EOI | ++xdiag 1 16
Assert REN | ++xdiag 1 32
Assert SRQ | ++xdiag 1 64
Assert ATN | ++xdiag 1 128
Assert ALL | ++xdiag 1 255
Un-assert ALL | ++xdiag 1 0

Data bits:

Assert DA01 | ++xdiag 0 1
Assert DA02 | ++xdiag 0 2
Assert DA03 | ++xdiag 0 4
Assert DA04 | ++xdiag 0 8
Assert DA05 | ++xdiag 0 16
Assert DA06 | ++xdiag 0 32
Assert DA07 | ++xdiag 0 64
Assert DA08 | ++xdiag 0 128
Assert ALL | ++xdiag 0 255
Un-assert ALL | ++xdiag 0 0
- 49 -

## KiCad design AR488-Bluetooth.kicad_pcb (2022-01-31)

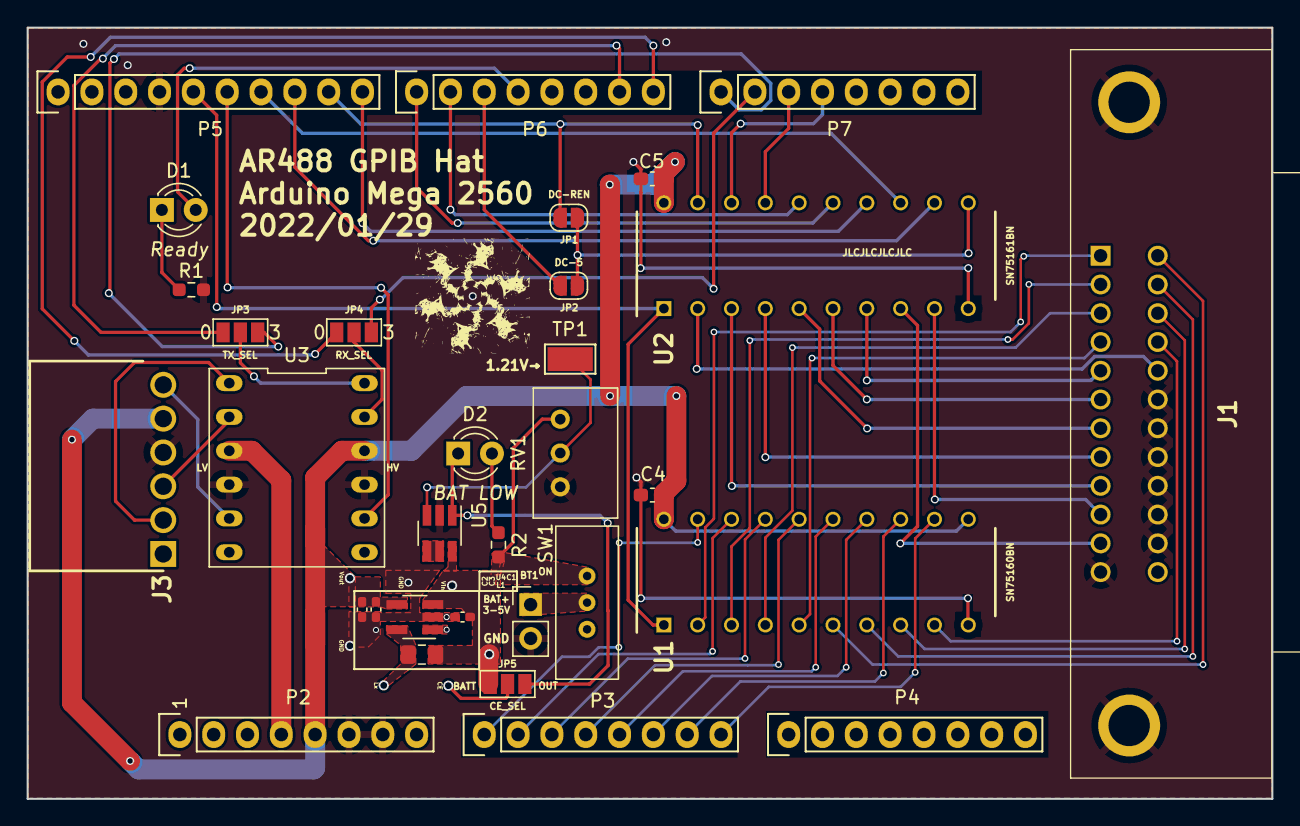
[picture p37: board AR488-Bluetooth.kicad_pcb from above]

Board: 2 copper layers, 93.5 x 57.9 mm, 32 parts (0 on the bottom side), 58 nets.

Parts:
BT1: Battery; PinHeader_1x02_P2.54mm_Vertical
C1, C2, C3: 10u; C_0402_1005Metric_Pad0.74x0.62mm_HandSolder
C4, C5: 0.1u; C_0603_1608Metric_Pad1.08x0.95mm_HandSolder
D1: Ready; LED_D3.0mm
D2: BAT LOW; LED_D3.0mm
J1: 112-024-213R001; 112024213R001
J3: HC-05; RHDRRA6W79P0X254_1X6_1575X851X241P
JP1: DC-REN; SolderJumper-2_P1.3mm_Open_RoundedPad1.0x1.5mm
JP2: DC-5; SolderJumper-2_P1.3mm_Open_RoundedPad1.0x1.5mm
JP3: TX_SEL; SolderJumper-3_P1.3mm_Open_Pad1.0x1.5mm_NumberLabels
JP4: RX_SEL; SolderJumper-3_P1.3mm_Open_Pad1.0x1.5mm_NumberLabels
JP5: CE_SEL; SolderJumper-3_P1.3mm_Open_Pad1.0x1.5mm_NumberLabels
L1: 4.7u; L_0805_2012Metric_Pad1.15x1.40mm_HandSolder
P2: Power; Socket_Strip_Arduino_1x08
P3, P4: Analog; Socket_Strip_Arduino_1x08
P5: PWM; Socket_Strip_Arduino_1x10
P6: PWM; Socket_Strip_Arduino_1x08
P7: Communication; Socket_Strip_Arduino_1x08
R1, R2: 1k; R_0603_1608Metric_Pad0.98x0.95mm_HandSolder
RV1: 5M; Potentiometer_Bourns_3299W_Vertical
SW1: SW_SPDT; STSSS9121
TP1: TestPoint; TestPoint_Keystone_5015_Micro-Minature
U1: SN75160BN; DIP794W53P254L2540H508Q20N
U2: SN75161BN; DIP794W53P254L2540H508Q20N
U3: Level_Shifter; DIP-12_400_ELL
U4: XC9141B50CMR-G; SOT-23-5_HandSoldering
U5: MCP65R41T-1202E/CHY; SOT-23-6_Handsoldering

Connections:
+3V3: P2.4, U3.3 (LV)
+5V: C2.1, C3.1, C4.1, C5.1, J3.5, P2.5, U1.11 (~PE), U1.20 (VCC), U2.20 (VCC), U3.10 (HV), U4.4 (Vout)
+BATT: C1.1, JP5.1 (A), L1.1, R2.1, RV1.1, SW1.3 (C), U4.3 (BAT), U5.6 (VDD)
/0(Rx0): JP4.1 (A), P6.8
/1(Tx0): JP3.1 (A), P6.7
/4(**): D1.2 (A), P6.4
/5(**): JP2.2 (B), P6.3
/6(**): P6.2, U2.16 (NRFD_2)
/7(**): P6.1, U2.15 (DAV_2)
/8(**): P5.10, U2.14 (EOI_2)
/9(**): JP1.2 (B), P5.9, U2.19 (REN_2)
/10(**): P5.8, U2.12 (SRQ_2)
/11(**): P5.7, U2.13 (ATN_2)
/12(**): P5.6, U3.8 (HV3)
/13(**): P5.5, U1.1 (TE), U2.1 (TE)
/14(Tx3): JP3.3 (B), P7.1
/15(Rx3): JP4.3 (B), P7.2
/16(Tx2): P7.3, U2.17 (NDAC_2)
/17(Rx2): P7.4, U2.18 (IFC_2)
/A0: P3.1, U1.19 (D1)
/A1: P3.2, U1.18 (D2)
/A2: P3.3, U1.17 (D3)
/A3: P3.4, U1.16 (D4)
/A4: P3.5, U1.15 (D5)
/A5: P3.6, U1.14 (D6)
/A6: P3.7, U1.13 (D7)
/A7: P3.8, U1.12 (D8)
/BAT_IN: BT1.1 (+), SW1.2 (B)
/CE: JP5.2 (C), U4.1 (CE)
/CE_OUT: D2.1 (K), JP5.3 (B), U5.1 (OUT)
/EN: J3.6, U3.5 (LV3)
/GPIB1: J1.1 (GPIB1), U1.2 (B1)
/GPIB2: J1.2 (GPIB2), U1.3 (B2)
/GPIB3: J1.3 (GPIB3), U1.4 (B3)
/GPIB4: J1.4 (GPIB4), U1.5 (B4)
/GPIB5: J1.5 (GPIB5), U2.7 (EOI_1)
/GPIB6: J1.6 (GPIB6), U2.6 (DAV_1)
/GPIB7: J1.7 (GPIB7), U2.5 (NRFD_1)
/GPIB8: J1.8 (GPIB8), U2.4 (NDAC_1)
/GPIB9: J1.9 (GPIB9), U2.3 (IFC_1)
/GPIB10: J1.10 (GPIB10), U2.9 (SRQ_1)
/GPIB11: J1.11 (GPIB11), U2.8 (ATN_1)
/GPIB13: J1.13 (GPIB13), U1.6 (B5)
/GPIB14: J1.14 (GPIB14), U1.7 (B6)
/GPIB15: J1.15 (GPIB15), U1.8 (B7)
/GPIB16: J1.16 (GPIB16), U1.9 (B8)
/GPIB17: J1.17 (GPIB17), U2.2 (REN_1)
/IN+: RV1.2, TP1.1, U5.3 (+IN)
/IN-: U5.4 (-IN), U5.5 (Vref)
/Lx: L1.2, U4.5 (Lx)
/RXD: J3.2, U3.1 (LV1)
/TXD: J3.3, U3.2 (LV2)
GND: BT1.2 (-), C1.2, C2.2, C3.2, C4.2, C5.2, J1.12 (GPIB12), J1.18 (GPIB18), J1.19 (GPIB19), J1.20 (GPIB20), J1.21 (GPIB21), J1.22 (GPIB22), J1.23 (GPIB23), J1.MH1, J1.MH2, J3.4, P2.6, P2.7, P5.4, R1.2, RV1.3, U1.10 (GND), U2.10 (GND), U3.4 (LGND), U3.9 (HGND), U4.2 (GND), U5.2 (VSS)
unnamed: D1.1 (K), R1.1
unnamed: D2.2 (A), R2.2
unnamed: JP1.1 (A), JP2.1 (A), U2.11 (DC)
unnamed: JP3.2 (C), U3.12 (HV1)
unnamed: JP4.2 (C), U3.11 (HV2)

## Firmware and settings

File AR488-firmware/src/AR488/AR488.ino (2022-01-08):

// #pragma GCC diagnostic push
// #pragma GCC diagnostic ignored "-Wtype-limits"
// #pragma GCC diagnostic ignored "-Wunused-variable"

#ifdef __AVR__
  #include <avr/wdt.h>
#endif

// #pragma GCC diagnostic pop

#include "AR488_Config.h"
#include "AR488_Layouts.h"
#include "AR488_Eeprom.h"

#ifdef USE_INTERRUPTS
  #ifdef __AVR__
    #include <avr/interrupt.h>
  #endif
#endif
#ifdef E2END
  #include <EEPROM.h>

#endif

#ifdef AR_BT_EN
  #include "AR488_BT.h"
#endif


/***** FWVER "AR488 GPIB controller, ver. 0.49.14, 02/03/2021" *****/

/*
  Arduino IEEE-488 implementation by John Chajecki

  Inspired by the original work of Emanuele Girlando, licensed under a Creative
  Commons Attribution-NonCommercial-NoDerivatives 4.0 International License.
  Any code in common with the original work is reproduced here with the explicit
  permission of Emanuele Girlando, who has kindly reviewed and tested this code.

  Thanks also to Luke Mester for comparison testing against the Prologix interface.
  AR488 is Licenced under the GNU Public licence.

  Thanks to 'maxwell3e10' on the EEVblog forum for suggesting additional auto mode
  settings and the macro feature.

  Thanks to 'artag' on the EEVblog forum for providing code for the 32u4.
*/

/*
   Implements most of the CONTROLLER functions;
   Substantially compatible with 'standard' Prologix "++" commands
   (see +savecfg command in the manual for differences)

   Principle of operation:
   - Commands received from USB are buffered and whole terminated lines processed
   - Interface commands prefixed with "++" are passed to the command handler
   - Instrument commands and data not prefixed with '++' are sent directly to the GPIB bus.
   - To receive from the instrument, issue a ++read command or put the controller in auto mode (++auto 1|2)
   - Characters received over the GPIB bus are unbuffered and sent directly to USB
   NOTES:
   - GPIB line in a HIGH state is un-asserted
   - GPIB line in a LOW state is asserted
   - The ATMega processor control pins have a high impedance when set as inputs
   - When set to INPUT_PULLUP, a 10k pull-up (to VCC) resistor is applied to the input
*/

/*
   Standard commands

   ++addr         - display/set device address
   ++auto         - automatically request talk and read response
   ++clr          - send Selected Device Clear to current GPIB address
   ++eoi          - enable/disable assertion of EOI signal
   ++eos          - specify GPIB termination character
   ++eot_enable   - enable/disable appending user specified character to USB output on EOI detection
   ++eot_char     - set character to append to USB output when EOT enabled
   ++ifc          - assert IFC signal for 150 miscoseconds - make AR488 controller in charge
   ++llo          - local lockout - disable front panel operation on instrument
   ++loc          - enable front panel operation on instrument
   ++lon          - put controller in listen-only mode (listen to all traffic)
   ++mode         - set the interface mode (0=controller/1=device)
   ++read         - read data from instrument
   ++read_tmo_ms  - read timeout specified between 1 - 3000 milliseconds
   ++rst          - reset the controller
   ++savecfg      - save configration
   ++spoll        - serial poll the addressed host or all instruments
   ++srq          - return status of srq signal (1-srq asserted/0-srq not asserted)
   ++status       - set the status byte to be returned on being polled (bit 6 = RQS, i.e SRQ asserted)
   ++trg          - send trigger to selected devices (up to 15 addresses)
   ++ver          - display firmware version
*/

/*
   Proprietry commands:

   ++aspoll       - serial poll all instruments (alias: ++spoll all)
   ++default      - set configuration to controller default settings
   ++dcl          - send unaddressed (all) device clear  [power on reset] (is the rst?)
   ++id name      - show/set the name of the interface
   ++id serial    - show/set the serial number of the interface
   ++id verstr    - show/set the version string (replaces setvstr)
   ++idn          - enable/disable reply to *idn? (disabled by default)
   ++ren          - assert or unassert the REN signal
   ++ppoll        - conduct a parallel poll
   ++setvstr      - set custom version string (to identify controller, e.g. "GPIB-USB"). Max 47 chars, excess truncated.
   ++srqauto      - automatically condiuct serial poll when SRQ is asserted
   ++ton          - put controller in talk-only mode (send data only)
   ++verbose      - verbose (human readable) mode
*/

/*
   NOT YET IMPLEMENTED

   ++help     - show summary of commands
   ++myaddr   - set the controller address
*/

/*
   For information regarding the GPIB firmware by Emanualle Girlando see:
   http://egirland.blogspot.com/2014/03/arduino-uno-as-usb-to-gpib-controller.html
*/


/*
   Pin mapping between the Arduino pins and the GPIB connector.
   NOTE:
   GPIB pins 10 and 18-24 are connected to GND
   GPIB pin 12 should be connected to the cable shield (might be n/c)
   Pin mapping follows the layout originally used by Emanuelle Girlando, but adds
   the SRQ line (GPIB 10) on pin 2 and the REN line (GPIB 17) on pin 13. The program
   should therefore be compatible with the original interface design but for full
   functionality will need the remaining two pins to be connected.
   For further information about the AR488 see:
*/


/*********************************/
/***** CONFIGURATION SECTION *****/
/***** vvvvvvvvvvvvvvvvvvvvv *****/
// SEE >>>>> Config.h <<<<<
/***** ^^^^^^^^^^^^^^^^^^^^^ *****/
/***** CONFIGURATION SECTION *****/
/*********************************/


/***************************************/
/***** MACRO CONFIGURATION SECTION *****/
/***** vvvvvvvvvvvvvvvvvvvvvvvvvvv *****/
// SEE >>>>> Config.h <<<<<
/***** ^^^^^^^^^^^^^^^^^^^^^^^^^^^ *****/
/***** MACRO CONFIGURATION SECTION *****/
/***************************************/


/*************************************/
/***** MACRO STRUCTRURES SECTION *****/
/***** vvvvvvvvvvvvvvvvvvvvvvvvv *****/
#ifdef USE_MACROS

/*** DO NOT MODIFY ***/
/*** vvvvvvvvvvvvv ***/

/***** STARTUP MACRO *****/
const char startup_macro[] PROGMEM = {MACRO_0};

/***** Consts holding USER MACROS 1 - 9 *****/
const char macro_1 [] PROGMEM = {MACRO_1};
const char macro_2 [] PROGMEM = {MACRO_2};
const char macro_3 [] PROGMEM = {MACRO_3};
const char macro_4 [] PROGMEM = {MACRO_4};
const char macro_5 [] PROGMEM = {MACRO_5};
const char macro_6 [] PROGMEM = {MACRO_6};
const char macro_7 [] PROGMEM = {MACRO_7};
const char macro_8 [] PROGMEM = {MACRO_8};
const char macro_9 [] PROGMEM = {MACRO_9};


/* Macro pointer array */
const char * const macros[] PROGMEM = {
  startup_macro,
  macro_1,
  macro_2,
  macro_3,
  macro_4,
  macro_5,
  macro_6,
  macro_7,
  macro_8,
  macro_9
};

/*** ^^^^^^^^^^^^^ ***/
/*** DO NOT MODIFY ***/

#endif
/***** ^^^^^^^^^^^^^^^^^^^^ *****/
/***** MACRO CONFIG SECTION *****/
/********************************/



/**********************************/
/***** SERIAL PORT MANAGEMENT *****/
/***** vvvvvvvvvvvvvvvvvvvvvv *****/


/***** Serial communications port *****/
/*
#ifdef AR_CDC_SERIAL
  extern Serial_ *arSerial;
  #ifndef DB_SERIAL_PORT
    extern Serial_ *dbSerial;
  #endif
#endif
#ifdef AR_HW_SERIAL
  extern HardwareSerial *arSerial;
  #ifndef DB_SERIAL_PORT
    extern HardwareSerial *dbSerial;
  #endif
#endif
// Note: SoftwareSerial support conflicts with PCINT support
#ifdef AR_SW_SERIAL
  #include <SoftwareSerial.h>
  extern SoftwareSerial *arSerial;
  #ifndef DB_SERIAL_PORT
    extern SoftwareSerial *dbSerial;
  #endif
#endif
*/

/***** Serial debug Port *****/
/*
#ifdef DB_SERIAL_PORT
  #ifdef DB_CDC_SERIAL
    extern Serial_ *dbSerial;
  #endif
  #ifdef DB_HW_SERIAL
    extern HardwareSerial *dbSerial;
  #endif
  // Note: SoftwareSerial support conflicts with PCINT support
  #ifdef DB_SW_SERIAL
    #include <SoftwareSerial.h>
    extern SoftwareSerial *dbSerial;
  #endif
#endif
*/


#ifdef AR_CDC_SERIAL
  Serial_ *arSerial = &(AR_SERIAL_PORT);
  #ifndef DB_SERIAL_PORT
    Serial_ *dbSerial = arSerial;
  #endif
#endif
#ifdef AR_HW_SERIAL
  HardwareSerial *arSerial = &(AR_SERIAL_PORT);
  #ifndef DB_SERIAL_PORT
    HardwareSerial *dbSerial = arSerial;
  #endif
#endif
// Note: SoftwareSerial support conflicts with PCINT support
#ifdef AR_SW_SERIAL
  #include <SoftwareSerial.h>
  SoftwareSerial swArSerial(AR_SW_SERIAL_RX, AR_SW_SERIAL_TX);
  SoftwareSerial *arSerial = &swArSerial;
  #ifndef DB_SERIAL_PORT
    SoftwareSerial *dbSerial = arSerial;
  #endif
#endif


/***** Debug Port *****/

#ifdef DB_SERIAL_PORT
  #ifdef DB_CDC_SERIAL
    Serial_ *dbSerial = &(DB_SERIAL_PORT);
  #endif
  #ifdef DB_HW_SERIAL
    HardwareSerial *dbSerial = &(DB_SERIAL_PORT);
  #endif
  // Note: SoftwareSerial support conflicts with PCINT support
  #ifdef DB_SW_SERIAL
    #include <SoftwareSerial.h>
    SoftwareSerial swDbSerial(DB_SW_SERIAL_RX, DB_SW_SERIAL_TX);
    SoftwareSerial *dbSerial = &swDbSerial;
  #endif
#endif


/***** PARSE BUFFERS *****/
/*
 * Note: Ardiono serial input buffer is 64
 */
// Serial input parsing buffer
static const uint8_t PBSIZE = 128;
char pBuf[PBSIZE];
uint8_t pbPtr = 0;


/***** ^^^^^^^^^^^^^^^^^^^^^^ *****/
/***** SERIAL PORT MANAGEMENT *****/
/**********************************/


/*********************************************/
/***** GPIB COMMAND & STATUS DEFINITIONS *****/
/***** vvvvvvvvvvvvvvvvvvvvvvvvvvvvvvvvv *****/

// Universal Multiline commands (apply to all devices)

#define GC_LLO 0x11
#define GC_DCL 0x14
#define GC_PPU 0x15
#define GC_SPE 0x18
#define GC_SPD 0x19
#define GC_UNL 0x3F
#define GC_TAD 0x40
#define GC_PPE 0x60
#define GC_PPD 0x70
#define GC_UNT 0x5F
// Address commands
#define GC_LAD 0x20
// Addressed commands
#define GC_GTL 0x01
#define GC_SDC 0x04
#define GC_PPC 0x05
#define GC_GET 0x08

/***** GPIB control states *****/
// Controller mode
#define CINI 0x01 // Controller idle state
#define CIDS 0x02 // Controller idle state
#define CCMS 0x03 // Controller command state
#define CTAS 0x04 // Controller talker active state
#define CLAS 0x05 // Controller listner active state
// Listner/device mode
#define DINI 0x06 // Device initialise state
#define DIDS 0x07 // Device idle state
#define DLAS 0x08 // Device listener active (listening/receiving)
#define DTAS 0x09 // Device talker active (sending) state

/***** ^^^^^^^^^^^^^^^^^^^^^^^^^^^^^^^^^ *****/
/***** GPIB COMMAND & STATUS DEFINITIONS *****/
/*********************************************/



/************************************/
/***** COMMON VARIABLES SECTION *****/
/***** vvvvvvvvvvvvvvvvvvvvvvvv *****/

/****** Process status values *****/
#define OK 0
#define ERR 1

/***** Control characters *****/
#define ESC  0x1B   // the USB escape char
#define CR   0xD    // Carriage return
#define LF   0xA    // Newline/linefeed
#define PLUS 0x2B   // '+' character

/***** Controller configuration *****/
/*
 * Default values set for controller mode
 */
union AR488conf{
  struct{
    bool eot_en;      // Enable/disable append EOT char to string received from GPIB bus before sending to USB
    bool eoi;         // Assert EOI on last data char written to GPIB - 0-disable, 1-enable
    uint8_t cmode;    // Controller/device mode (0=unset, 1=device, 2=controller)
    uint8_t caddr;    // Controller address
    uint8_t paddr;    // Primary device address
    uint8_t saddr;    // Secondary device address
    uint8_t eos;      // EOS (end of send to GPIB) characters [0=CRLF, 1=CR, 2=LF, 3=None]
    uint8_t stat;     // Status byte to return in response to a serial poll
    uint8_t amode;    // Auto mode setting (0=off; 1=Prologix; 2=onquery; 3=continuous);
    int rtmo;         // Read timout (read_tmo_ms) in milliseconds - 0-3000 - value depends on instrument
    char eot_ch;      // EOT character to append to USB output when EOI signal detected
    char vstr[48];    // Custom version string
    uint16_t tmbus;   // Delay to allow the bus control/data lines to settle (1-30,000 microseconds)
    uint8_t eor;      // EOR (end of receive from GPIB instrument) characters [0=CRLF, 1=CR, 2=LF, 3=None, 4=LFCR, 5=ETX, 6=CRLF+ETX, 7=SPACE]
    char sname[16];   // Interface short name
    uint32_t serial;  // Serial number
    uint8_t idn;      // Send ID in response to *idn? 0=disable, 1=send name; 2=send name+serial
  };
  uint8_t db[AR_CFG_SIZE];
};

//struct AR488conf AR488;
union AR488conf AR488;


/****** Global variables with volatile values related to controller state *****/

// GPIB control state
uint8_t cstate = 0;

// Verbose mode
bool isVerb = false;

// CR/LF terminated line ready to process
uint8_t lnRdy = 0;

// GPIB data receive flags
//bool isReading = false; // Is a GPIB read in progress?
bool aRead = false;     // GPIB data read in progress
bool rEoi = false;      // Read eoi requested
bool rEbt = false;      // Read with specified terminator character
bool isQuery = false;   // Direct instrument command is a query
uint8_t tranBrk = 0;    // Transmission break on 1=++, 2=EOI, 3=ATN 4=UNL
uint8_t eByte = 0;      // Termination character

// Device mode - send data
bool snd = false;

// Escaped character flag
bool isEsc = false;           // Charcter escaped
bool isPlusEscaped = false;   // Plus escaped
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
void loop() {

/*** Macros ***/
/*
 * Run the startup macro if enabled
 */
#ifdef USE_MACROS
  // Run user macro if flagged
  if (runMacro > 0) {
    execMacro(runMacro);
    runMacro = 0;
  }
#endif

/*** Pin Hooks ***/
/*
 * Not all boards support interrupts or have PCINTs. In this
 * case, use in-loop checking to detect when SRQ and ATN have
 * been signalled
 */
#ifndef USE_INTERRUPTS
  isATN = (digitalRead(ATN)==LOW ? true : false);
  isSRQ = (digitalRead(SRQ)==LOW ? true : false);
#endif

/*** Process the buffer ***/
/* Each received char is passed through parser until an un-escaped
 * CR is encountered. If we have a command then parse and execute.
 * If the line is data (inclding direct instrument commands) then
 * send it to the instrument.
 * NOTE: parseInput() sets lnRdy in serialEvent, readBreak or in the
 * above loop
 * lnRdy=1: process command;
 * lnRdy=2: send data to Gpib
 */

  // lnRdy=1: received a command so execute it...
  if (lnRdy == 1) {
    execCmd(pBuf, pbPtr);
  }

  // Controller mode:
  if (AR488.cmode == 2) {
    // lnRdy=2: received data - send it to the instrument...
    if (lnRdy == 2) {
      sendToInstrument(pBuf, pbPtr);
      // Auto-read data from GPIB bus following any command
      if (AR488.amode == 1) {
        //        delay(10);
        gpibReceiveData();
      }
      // Auto-receive data from GPIB bus following a query command
      if (AR488.amode == 2 && isQuery) {
        //        delay(10);
        gpibReceiveData();
        isQuery = false;
      }
    }

    // Check status of SRQ and SPOLL if asserted
    if (isSRQ && isSrqa) {
      spoll_h(NULL);
      isSRQ = false;
    }

    // Continuous auto-receive data from GPIB bus
    if (AR488.amode == 3 && aRead) gpibReceiveData();
  }

  // Device mode:
  if (AR488.cmode == 1) {
    if (isTO) {
      if (lnRdy == 2) sendToInstrument(pBuf, pbPtr);
    }else if (isRO) {
      lonMode();
    }else{
      if (isATN) attnRequired();
      if (lnRdy == 2) sendToInstrument(pBuf, pbPtr);
    }
  }

  // Reset line ready flag
//  lnRdy = 0;

  // IDN query ?
  if (sendIdn) {
    if (AR488.idn==1) arSerial->println(AR488.sname);
    if (AR488.idn==2) {arSerial->print(AR488.sname);arSerial->print("-");arSerial->println(AR488.serial);}
    sendIdn = false;
  }

  // Check serial buffer
  lnRdy = serialIn_h();

  delayMicroseconds(5);
}
/***** END MAIN LOOP *****/


/***** Initialise the interface *****/
void initAR488() {
  // Set default values ({'\0'} sets version string array to null)
  AR488 = {false, false, 2, 0, 1, 0, 0, 0, 0, 1200, 0, {'\0'}, 0, 0, {'\0'}, 0, 0};
}


/***** Initialise device mode *****/
void initDevice() {
  // Set GPIB control bus to device idle mode
  setGpibControls(DINI);

  // Initialise GPIB data lines (sets to INPUT_PULLUP)
  readGpibDbus();
}


/***** Initialise controller mode *****/
void initController() {
  // Set GPIB control bus to controller idle mode
  setGpibControls(CINI);  // Controller initialise state
  // Initialise GPIB data lines (sets to INPUT_PULLUP)
  readGpibDbus();
  // Assert IFC to signal controller in charge (CIC)
  ifc_h();
}


/***** Serial event handler *****/
/*
 * Note: the Arduino serial buffer is 64 characters long. Characters are stored in
 * this buffer until serialEvent_h() is called. parsedInput() takes a character at
 * a time and places it into the 256 character parse buffer whereupon it is parsed
 * to determine whether a command or data are present.
 * lnRdy=0: terminator not detected yet
 * lnRdy=1: terminator detected, sequence in parse buffer is a ++ command
 * lnRdy=2: terminator detected, sequence in parse buffer is data or direct instrument command
 */
uint8_t serialIn_h() {
  uint8_t bufferStatus = 0;
  // Parse serial input until we have detected a line terminator
  while (arSerial->available() && bufferStatus==0) {   // Parse while characters available and line is not complete
    bufferStatus = parseInput(arSerial->read());
  }

#ifdef DEBUG1
  if (bufferStatus) {
    dbSerial->print(F("BufferStatus: "));
    dbSerial->println(bufferStatus);
  }
#endif

  return bufferStatus;
}


/***** Detect ATN state *****/
/*
 * When interrupts are being used the state is automatically flagged when
 * the ATN interrupt is triggered. Where the interrupt cannot be used the
 * state of the ATN line needs to be checked.
 */
bool isAtnAsserted() {
#ifdef USE_INTERRUPTS
  if (isATN) return true;
#else
  // ATN is LOW when asserted
  if (digitalRead(ATN) == LOW) return true;
#endif
  return false;
}


/*************************************/
/***** Device operation routines *****/
/*************************************/


/***** Unrecognized command *****/
void errBadCmd() {
  arSerial->println(F("Unrecognized command"));
}


/***** Add character to the buffer and parse *****/
uint8_t parseInput(char c) {

  uint8_t r = 0;

  // Read until buffer full (buffer-size - 2 characters)
  if (pbPtr < PBSIZE) {
    if (isVerb) arSerial->print(c);  // Humans like to see what they are typing...
    // Actions on specific characters
    switch (c) {
      // Carriage return or newline? Then process the line
      case CR:
      case LF:
        // If escaped just add to buffer
        if (isEsc) {
          addPbuf(c);
          isEsc = false;
        } else {
          // Carriage return on blank line?
          // Note: for data CR and LF will always be escaped
          if (pbPtr == 0) {
            flushPbuf();
            if (isVerb) showPrompt();
            return 0;
          } else {
            if (isVerb) arSerial->println();  // Move to new line
#ifdef DEBUG1
            dbSerial->print(F("parseInput: Received ")); dbSerial->println(pBuf);
#endif
            // Buffer starts with ++ and contains at least 3 characters - command?
            if (pbPtr>2 && isCmd(pBuf) && !isPlusEscaped) {
              // Exclamation mark (break read loop command)
              if (pBuf[2]==0x21) {
                r = 3;
                flushPbuf();
              // Otherwise flag command received and ready to process
              }else{
                r = 1;
              }
            // Buffer contains *idn? query and interface to respond
            }else if (pbPtr>3 && AR488.idn>0 && isIdnQuery(pBuf)){
              sendIdn = true;
              flushPbuf();
            // Buffer has at least 1 character = instrument data to send to gpib bus
            }else if (pbPtr > 0) {
              r = 2;
            }
            isPlusEscaped = false;
#ifdef DEBUG1
            dbSerial->print(F("R: "));dbSerial->println(r);
#endif
//            return r;
          }
        }
        break;
      case ESC:
        // Handle the escape character
        if (isEsc) {
          // Add character to buffer and cancel escape
          addPbuf(c);
          isEsc = false;
        } else {
          // Set escape flag
          isEsc  = true;  // Set escape flag
        }
        break;
      case PLUS:
        if (isEsc) {
          isEsc = false;
          if (pbPtr < 2) isPlusEscaped = true;
        }
        addPbuf(c);
//        if (isVerb) arSerial->print(c);
        break;
      // Something else?
      default: // any char other than defined above
//        if (isVerb) arSerial->print(c);  // Humans like to see what they are typing...
        // Buffer contains '++' (start of command). Stop sending data to serial port by halting GPIB receive.
        addPbuf(c);
        isEsc = false;
    }
  }
  if (pbPtr >= PBSIZE) {
    if (isCmd(pBuf) && !r) {  // Command without terminator and buffer full
      if (isVerb) {
        arSerial->println(F("ERROR - Command buffer overflow!"));
      }
      flushPbuf();
    }else{  // Buffer contains data and is full, so process the buffer (send data via GPIB)
      dataBufferFull = true;
      r = 2;
    }
  }
  return r;
}


/***** Is this a command? *****/
bool isCmd(char *buffr) {
  if (buffr[0] == PLUS && buffr[1] == PLUS) {
#ifdef DEBUG1
    dbSerial->println(F("isCmd: Command detected."));
#endif
    return true;
  }
  return false;
}


/***** Is this an *idn? query? *****/
bool isIdnQuery(char *buffr) {
  // Check for upper or lower case *idn?
  if (strncasecmp(buffr, "*idn?", 5)==0) {
#ifdef DEBUG1
    dbSerial->println(F("isIdnQuery: Detected IDN query."));
#endif
    return true;
  }
  return false;
}


/***** ++read command detected? *****/
bool isRead(char *buffr) {
  char cmd[4];
  // Copy 2nd to 5th character
  for (int i = 2; i < 6; i++) {
    cmd[i - 2] = buffr[i];
  }
  // Compare with 'read'
  if (strncmp(cmd, "read", 4) == 0) return true;
  return false;
}


/***** Add character to the buffer *****/
void addPbuf(char c) {
  pBuf[pbPtr] = c;
  pbPtr++;
}
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

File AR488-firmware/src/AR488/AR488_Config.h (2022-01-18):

#ifndef AR488_CONFIG_H
#define AR488_CONFIG_H

#include <Arduino.h>

/*********************************************/
/***** AR488 GLOBAL CONFIGURATION HEADER *****/
/***** vvvvvvvvvvvvvvvvvvvvvvvvvvvvvvvvv *****/


/***** Firmware version *****/
#define FWVER "AR488 GPIB controller, ver. 0.49.14, 02/03/2021"


/***** BOARD CONFIGURATION *****/
/*
 * Platform will be selected automatically based on
 * Arduino definition.
 * Only ONE board/layout should be selected per platform
 * Only ONE Serial port can be used to receive output
 */


/*** Custom layout ***/
/*
 * Uncomment to use custom board layout
 */
//#define AR488_CUSTOM

/*
 * Configure the appropriate board/layout section
 * below as required
 */
#ifdef AR488_CUSTOM
  /* Board layout */
  /*
   * Define board layout in the AR488 CUSTOM LAYOUT
   * section below
   */
  /* Serial ports */
  #define AR_HW_SERIAL
  #define AR_SERIAL_PORT Serial
  //#define AR_SERIAL_PORT Serial1
  //#define AR_SERIAL_PORT Serial2
  //#define AR_SERIAL_PORT Serial3
  //#define AR_CDC_SERIAL
  //#define AR_SW_SERIAL

/*** UNO and NANO boards ***/
#elif __AVR_ATmega328P__
  /* Board/layout selection */
  #define AR488_UNO
  //#define AR488_NANO
  /*** Serial ports ***/
  //Select HardwareSerial or SoftwareSerial (default = HardwareSerial) ***/
  // The UNO/NANO default hardware port is 'Serial'
  // (Comment out #define AR_HW_SERIAL if using SoftwareSerial)
  #define AR_HW_SERIAL
  #ifdef AR_HW_SERIAL
    #define AR_SERIAL_PORT Serial
  #else
    // Select software serial port
    #define AR_SW_SERIAL
  #endif

/*** MEGA 32U4 based boards (Micro, Leonardo) ***/
#elif __AVR_ATmega32U4__
  /*** Board/layout selection ***/
  #define AR488_MEGA32U4_MICRO  // Artag's design for Micro board
  //#define AR488_MEGA32U4_LR3  // Leonardo R3 (same pin layout as Uno)
  /*** Serial ports ***/
  // By default the CDC serial port is used
  // Comment out #define AR_CDC_SERIAL if using RXI, TXO pins
  #define AR_CDC_SERIAL
  #ifdef AR_CDC_SERIAL
    // The Mega 32u4 default port is a virtual USB CDC port named 'Serial'
    #define AR_SERIAL_PORT Serial
  #else
    // Use hardware port Serial1
    #define AR_HW_SERIAL
    #define AR_SERIAL_PORT Serial1
  #endif
  
/*** MEGA 2560 board ***/
#elif __AVR_ATmega2560__
  /*** Board/layout selection ***/
  #define AR488_MEGA2560_D
  //#define AR488_MEGA2560_E1
  //#define AR488_MEGA2560_E2
  /*** Serial ports ***/
  // Mega 2560 supports Serial, Serial1, Serial2, Serial3. Since the pins 
  // associated with Serial2 are used in the default pin layout, Serial2
  // is unavailable. The default port is 'Serial'. Choose ONE port only.
/*  
  // and associated SERIALEVENT definition
*/
  #define AR_HW_SERIAL
  #define AR_SERIAL_PORT Serial
  //#define AR_SERIAL_PORT Serial1
  //#define AR_SERIAL_PORT Serial3

#endif  // Board/layout selection


/***** Software Serial Support *****/
/*
 * Configure the SoftwareSerial TX/RX pins and baud rate here
 * Note: SoftwareSerial support conflicts with PCINT support
 * When using SoftwareSerial, disable USE_INTERRUPTS.
 */
#ifdef AR_SW_SERIAL
  #define AR_SW_SERIAL_RX 53
  #define AR_SW_SERIAL_TX 51
  #define AR_SW_SERIAL_BAUD 57600
#else
  #define AR_SERIAL_BAUD 115200
#endif
/*
 * Note: SoftwareSerial reliable only up to a MAX of 57600 baud only
 */


/***** Pin State Detection *****/
/*
 * With UNO. NANO and MEGA boards with pre-defined layouts,
 * USE_INTERRUPTS can and should be used.
 * With the AR488_CUSTOM layout and unknown boards, USE_INTERRUPTS must  
 * be commented out. Interrupts are used on pre-defined AVR board layouts 
 * and will respond faster, however in-loop checking for state of pin states
 * can be supported with any board layout.
 */
#ifdef __AVR__
  // For supported boards use interrupt handlers
  #if defined (AR488_UNO) || defined (AR488_NANO) || defined (AR488_MEGA2560) || defined (AR488_MEGA32U4)
    #ifndef AR488_CUSTOM
      #define USE_INTERRUPTS
    #endif
  #endif
#endif


/***** Enable Macros *****/
/*
 * Uncomment to enable macro support. The Startup macro allows the
 * interface to be configured at startup. Macros 1 - 9 can be
 * used to execute a sequence of commands with a single command
 * i.e, ++macro n, where n is the number of the macro
 * 
 * USE_MACROS must be enabled to enable the macro feature including 
 * MACRO_0 (the startup macro). RUN_STARTUP must be uncommented to 
 * run the startup macro when the interface boots up
 */
//#define USE_MACROS    // Enable the macro feature
//#define RUN_STARTUP   // Run MACRO_0 (the startup macro)


/***** Enable SN7516x chips *****/
/*
 * Uncomment to enable the use of SN7516x GPIB tranceiver ICs.
 * This will require the use of an additional GPIO pin to control
 * the read and write modes of the ICs.
 */
#define SN7516X
#ifdef SN7516X
  #define SN7516X_TE 13
  #define SN7516X_DC 5
//  #define SN7516X_SC 3
#endif
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

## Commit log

2022-01-18 PCB Tune Length
    [AR488-Bluetooth-B_Cu.gbr, AR488-Bluetooth-B_Mask.gbr, AR488-Bluetooth-B_Silkscreen.gbr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]
2022-01-31 Correct the design and add the battery circuit. No Gerber is generated
    [AR488-Bluetooth-BOM.csv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]
2022-01-31 Update the images and connect shield to GND
    [AR488-Bluetooth.kicad_pcb, AR488-Bluetooth.kicad_sch]
2022-02-14 Update typo in the schematic
    [AR488-Bluetooth-B_Cu.gbr, AR488-Bluetooth-B_Mask.gbr, AR488-Bluetooth-B_Silkscreen.gbr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]
